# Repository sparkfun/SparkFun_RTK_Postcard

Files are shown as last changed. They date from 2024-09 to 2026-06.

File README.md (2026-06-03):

SparkFun RTK Postcard
========================================

SparkFun RTK Postcard (https://www.sparkfun.com/sparkfun-rtk-postcard.html)

[*SparkFun RTK Postcard (GPS-26916)*](https://www.sparkfun.com/sparkfun-rtk-postcard.html)

Designed and manufactured in Boulder, CO USA, the [SparkFun RTK Postcard](https://www.sparkfun.com/sparkfun-rtk-postcard.html) is a compact development board for your high-precision positioning and navigation needs. This board combines the Quectel LG290P GNSS RTK receiver with an Espressif ESP32-PICO-MINI-02 MCU module, running our latest [RTK Everywhere firmware](https://github.com/sparkfun/SparkFun_RTK_Everywhere_Firmware). The ESP32 provides the SparkFun Postcard with WiFi and Bluetooth&trade; connectivity to operate as an NTRIP caster or client. Meanwhile, the 4-pin locking JST-GH connector allows users to transmit or receive RTCMv3 messages for RTK corrections from a local base station.

- The LG290P module is a quad-band, multi-constellation, high-precision, RTK GNSS receiver. The module can simultaneously receive signals from the `L1`, `L2`, `L5`, and `L6`/`E6` frequency bands of the GPS, GLONASS, Galileo, BDS, QZSS, and NavIC GNSS constellations. In addition, the module supports SBAS augmentation systems (WASS, EGNOS, BDSBAS, MSAS, GAGAN, and SDCM), PPP services* (BDS PPP-B2b, QZSS CLAS, MADOCA-PPP, and Galileo HAS), RTCM, and RTK corrections for precision navigation with a fast convergence time and reliable performance. Connect with ease using a variety of interfaces, including UART, SPI*, and I2C*. 

- The ESP32-PICO-MINI-02 is a powerful MCU module with WiFi, Bluetooth&trade;, and BLE connectivity and comes integrated with 8MB SPI flash, 2MB SPI Pseudo static RAM (PSRAM), and a 40 MHz crystal oscillator. The ESP32 microcontroller itself features two CPU cores that can be individually controlled, with an adjustable clock frequency between 80 - 240MHz and a low-power co-processor for minor tasks, such as monitoring peripherals. It supports a range of peripherals including an SD card interface, capacitive touch sensors, ADC, DAC, Two-Wire Automotive Interface (TWAI), Ethernet, high-speed SPI, UART, I2S, I2C, etc.

With the [RTK Everywhere firmware](https://github.com/sparkfun/SparkFun_RTK_Everywhere_Firmware) that comes pre-loaded, users can seamlessly operate the RTK Postcard as a base station or rover. These modes also offer additional functions, based on the available, wireless communication options:

- The RTK Postcard can transmit or receive RTCMv3 messages locally by connecting one of our [SiK Telemetry radios](https://www.sparkfun.com/sik-telemetry-radio-v3-915mhz-100mw.html).
- Through WiFi or Bluetooth&trade;, the RTK Postcard can also function as an NTRIP caster or client.
- The RTK Postcard can transmit NMEA messages to a [graphical information software (GIS)](https://docs.sparkfun.com/SparkFun_RTK_Everywhere_Firmware/gis_software_android/) apps on any mobile device when paired as a Bluetooth&trade; device.

In addition to the RTK Postcard, we created the [Portability Shield](https://www.sparkfun.com/sparkfun-portability-shield.html) for the convenience of users. Simply connecting these products, provides a 1.3” OLED display and a five-way button to navigate the configuration settings and display PNT data; a microSD card slot for data logging; and a LiPo battery charger with a fuel gauge to take the RTK Postcard *"on-the-go"*. All of these will operate plug-and-play without the need for new code.

> [!NOTE]
> The [RTK Everywhere firmware](https://github.com/sparkfun/SparkFun_RTK_Everywhere_Firmware) is open-source, so users can obtain, check, and even modify the device's functionality. This allows for easier feature expansion, bug maintenance, and longer device longevity.

> [!NOTE]
> `*`: Feature is still under development

> [!IMPORTANT]
> - Currently, only the UART interface is supported by the LG290P module.
> - Additionally, the corrections for some of the PPP services may not be implemented yet.

Documentation
--------------

* **[Hookup Guide (mkdocs)](http://docs.sparkfun.com/SparkFun_RTK_Postcard/)** - The hookup guide for the SparkFun RTK Postcard hosted by GitHub pages.<br>
   
* [User Manual - RTK Everywhere Firmware](https://docs.sparkfun.com/SparkFun_RTK_Everywhere_Firmware/) - Documentation for the [RTK Everywhere firmware](https://github.com/sparkfun/SparkFun_RTK_Everywhere_Firmware)
* [SparkFun LG290P GNSS Arduino Library](https://github.com/sparkfun/SparkFun_LG290P_GNSS_Arduino_Library) - An Arduino library for the LG290P and LGx80P GNSS modules

*Need to download or print our hookup guide?*

* [Print *(Print to PDF)* from Single-Page View](http://docs.sparkfun.com/SparkFun_RTK_Postcard/print_view)

Repository Contents
-------------------

* **[/docs](/docs/)** - Online documentation files
    * [assets](/docs/assets/) - Assets files
        * [3d_model](/docs/assets/3d_model/) - Files for the 3D models
            * [3D CAD Model](/docs/assets/3d_model/cad_model.step) (.step)
        * [board_files](/docs/assets/board_files/) - Files for the product design
            * [KiCad Design Files](/docs/assets/board_files/kicad_files.zip) (.zip)
            * [Schematic](/docs/assets/board_files/schematic.pdf) (.pdf)
            * [Dimensions](/docs/assets/board_files/dimensions.pdf) (.pdf)
        * [component_documentation](/docs/assets/component_documentation/) - Datasheets for hardware components
        * [img/hookup_guide/](/docs/assets/img/hookup_guide/) - Images for hookup guide documentation
* **[/Enclosure](/Enclosure/)** - CAD model for an enclosure
* **[/Hardware](/Hardware/)** - Hardware design files (.brd, .sch)
  * **[/Production](/Production/)** - Production files

Product Variants
----------------

- LG290P Variants
  - [GPS-26916](https://www.sparkfun.com/sparkfun-rtk-postcard.html) - v1.0, Initial Release
  - [GPS-26620](https://www.sparkfun.com/sparkfun-quadband-gnss-rtk-breakout-lg290p-qwiic.html) - SparkFun Quadband GNSS RTK Breakout - LG290P (Qwiic) *(w/o ESP32)*
- [GPS-28019](https://www.sparkfun.com/products/28019) - SparkFun Quadband GNSS RTK Breakout - LG580P (Qwiic)

Version History
---------------

* [v10](https://github.com/sparkfun/SparkFun_RTK_Postcard/releases/tag/v10) - Initial Release

License Information
-------------------

This product is ***open source***!

Please review the [`LICENSE.md`](./LICENSE.md) file for license information.

If you have any questions or concerns about licensing, please contact technical support on our [SparkFun forums](https://community.sparkfun.com/).

Distributed as-is; no warranty is given.

- Your friends at SparkFun.

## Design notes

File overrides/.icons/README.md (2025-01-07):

.icons directory
====================
This folder should contain branding logos for the product documentation

## General Images
- `sfe-logo.svg` - SparkFun flame logo
- `kicad-primary.svg` - Full KiCad logo

## Directory
- `logo` - Other available logos

## SVG Optimizer
- [Remove meta data from svg](https://jakearchibald.github.io/svgomg/)

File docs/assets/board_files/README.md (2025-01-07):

board_files directory
====================

1. A `dimensions.png` file containing the board's measurements.
2. A `schematic.pdf` file containing the board's schematics.
3. A `*_files.zip` file containing the hardware design files.
	- The file name is based on the CAD software used to design the hardware, as described below:
		- An `kicad_files.zip` file containing the KiCad design files.
		- A `kicad_files.zip` file containing the KiCad design files.
4. A `graphical_datasheet.pdf` containing a summary of the board's technical specifications.

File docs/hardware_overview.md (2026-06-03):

---
icon: material/cog
---

## :material-folder-cog: Design Files
The SparkFun RTK Postcard board's dimensions, pin layout, and connectors are similar to our very popular [SparkFun GPS-RTK-SMA Breakout - ZED-F9P (Qwiic)](https://www.sparkfun.com/sparkfun-gps-rtk-sma-breakout-zed-f9p-qwiic.html) and [SparkFun Quadband GNSS RTK Breakout - LG290P (Qwiic)](https://www.sparkfun.com/sparkfun-quadband-gnss-rtk-breakout-lg290p-qwiic.html). The board features multiple UART ports, which are accessible through the USB-C connector, [PTH](https://en.wikipedia.org/wiki/Through-hole_technology "Plated Through Holes") pins, and 4-pin locking JST connector. Users can also interface with the board through the 19 [PTH](https://en.wikipedia.org/wiki/Through-hole_technology "Plated Through Holes") pins that are broken out around the edge of the board. For the GNSS antenna, an SMA antenna connector is provided on the edge of the board; additionally, users can rework the board to utilize the u.fl connector instead. We also provide two 4-pin JST Qwiic connectors for future use, to operate the board as a peripheral device.

<!-- Import the component -->
<script type="module" src="https://ajax.googleapis.com/ajax/libs/model-viewer/3.5.0/model-viewer.min.js"></script>

<div class="grid cards desc" markdown>

-   :kicad-primary:{ .enlarge-logo } Design Files

	---

	- :fontawesome-solid-file-pdf: [Schematic](./assets/board_files/schematic.pdf)
	- :material-folder-zip: [KiCad Files](./assets/board_files/kicad_files.zip)
	- :material-rotate-3d: STEP Files
		- :material-developer-board: [RTK Postcard](./assets/3d_model/cad_model.step)
		- :material-cube-outline: [Enclosure](./assets/3d_model/enclosure/enclosure.step)
	<!-- - :material-rotate-3d: [STEP File](./assets/3d_model/cad_model.step) -->
	- :fontawesome-solid-file-pdf: [Board Dimensions](./assets/board_files/dimensions.pdf):
		- 1.70" x 1.70" (43.2mm x 43.2mm)
		- Four mounting holes:
			- 4-40 screw compatible

-   <!-- Boxes in tabs -->

	=== "3D Model"
		???+ example "RTK Postcard"
			<article style="text-align: center;" markdown>
			<model-viewer src="../assets/3d_model/web_model.glb" camera-controls poster="../assets/3d_model/poster.png" tone-mapping="neutral" shadow-intensity="1.3" exposure="0.85" shadow-softness="0.45" environment-image="legacy" camera-orbit="39.22deg 54.28deg 0.1361m" field-of-view="29deg" style="width: 100%; height: 450px;">
			</model-viewer>

			[Download the `*.step` File](./assets/3d_model/cad_model.step "Click download"){ .md-button .md-button--primary width="250px" }

			</article>

		??? example "Enclosure"
			<article style="text-align: center;" markdown>
			<model-viewer src="../assets/3d_model/enclosure/web_model.glb" camera-controls poster="../assets/3d_model/enclosure/poster.png" tone-mapping="neutral" shadow-intensity="0.9" environment-image="legacy" exposure="0.6" shadow-softness="0.7" camera-orbit="-756.1deg 62.5deg 140.1m" field-of-view="30deg" style="width: 100%; height: 450px;">
			</model-viewer>

			[Download the `*.step` File](./assets/3d_model/enclosure/enclosure.step "Click download"){ .md-button .md-button--primary width="250px" }

			</article>

		??? tip "Manipulate 3D Model"
			<article style="text-align: center;" markdown>

			| Controls       | Mouse                    | Touchscreen    |
			| :------------- | :----------------------: | :------------: |
			| Zoom           | Scroll Wheel             | 2-Finger Pinch |
			| Rotate         | ++"Left-Click"++ & Drag  | 1-Finger Drag  |
			| Move/Translate | ++"Right-Click"++ & Drag | 2-Finger Drag  |

			</article>

	=== "Dimensions"
		<article style="text-align: center;" markdown>
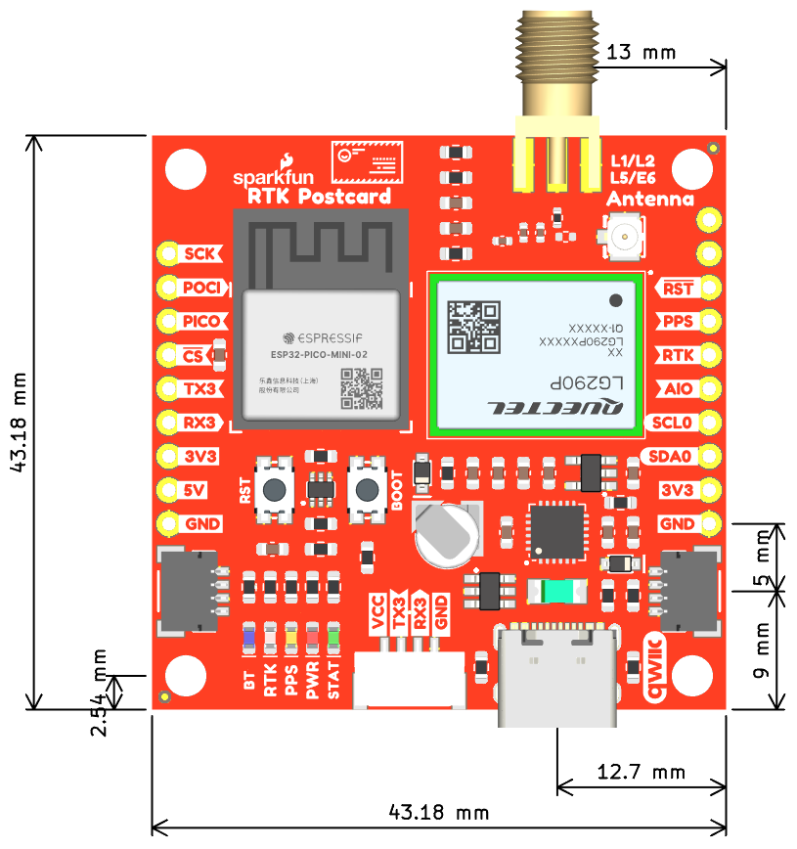
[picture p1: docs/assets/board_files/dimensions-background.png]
Board Dimensions
		
		<figcaption markdown>Dimensions of the RTK Postcard.</figcaption>
		</article>

		??? tip "Need more measurements?"
			For more information about the board's dimensions, users can download the [KiCad files](./assets/board_files/kicad_files.zip) for this board. These files can be opened in KiCad and additional measurements can be made with the measuring tool.

			!!! info ":octicons-download-16:{ .heart } KiCad - Free Download!"
				KiCad is free, open-source [CAD]("computer-aided design") program for electronics. Click on the button below to download their software. *(\*Users can find out more information about KiCad from their [website](https://www.kicad.org/).)*

				<article style="text-align: center;" markdown>
				[Download :kicad-primary:{ .enlarge-logo }](https://www.kicad.org/download/ "Go to downloads page"){ .md-button .md-button--primary width="250px" }
				</article>

			??? info ":straight_ruler: Measuring Tool"
				This video demonstrates how to utilize the dimensions tool in KiCad, to include additional measurements:

				<article class="video-500px" style="text-align: center; margin: auto;" markdown>
				<iframe src="https://www.youtube.com/embed/-eXuD8pkCYw" title="KiCad Dimension Tool" frameborder="0" allow="accelerometer; autoplay; clipboard-write; encrypted-media; gyroscope; picture-in-picture" allowfullscreen></iframe>
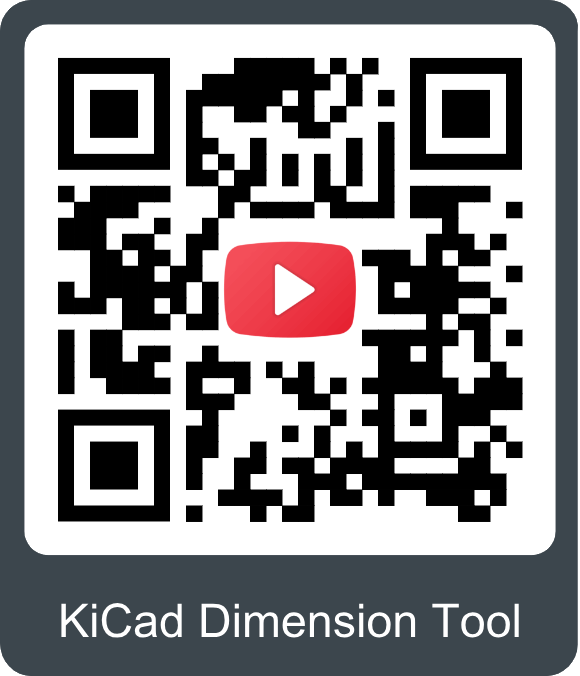
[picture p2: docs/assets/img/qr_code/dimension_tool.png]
QR code to play video
				
				</article>

</div>

## USB-C Connector
The USB connector is provided to power the board and communicate with either the LG290P GNSS receiver or ESP32 microcontroller. For most users, it will be the primary method for interfacing with the RL Postcard.

<figure markdown>
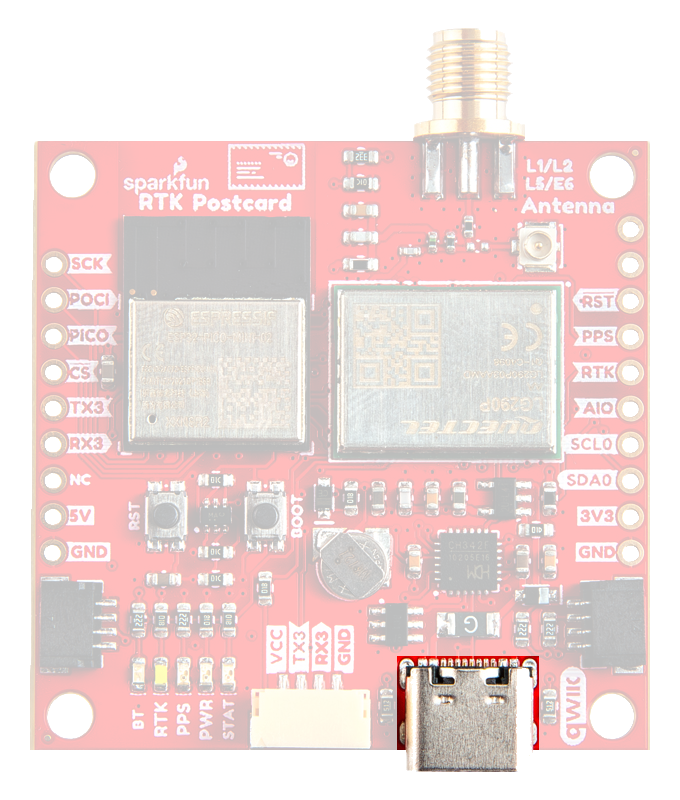
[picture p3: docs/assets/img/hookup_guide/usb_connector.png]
USB-C Connector

<figcaption markdown>USB-C connector on the RTK Postcard.</figcaption>
</figure>

### CH342 Dual UART Converter
The CH342 serial-to-USB converter allows users to interface with the `UART1` port of the LG290P GNSS module and `UART0` port of the ESP32-Pico module through the USB-C connector. To utilize the CH342, users may need to install a USB driver, which can be downloaded from the [manufacturer website](https://www.wch-ic.com/search?q=CH342&t=downloads).

??? tip "Tip - USB Drivers"
	<div class="grid cards" align="center" markdown>

	-   :material-microsoft-windows: **Windows**

		---

		[:octicons-download-16:{ .heart } Download Page for `CH343SER.EXE`](https://www.wch-ic.com/downloads/CH343SER_EXE.html){ .md-button .md-button--primary target="blank" }

	-   :material-apple: **MacOS**

		---

		[:octicons-download-16:{ .heart } Download Page for `CH341SER_MAC.ZIP`](https://www.wch-ic.com/downloads/CH34XSER_MAC_ZIP.html){ .md-button .md-button--primary target="blank" }

	</div>

	!!! info "Linux"
		A USB driver is not required for Linux based operating systems.

<figure markdown>
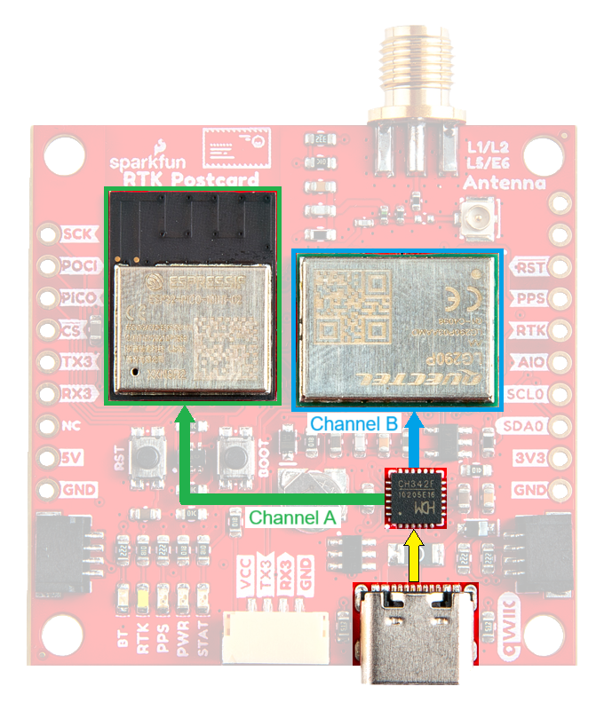
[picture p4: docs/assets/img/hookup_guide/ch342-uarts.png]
CH342 UART Channels

<figcaption markdown>The `UART` channels of the CH342 serial-to-USB converter.</figcaption>
</figure>

Once the USB driver is installed, two virtual `COM` ports will be emulated and can be utilized as standard `COM` ports to access the modules:

- **ESP32** - Users should select `COM` port labeled with `Channel A` *(often the lower enumeration)*.
- **LG290P** - Users should select `COM` port labeled with `Channel B` *(often the higher enumeration)*.

	???+ info "UART Settings"
		<div class="grid cards" markdown>

		- **ESP32**

			---

			With the [RTK Everywhere firmware](https://github.com/sparkfun/SparkFun_RTK_Everywhere_Firmware), the `UART0` port of the ESP32 is configured with the following settings:

			- Baudrate: **115200bps**
			- Data Bits: 8
			- Parity: No
			- Stop Bits: 1

		- **LG290P**

			---

			With the [RTK Everywhere firmware](https://github.com/sparkfun/SparkFun_RTK_Everywhere_Firmware), the `UART2` port of the LG290P is configured with the following settings:

			- Baudrate: **460800bps**
			- Data Bits: 8
			- Parity: No
			- Stop Bits: 1

			??? info "Default Configuration"
				The UART ports of the LG290P are configured with the following default settings:

				- Baudrate: **460800bps**
				- Data Bits: 8
				- Parity: No
				- Stop Bits: 1
				- Flow Control: None
				- Protocols:
					- `NMEA 0183`
					- `RTCM 3.x`

		</div>

## Power
The RTK Postcard only requires **3.3V** to power the board's primary components. The simplest method to power the board is through the USB-C connector. Alternatively, the board can also be powered through the other connectors and [PTH](https://en.wikipedia.org/wiki/Through-hole_technology "Plated Through Holes") pins.

<figure markdown>
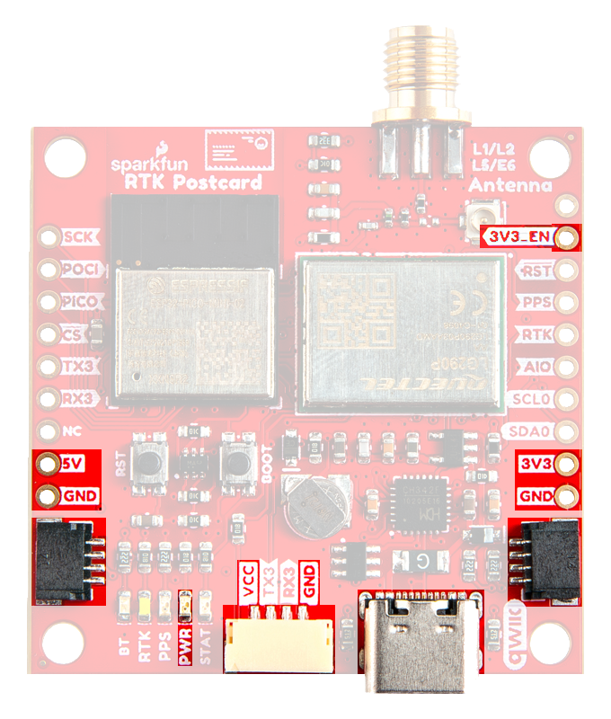
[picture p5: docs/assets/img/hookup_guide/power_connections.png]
Power connections

<figcaption markdown>RTK Postcard's power connections.</figcaption>
</figure>

Below, is a general summary of the power circuitry for the board:

<div class="annotate" markdown>

- **`5V`** - The voltage from the USB-C connector, usually **5V**.
	- Can be utilized as the primary power source for the entire board.
	- When connected to the [Portability Shield](https://www.sparkfun.com/sparkfun-portability-shield.html), this pin used to provide power between the boards. (1)
- **`3V3`** - 3.3V power rail, which powers the ESP32 Pico-Mini module, LG290P GNSS module, backup battery, and LEDs.
	- Power can also be distributed to/from any of the JST connectors *(Qwiic or `UART3`)* or the `3V3` PTH pin.
		- For power that is supplied through these connections, the LG290P has the tightest voltage supply requirement of **3.15–3.45V**.
	- A regulated **3.3V** is supplied by the [RT9080](./assets/component_documentation/DS9080.pdf), when powered from the `5V` PTH pin or USB connector
		- Input Voltage Range: **3.0 to 5.5V** (2)
		- The RT9080 LDO regulator can source up to 600mA.
- **`3V3_EN`** - Controls the power output form the RT9080 voltage regulator.
	- By default, the pin is pulled-up to 5V and to enable the RT9080 output voltage.
- **`VCC`** - The voltage from the locking JST-GH connector, which is controlled by the `VSEL` jumper (3).
	- Used to power an external radio to send or receive RTK corrections.
- **`GND`** - The common ground or the 0V reference for the voltage supplies.

</div>

1. !!! abstract "Details"

		When **5V** is provided to the RTK Postcard, it will supply power to the Portability Shield and charge the LiPo battery *(if connected)*. To operate properly when charging the battery, the power switch behind the OLED display of the Portability Shield should be in the `Off` position.

		When powered by a LiPo battery, users must toggle the power switch behind the OLED display of the Portability Shield to the `On` position. This will allow the battery power to be provided to the RTK Postcard through the **`5V`** pin; and then to its [RT9080 LDO](./assets/component_documentation/DS9080.pdf).

		Protection diodes are utilized on the boards to independently prevent current feedback and protect the power sources from each other.

1. !!! warning "Brown Out Voltage"

		The supply voltage of a LiPo battery will decrease as it is drained. However, before the battery can reach its critical UVLO threshold *(~2.8V)*, the LG290 GNSS module with begin to brown out from an in-use supply voltage of **3.05-3.10V** from a battery.

	!!! warning "Battery Capacity"

		When selecting a LiPo battery for any combination of the RTK Postcard, Portability Shield, and/or connected radio, users should be aware of the peak current draw of their setup. In theory, most standard LiPo batteries have a maximum discharge rate of 1C *(based on the battery capacity)*.

		$$
		1C = \frac{(1 * Capacity)}{hour}
		$$

		However, as a battery ages, users may find the effective capacity and discharge rate to degrade to 80% of its original specifications.

		!!! example

			For example, a LiPo battery with a **400mAh capacity** will have a maximum **discharge rate of 400mA**. However, over time, users may notice its effective use diminish to 320mAh and 320mA respectively.

1. By default, the `VSEL` jumper is configured to utilize the **3.3V** power rail; however, it can be connected to the 5V power rail instead.

	!!! warning "Portability Shield"

		When utilizing the 5V power rail of the RTK Postcard, power may be supplied from the LiPo battery from the Portability Shield. This should be taken into consideration when connecting an external radio for RTK corrections.

!!! info
	For more details, users can reference the [schematic](./assets/board_files/schematic.pdf) and the datasheets of the individual components on the board.

!!! tip "Portability Shield"
	When used in conjunction with the [Portability Shield](https://www.sparkfun.com/sparkfun-portability-shield.html), users should be aware of the following:

	- To charge the battery, users must provide adequate power through the `5V` pin. This is most easily done by powering the boards from the USB-C connector.
	- When operating the boards with the battery power, users must ensure that the switch behind the OLED display is in the `On` position. This will allow the battery power to feedback to the RTK Postcard through the `5V` pin; and over to the RT9080 LDO to provide a regulated 3.3V to its primary components.

### Backup Battery
While charged, the backup battery allows the GNSS module to hot/warm start with valid ephemeris data (time and GNSS orbital trajectories) that was stored.

**Time to First Fix:**

- Cold Start: 28s
- Warm Start: 28s
- Hot Start: 1.7s

## :espressif-logo:&nbsp; ESP32 Pico-Mini
The brains of the RTK Postcard is an [ESP32 Pico-Mini module](https://espressif.com/sites/default/files/documentation/esp32-pico-mini-02_datasheet_en.pdf). The Espressif series of ESP32 modules are a versatile, compact MCU modules with WiFi, BT, and BLE capabilities that target a wide variety of applications. At the core of the ESP32 Pico-Mini module is the ESP32-PICO-V3-02, a System-in-Package device, along with an integrated 8 MB SPI flash, 2 MB SPI PSRAM, and 40 MHz oscillator.

<figure markdown>
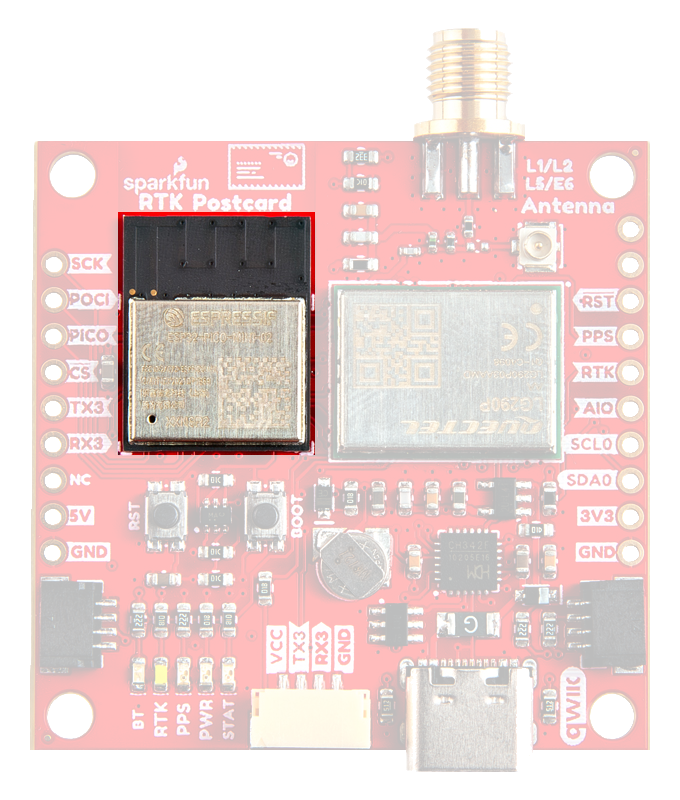
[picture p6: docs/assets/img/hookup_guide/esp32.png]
ESP32 Pico-Mini module

<figcaption markdown>The ESP32 Pico-Mini module on the RTK Postcard.</figcaption>
</figure>

??? info "General Features"
	<div class="grid" markdown>

	<div markdown>

	- Electrical Characteristics:
		- Operating Voltage: **3.0 - 3.6V**
		- Current Consumption:
			- RF Operation: 368mA *(peak)*
			- Normal Operation: 20-31mA
			- Light-Sleep: 0.8mA
			- Deep-Sleep: 5µA
	- Xtensa® Dual-Core 32-bit LX6 Microprocessor *(up to 240MHz)*
		- 448KB of ROM and 520KB SRAM
		- 8MB SPI Flash
		- 2MB PSRAM
		- 16KB SRAM in RTC
	- Operating Temperature: -40 to 85&deg;C

	</div>

	<div markdown>

	- PCB antenna
	- Wi­F 802.11b/g/n
		- Bit Rate: up to 150Mbps *(802.11n)*
		- Frequency Range: 2412 - 2484MHz
	- Bluetooth
		- Bluetooth v4.2 Specification:
			- BR/EDR
			- Bluetooth LE
		- Transmitter Class: 1, 2, and 3
	- 27 GPIO *(including strapping pins)*
		-
	- Supported Peripherals:
		- SD card, UART, SPI, SDIO, I2C, LED PWM, Motor PWM, I2S, IR, pulse counter, GPIO, capacitive touch sensor, ADC, DAC, TWAI® (compatible with ISO 11898-1, i.e. CAN Specification 2.0), Ethernet MAC

	</div>

	</div>

???+ warning
	Users should be aware of the following nuances and details of this microcontroller

	- The ESP32 Pico-Mini is only compatible with **2.4GHz WiFi** networks; it will not work on the 5GHz bands.
	- For details on the boot mode configuration, please refer to [section **3.3 Strapping Pins**](./assets/component_documentation/esp32_datasheet_en.pdf#8) of the ESP32 SoC datasheet.

???+ info "RTK Everywhere Firmware"
	The RTK Postcard comes pre-programmed with latest version of our [RTK Everywhere firmware](https://github.com/sparkfun/SparkFun_RTK_Everywhere_Firmware). However, users are free to reprogram the board as they see fit. For more details about the RTK Everywhere firmware, users can refer to the [user manual](http://docs.sparkfun.com/SparkFun_RTK_Everywhere_Firmware/).

???+ tip "Firmware Download Mode"
	Users can manually force the board into the <a href="https://docs.espressif.com/projects/esptool/en/latest/esp32/advanced-topics/boot-mode-selection.html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">serial bootloader</a> with the ++"BOOT"++ button. Please, refer to the [**Boot Button** section](#boot-button) below for more information.

??? info "Power Modes"
	The ESP32 Pico-Mini module has various power modes:

	- **Active** -  The chip radio is powered on. The chip can receive, transmit, or listen.
	- **Modem Sleep** - The CPU is operational and the clock is configurable. The Wi-Fi/Bluetooth	baseband and radio are disabled.
	- **Light Sleep** - The CPU is paused. The RTC memory and RTC peripherals, as well as the ULP	coprocessor are running.
	- **Deep Sleep** - Only the RTC memory and RTC peripherals are powered on. The ULP coprocessor is functional.
	- **Hibernation** - Only one RTC timer on the slow clock and certain RTC GPIO	active.
	- **Off** - Chip is powered off.

	*For more information on the power management of the ESP32 Pico-Mini module, pleaser refer to **Section 4.4** and **Tables: 8 and 9** of the [ESP32 Pico-Mini module datasheet](./assets/component_documentation/esp32-pico-mini-02_datasheet_en.pdf).*

### Peripherals and I/O Pins
The ESP32 Pico-Mini module features *27 multifunctional GPIO* pins, of which, **11 I/O pins** broken out into [PTH](https://en.wikipedia.org/wiki/Through-hole_technology "Plated Through Holes") pins on the RTK Postcard. Meanwhile, others are utilized to interface with the LG290P GNSS receiver or other components on the board *(i.e. USB connector, Qwiic connector, etc.)*. All of the RTK Postcard [PTH](https://en.wikipedia.org/wiki/Through-hole_technology "Plated Through Holes") pins have a .1" pitch spacing for standard headers and their pin layout is compatible with our [Portability Shield](https://www.sparkfun.com/sparkfun-portability-shield.html).

<div class="grid" markdown>

<div markdown>

<figure markdown>
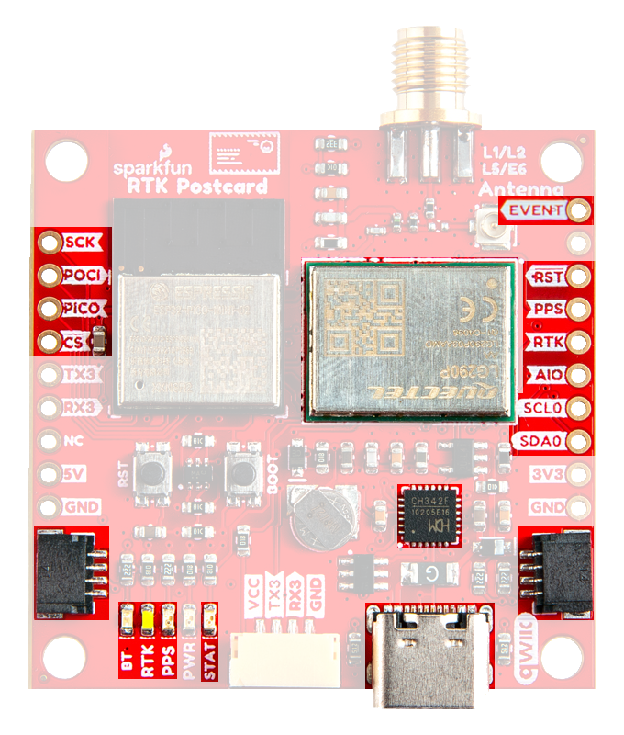
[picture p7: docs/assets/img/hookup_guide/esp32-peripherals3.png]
Peripherals interfaces

<figcaption markdown>The peripheral interfaces and I/O pins on the RTK Postcard.</figcaption>
</figure>

**Interfaces:**

- UART (x2)
- SPI
- I^2^C (x2)
- ~~Event Trigger[^4]~~
- RTK Signal
- Interrupt
- PPS Timing Signal
- LG290P Module Reset

</div>

<div markdown>

| ESP32 GPIO  | PTH Pin | LG290P IO  | Other |
| :---: | :-----: | :---: | :---: |
| `GPIO 7` | `SDA0`  | `I2C_SDA`  | |
| `GPIO 20` | `SCL0`  | `I2C_SCL`  | |
| `GPIO 13` | | | Qwiic `SDA` |
| `GPIO 19` | | | Qwiic `SCL` |
| `GPIO 21` | | `TXD2` | |
| `GPIO 22` | | `RXD2` | |
| `GPIO 33` | `RST` | `RESET_N`  | |
| `GPIO 34` | `RTK` | `RTK_STAT` | LED `RTK` |
| `GPIO 36` | `PPS` | `1PPS` | LED `PPS` |
| `GPIO 8` | `EVENT` | `EVENT` | |
| `GPIO 32` | `SCK` | | |
| `GPIO 25` | `POCI`  | | |
| `GPIO 26` | `PICO`  | | |
| `GPIO 27` | `CS` | | |
| `GPIO 14` | `AOI` | | |
| `GPIO 4` | | | LED `BT` |
| `GPIO 0` | | | LED `STAT`  |

</div>

</div>

??? info "General Capabilities"
	With the [pin multiplexing](https://docs.espressif.com/projects/arduino-esp32/en/latest/tutorials/io_mux.html?#id1) capabilities of the ESP32 SoC, various pins can have several functionalities. For more technical specifications on the **I/O** pins, please refer to the [ESP32 SoC datasheet](./assets/component_documentation/esp32_datasheet_en.pdf).

	- 18x 12-bit analog to digital converter (ADC) channels
	- 3x UARTs (only two are configured by default in the Arduino IDE, one UART is used for bootloading/debug)
	- 3x SPI (only one is configured by default in the Arduino IDE)
	- 2x I^2^C (only one is configured by default in the Arduino IDE)
	- 2x digital-to-analog converter (DAC) channels
	- 16x 20-bit PWM outputs
	- 10x Capacitive Touch Inputs

	!!! warning
		Users should be aware of the following nuances of the ESP32 Pico-Mini module:

		- &#9889; All the GPIO are **3.3V** pins.
			- The I/O pins are **not 5V-tolerant**! To interface with higher voltage components, a [**logic level adapter**](https://learn.sparkfun.com/tutorials/bi-directional-logic-level-converter-hookup-guide) is recommended.
		- &#9889;  There are electrical limitations to the amount of current that the ESP32 Pico-Mini module can sink or source. For more details, check out the [ESP32 Pico-Mini module datasheet](./assets/component_documentation/esp32-pico-mini-02_datasheet_en.pdf).
		- There are some limitations to the ADC performance, see the **Note** from the [**ADC Characteristics** section of the ESP32 SoC datasheet](./assets/component_documentation/esp32_datasheet_en.pdf).

??? arduino "Programming in Arduino"
	To program the ESP32 Pico-Mini module in the Arduino IDE, users should select the **ESP32** > **ESP32 Dev Module** from the Board Manager list. Users should also be aware that not all of the features, listed above, will be available in the Arduino IDE. When programming the module with the Arduino IDE, only the following features are available for the board:

	- Only one I^2^C bus is defined.
	- Only two UART interfaces are available.
		- **UART (USB):** `Serial`
		- **`RX`/`TX` Pins:** `Serial1`
	- Only one SPI bus is defined.

	*For the full capabilities of the ESP32, the Espressif IDF should be utilized.*

	!!! info "General Functions"
		For digital pins, users will need to declare the [**`pinMode()`** *(link)*](https://www.arduino.cc/reference/en/language/functions/digital-io/pinmode/) in the setup of their **sketch** (programs written in the Arduino IDE) for the pins used.

		<div class="grid cards" markdown>

		- **Input**

			---

			When configured properly, an **input** pin will be looking for a `HIGH` or `LOW` state. **Input** pins are *high impedance* and takes very little current to move the input pin from one state to another.

		- **Output**

			---

			When configured as an **output** the pin will be at a `HIGH` or `LOW` voltage. **Output** pins are *low impedance*; this means that they can provide a relatively substantial amount of current to other circuits.

		</div>

	!!! info "Additional Functions"
		There are several pins that have special functionality in addition to general **digital I/O**. These pins and their additional functions are listed in the tabs below. For more technical specifications on the **I/O** pins, you can refer to the [schematic](./assets/board_files/schematic.pdf), [ESP32 Pico-Mini module datasheet](./assets/component_documentation/esp32-pico-mini-02_datasheet_en.pdf), [ESP32 SoC datasheet](./assets/component_documentation/esp32_datasheet_en.pdf), and [documentation for the ESP32 Arduino core](https://docs.espressif.com/projects/arduino-esp32/en/latest/tutorials/io_mux.html?#peripherals).

		=== "Analog Pins"
			The ESP32 module provides a **12-bit ADC** input on eighteen of its I/O pins. This functionality is accessed in the Arduino IDE using the [`analogRead(pin)` function](https://www.arduino.cc/reference/en/language/functions/analog-io/analogread/). *(\*The available ADC pins are highlighted in the image below.)*

			<div class="grid" markdown>

			<div markdown>

			<figure markdown>
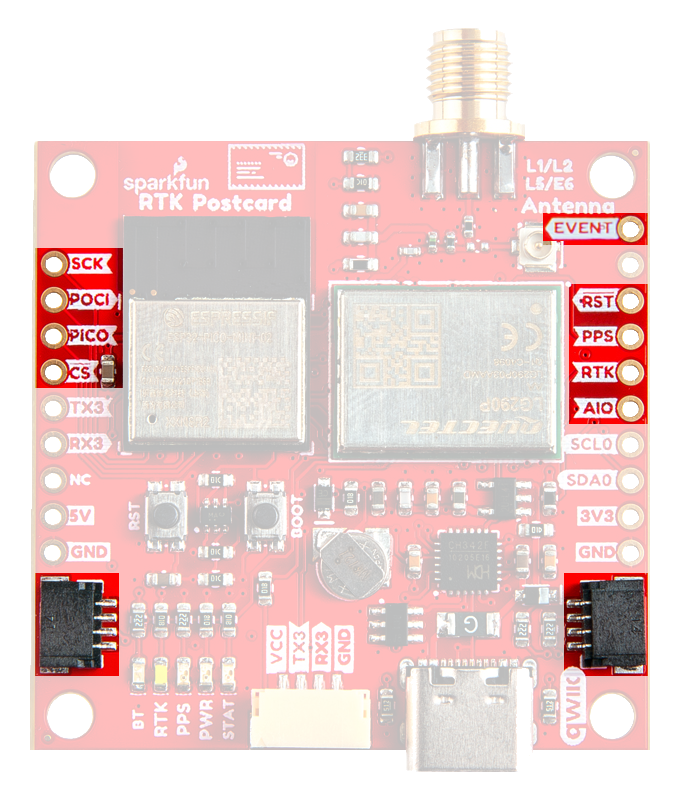
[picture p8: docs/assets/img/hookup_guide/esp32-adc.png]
Annotated image of analog inputs
			
			<figcaption markdown>Analog input pins on the RTK Postcard.</figcaption>
			</figure>

			</div>

			<div markdown>

			!!! tip
				To learn more about analog vs. digital signals, check out this great [tutorial](https://learn.sparkfun.com/tutorials/analog-vs-digital).

				<div class="grid cards" markdown align="center">

				-   <a href="https://learn.sparkfun.com/tutorials/89"><figure markdown>
					Analog vs. Digital
					</figure>

					---

					**Analog vs. Digital**</a>

				</div>

			</div>

			</div>

			!!! arduino
				By default, in the Arduino IDE, `analogRead()` returns a 10-bit value. To change the resolution of the value returned by the `analogRead()` function, use the [`analogReadResolution(bits)` function](https://www.arduino.cc/reference/en/language/functions/zero-due-mkr-family/analogreadresolution/).

		=== "PWM & Analog (DAC) Pins"
			The ESP32 module supports up to sixteen channels of **20-bit PWM** (Pulse Width Modulation) outputs on any of its I/O pins. This is accessed in the Arduino IDE using the [`analogWrite(pin, value)` function](https://www.arduino.cc/reference/en/language/functions/analog-io/analogwrite/). *(\*Any I/O pin can be used for the PWM outputs; the available DAC pins, with true analog outputs, are highlighted in the image below.)*

			<div class="grid" markdown>

			<div markdown>

			<figure markdown>
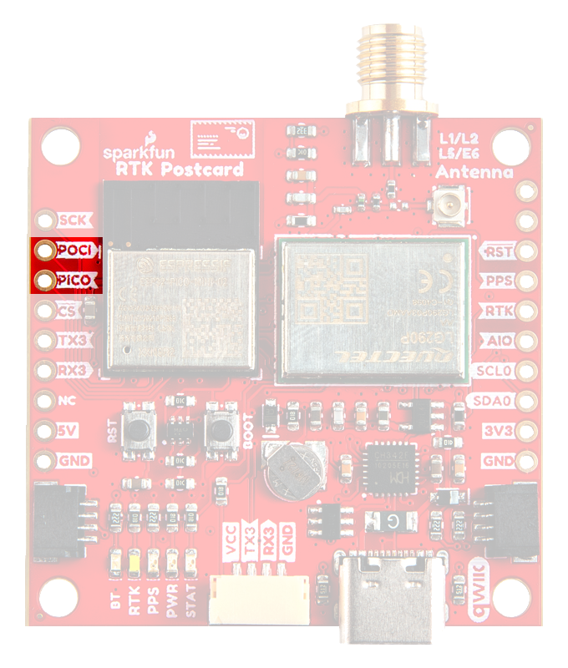
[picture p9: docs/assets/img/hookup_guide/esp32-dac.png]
Annotated image of DAC pins
			
			<figcaption markdown>Any I/O pin can be a PWM output, but these are the DAC pins on the RTK Postcard.</figcaption>
			</figure>

			</div>

			<div markdown>

			!!! tip
				To learn more about pulse width modulation (PWM), check out this great [tutorial](https://learn.sparkfun.com/tutorials/pulse-width-modulation).

				<div class="grid cards" markdown align="center">

				-   <a href="https://learn.sparkfun.com/tutorials/51"><figure markdown>
					Pulse Width Modulation
					</figure>

					---

					**Pulse Width Modulation**</a>

				</div>

			</div>

			</div>

			!!! arduino
				By default, in the Arduino IDE, `analogWrite()` accepts an 8-bit value. To change the resolution of the PWM signal for the `analogWrite()` function, use the [`analogWriteResolution(bits)` function](https://www.arduino.cc/reference/en/language/functions/zero-due-mkr-family/analogwriteresolution/).

		=== "Serial Pins"
			The ESP32 module provides three UART ports. By default, the UART port for the USB connection (`Serial`) and the UART port (`Serial1`) to the LG290P GNSS receiver can be accessed through the Arduino IDE using the [serial communication class](https://www.arduino.cc/reference/en/language/functions/communication/serial/).

			<div class="grid" markdown>

			<div markdown>

			<figure markdown>
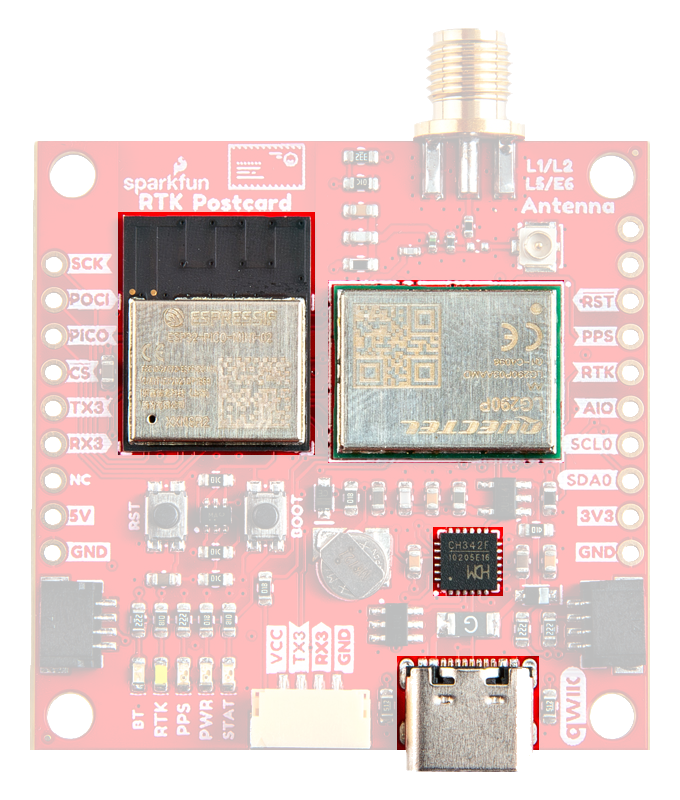
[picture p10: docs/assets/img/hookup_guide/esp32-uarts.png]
Annotated image of UART pins
			
			<figcaption markdown>Default UART ports on the RTK Postcard.</figcaption>
			</figure>

			</div>

			<div markdown>

			!!! tip
				To learn more about serial communication, check out this great [tutorial](https://learn.sparkfun.com/tutorials/serial-communication).

				<div class="grid cards" markdown align="center">

				-   <a href="https://learn.sparkfun.com/tutorials/8"><figure markdown>
					Serial Communication
					</figure>

					---

					**Serial Communication**</a>

				</div>

			</div>

			</div>

			!!! arduino
				By default, in the Arduino IDE, the **ESP32 Dev Module** board definition supports:

				- `Serial` - **UART (USB)**
				- `Serial1` - **Pins: `RX`/`TX` (`GPIO 21`/`GPIO 22`)**

			!!! tip
				We have noticed that with the ESP32 Arduino core, `Serial.available()` does not operate instantaneously. This is due to an interrupt triggered by the UART, to empty the FIFO when the **`RX`** pin is inactive for two byte periods:

				- At 9600 baud, `hwAvailable` takes about **11 ms** before the UART indicates that data was received from: `\r\nERROR\r\n`.

					$$
					(bytes + 2) * 1ms = 11ms
					$$

				- At 115200 baud, `hwAvailable` takes about **1 ms** before the UART indicates that data was received from: `\r\nERROR\r\n`.

					$$
					(bytes + 2) * .087ms = 1ms
					$$

				*For more information, please refer to this [chatroom discussion](https://gitter.im/espressif/arduino-esp32?at=5e25d6370a1cf54144909c85).*

		=== "SPI Pins"
			The ESP32 module provides three SPI buses. By default, in the Arduino IDE, the [SPI class](https://www.arduino.cc/en/reference/SPI) is configured to utilize pins `GPIO 32` (SCK), `GPIO 25` (POCI), `GPIO 26` (PICO), and `GPIO 27` (`SS`) for its chip select. In order to utilize the other SPI ports or objects, users will need to create a custom SPI object and declare which pins to access.

			<div class="grid" markdown>

			<div markdown>

			<figure markdown>
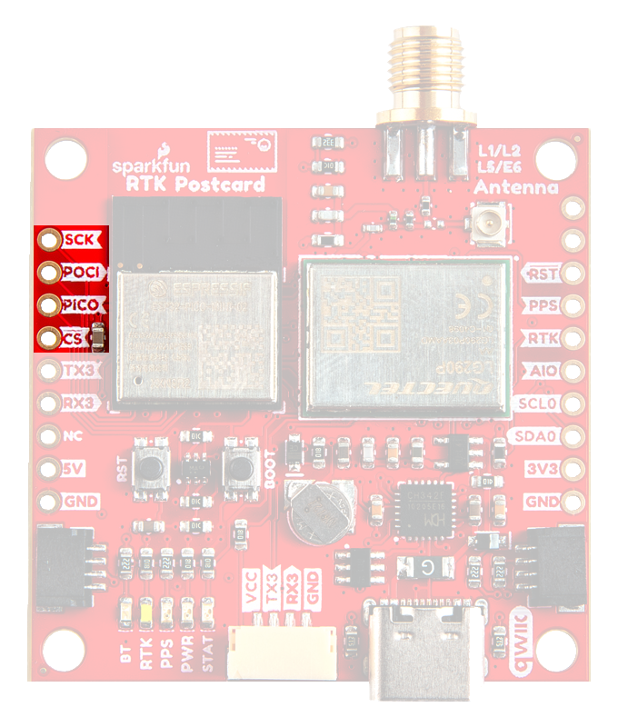
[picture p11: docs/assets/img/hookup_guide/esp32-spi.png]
Annotated image of SPI pins
			
			<figcaption markdown>Default SPI bus connections on the RTK Postcard.</figcaption>
			</figure>

			</div>

			<div markdown>

			!!! tip
				To learn more about the serial peripheral interface (SPI) protocol, check out this great [tutorial](https://learn.sparkfun.com/tutorials/serial-peripheral-interface-spi).

				<div class="grid cards" markdown align="center">

				-   <a href="https://learn.sparkfun.com/tutorials/16"><figure markdown>
					Serial Peripheral Interface (SPI)
					</figure>

					---

					**Serial Peripheral Interface (SPI)**</a>

				</div>

			</div>

			</div>

			!!! arduino
				By default, in the Arduino IDE, the **ESP32 Dev Module** board definition supports:

				<article style="text-align: center;" markdown>

				| **SCK**             | `GPIO 32` (`SCK`)  |
				| :-----------------: | :----------------: |
				| **SDI** or **POCI** | `GPIO 25` (`MISO`) |
				| **SDO** or **PICO** | `GPIO 26` (`MOSI`) |
				| *CS**               | `GPIO 27` (`SS`)   |

				</article>

			??? info "Signal Nomenclature"
				To comply with the latest [OSHW](https://www.oshwa.org/) design practices, we have [adopted the new SPI signal nomenclature](https://www.sparkfun.com/spi_signal_names) (**SDO**/**SDI** and **PICO**/**POCI**). The terms Master and Slave are now referred to as Controller and Peripheral. The `MOSI` signal on a controller has been replaced with `SDO` or `PICO`. Please refer to this [announcement on the decision to deprecate the **MOSI**/**MISO** terminology and transition to the **SDO**/**SDI** naming convention](https://www.oshwa.org/a-resolution-to-redefine-spi-signal-names).

		=== "I^2^C Pins"
			The ESP32 module module can support up to two I^2^C buses. By default, in the Arduino IDE, the [Wire class](https://www.arduino.cc/en/reference/wire) is configured to utilize pins `GPIO 20` (SDA) and `GPIO 7` (SCL). These pins share the same I^2^C bus with the LG290P GNSS receiver, but not the Qwiic connector. In order to utilize another I^2^C port, users will need to create a custom Wire object and declare which pins to access.

			<div class="grid" markdown>

			<div markdown>

			<figure markdown>
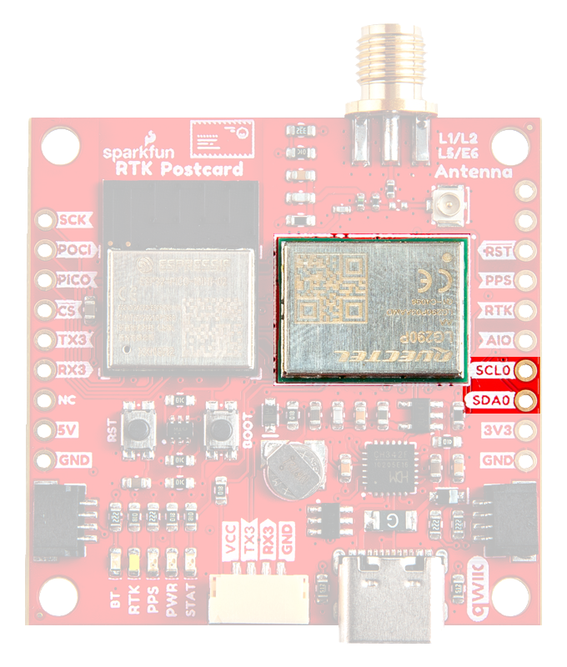
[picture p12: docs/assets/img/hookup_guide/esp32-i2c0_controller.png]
Annotated image of I2C pins
			
			<figcaption markdown>Default I^2^C bus connections for the RTK Postcard.</figcaption>
			</figure>

			</div>

			<div markdown>

			!!! tip
				To learn more about the inter-integrated circuit (I^2^C) protocol, check out this great [tutorial](https://learn.sparkfun.com/tutorials/i2c).

				<div class="grid cards" markdown align="center">

				-   <a href="https://learn.sparkfun.com/tutorials/82"><figure markdown>
					I2C
					</figure>

					---

					**I2C**</a>

				</div>

			</div>

			</div>

			!!! arduino
				By default, in the Arduino IDE, the **ESP32 Dev Module** board definition supports:

				<article style="text-align: center;" markdown>

				| **SCL0** | `GPIO 7` (`SCL`)  |
				| :------: | :---------------: |
				| **SDA0** | `GPIO 20` (`SDA`) |

				</article>

## :quectel-logo:&nbsp; LG290P GNSS
The centerpiece of the RTK Postcard, is the [LG290P GNSS module](./assets/component_documentation/quectel_lg290p03_hardware_design_v1-1.pdf) from [Quectel](https://www.quectel.com/). The LG290P is a low-power, multi-band, multi-constellation GNSS receiver capable of delivering centimeter-level precision at high update rates. The built-in NIC anti-jamming unit provides professional-grade interference signal detection and elimination algorithms, which effectively mitigate against multiple narrow-band interference sources and significantly improves the signal reception performance in complex electromagnetic environments. With its performance advantages of high-precision and power consumption, this board is an ideal choice for high-precision navigation applications, such as intelligent robots, UAVs, precision agriculture, mining, surveying, and autonomous navigation.

<div class="grid" markdown>

<div markdown>

<figure markdown>
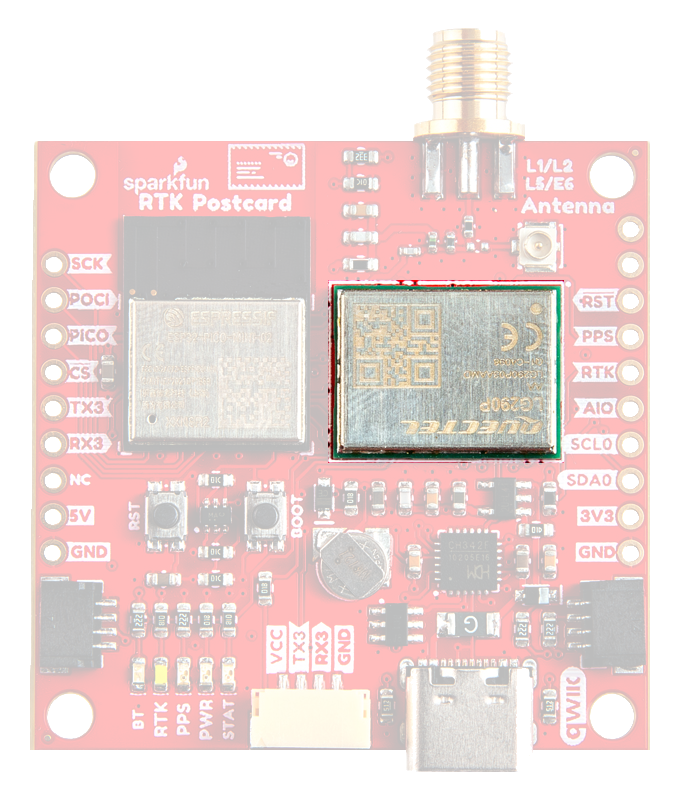
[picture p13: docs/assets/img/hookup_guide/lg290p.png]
LG290P GNSS module

<figcaption markdown>The LG290P module on the RTK Postcard.</figcaption>
</figure>

</div>

<div markdown>

<article class="video-500px" style="text-align: center; margin: auto;" markdown>
<iframe src="https://player.vimeo.com/video/1000742664?dnt=1&amp;app_id=122963" title="Quectel: Product Intro for LG290P GNSS Module" frameborder="0" allow="accelerometer; autoplay; clipboard-write; encrypted-media; gyroscope; picture-in-picture" allowfullscreen></iframe>
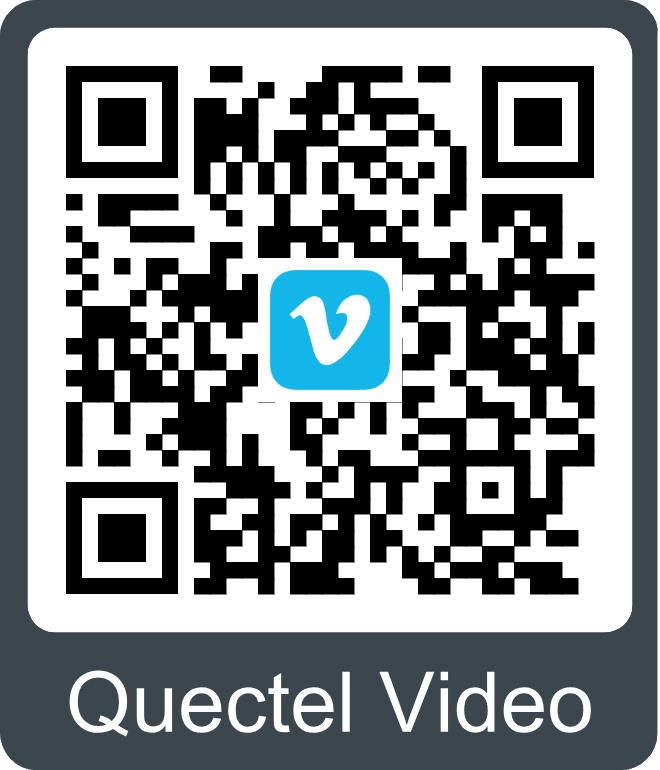
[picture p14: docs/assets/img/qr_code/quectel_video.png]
QR code to product video

</article>

</div>

</div>

??? info "General Features"
	<div class="grid" markdown>

	<div markdown>

	- Supply Voltage: **3.15 – 3.45V**
	- Tracking Channels: 1040
	- Concurrent signal reception: 5 + QZSS
		- `L1`, `L2`, `L5`, `E6` frequency bands
	- Sensitivity:
		- Acquisition: -146dBm
		- Tracking: -160dBm
		- Reacquisition: -155dBm
	- Antenna Power: External or Internal
	- GNSS Constellations and SBAS Systems:
		- **USA:** GPS + WASS
		- **Russia:** GLONASS + SDCM
		- **EU:** Galileo + EGNOS
		- **China:** BDS + BDSDAS
		- **Japan:** QZSS + MSAS
		- **India:** NavIC + GAGAN
	- Accuracy of 1PPS Signal: 5ns *(RMS)*
	- Update Rate:
		- Default: 10Hz
		- Max: 20Hz

	</div>

	<div markdown>

	- Time to First Fix *(without AGNSS)*:
		- Cold Start: 28s
		- Warm Start: 28s
		- Hot Start: 1.7s
	- RTK Convergence Time: 5s
	- Dynamic Performance:
		- Maximum Altitude: 10000m
		- Maximum Velocity: 490m/s
		- Maximum Acceleration: 4g
	- Built-in NIC anti-jamming unit
	- Interfaces
		- UART (x3)
			- Baud Rate: 9600–3000000bps
				- **Default:** 460800bps
			- Protocol: `NMEA 0183`/`RTCM 3.x`
		- SPI[^1] (x1)
		- I^2^C[^1] (x1)
	- Operating temperature: -40&deg;C to +85&deg;C
	- Footprint: 12.2mm × 16mm × 2.6mm
	- Weight: ~0.9g

	</div>

	</div>

	[^1]:
		!!! warning "Feature Under Development"
			Currently, only the UART interface is supported by the module. Support for the **I^2^C** and **SPI** interfaces are still under development.

??? info "Supported Frequency Bands"
	The LG290P modules are multi-band, multi-constellation GNSS receivers. Below, is a chart illustrating the frequency bands utilized by all the global navigation satellite systems; along with a list of the frequency bands and GNSS systems supported by the LG290P GNSS module.

	<figure markdown>
	GNSS frequency bands (https://www.tallysman.com/app/uploads/2021/07/Tallysman-GNSS-Frequencies-v8.0_Chart-1-1024x425.png "Click to enlarge")
	<figcaption markdown>Frequency bands of the global navigation satellite systems. (Source: [Tallysman](https://www.tallysman.com/gnss-constellations-radio-frequencies-and-signals/))</figcaption>
	</figure>

	<div class="grid" markdown>

	<div markdown>

	**Supported Frequency Bands:**

	- GPS: `L1 C/A`, `L1C`[^2], `L5`, `L2C`
	- GLONASS: `L1`, `L2`
	- Galileo: `E1`, `E5a`, `E5b`, `E6`
	- BDS: `B1I`, `B1C`, `B2a`, `B2b`, `B2I`, `B3I`
	- QZSS: `L1 C/A`, `L1C`[^2], `L5`, `L2C`
	- NavIC: `L5`
	- SBAS: `L1 C/A`
	- L-band PPP[^3]:
		- PPP: `B2b`
		- QZSS: `L6`
		- Galileo HAS: `E6`

	</div>

	<div markdown>

	**Supported GNSS Constellations:**

	- GPS (USA)
	- GLONASS (Russia)
	- Galileo (EU)
	- BDS (China)
	- QZSS (Japan)
	- NavIC (India)

	**Supported SBAS Systems:**

	- WASS (USA)
	- SDCM (Russia)
	- EGNOS (EU)
	- BDSBAS (China)
	- MSAS (Japan)
	- GAGAN (India)

	</div>

	</div>

	[^2]:
		!!! warning "Feature Under Development"
			Support for the `L1C` frequency band has not been implemented.
	[^3]:
		!!! warning "Feature Under Development"
			Corrections for some of the PPP services have not been implemented.

	!!! info
		For a comparison of the frequency bands supported by the LG290P GNSS modules, refer to sections **1.2**, **1.5**, and **1.6** of the [hardware design manual](./assets/component_documentation/quectel_lg290p03_hardware_design_v1-1.pdf).

	??? tip "What are Frequency Bands?"
		A [frequency band](https://en.wikipedia.org/wiki/Frequency_band) is a section of the [electromagnetic spectrum](https://en.wikipedia.org/wiki/Electromagnetic_spectrum), usually denoted by the range of its upper and lower limits. In the [radio spectrum](https://en.wikipedia.org/wiki/Radio_spectrum), these frequency bands are usually regulated by region, often through a government entity. This regulation prevents the interference of RF communication; and often includes major penalties for any interference with critical infrastructure systems and emergency services.

		<figure markdown>
		GNSS frequency bands (https://gssc.esa.int/navipedia/images/c/cf/GNSS_All_Signals.png "Click to enlarge")
		<figcaption markdown>Frequency bands of the global navigation satellite systems. (Source: [ESA](https://gssc.esa.int/navipedia/index.php?title=File:GNSS_All_Signals.png "European Space Agency"))</figcaption>
		</figure>

		However, if the various GNSS constellations share similar frequency bands, then how do they avoid interfering with one another? Without going too far into detail, the image above helps illustrate some of the characteristics, specific to the frequency bands of each system. With these characteristics in mind, along with other factors, the chart can help users to visualize how multiple GNSS constellations might co-exist with each other.

		For more information, users may find these articles of interest:

		- [GNSS signal](https://gssc.esa.int/navipedia/index.php/GNSS_signal)
		- [GPS Signal Plan](https://gssc.esa.int/navipedia/index.php?title=GPS_Signal_Plan)
		- [GLONASS Signal Plan](https://gssc.esa.int/navipedia/index.php?title=GLONASS_Signal_Plan)
		- [GALILEO Signal Plan](https://gssc.esa.int/navipedia/index.php?title=GALILEO_Signal_Plan)

??? tip "GNSS Accuracy"
	The accuracy of the position reported from the LG290P GNSS module, can be improved based upon the correction method being employed. Currently, [RTK](https://en.wikipedia.org/wiki/	Real-time_kinematic_positioning "Real-Time Kinematic") corrections provide the highest level of accuracy; however, users should be aware of certain limitations of the system:

	- RTK technique requires real-time correction data from a reference station or network of base stations.
		- RTK corrections usually come from RTCM messages that are signal specific *(i.e. an RTK network may only provide corrections for specific signals; only `E5b` and not `E5a`)*.
	- The range of the base stations will vary based upon the method used to transmit the correction data.
	- The reliability of RTK corrections are inherently reduced in [multipath environments](https://en.wikipedia.org/wiki/Multipath_propagation).

	<article style="text-align: center;" markdown>

	| Correction Method                                                                             | Horizontal                   | Vertical                | Velocity                                |
	| :-------------------------------------------------------------------------------------------- | :--------------------------: | :---------------------: | :-------------------------------------: |
	| Standalone                                                                                    | 0.7m<br>~2.3'                | 2.5m<br>~8.2'           | 3cm/s (0.108kph)<br>~1.2in/s (0.067mph) |
	| [RTK](https://en.wikipedia.org/wiki/Real-time_kinematic_positioning "Real-Time Kinematic")    | **0.8cm** *(+1ppm)*<br>~0.3" | 1.5cm *(+1ppm)*<br>~.6" |                                         |

	</article>

	??? info "RTK Corrections"
		To understand how RTK works, users will need a more fundamental understanding of the signal error sources.

		<div class="grid cards" markdown align="center">

		-   <a href="https://www.sparkfun.com/news/7533">
			<figure markdown>
			Tutorial Thumbnail
			</figure>

			---

			**Real-Time Kinematics Explained**</a>

		-   <a href="https://www.sparkfun.com/news/7138">
			<figure markdown>
			Tutorial Thumbnail
			</figure>

			---

			**What is Correction Data?**</a>

		</div>

### Peripherals and I/O Pins
The LG290P GNSS features several peripheral interfaces and I/O pins. Some of these are broken out as [PTH](https://en.wikipedia.org/wiki/Through-hole_technology "Plated Through Holes") pins on the RTK Postcard; whereas, others are broken out to their specific interface *(i.e. USB connector, JST connector, etc.)*. Additionally, some of their connections are tied to other components on the board.

<div class="grid" markdown>

<div markdown>

<figure markdown>
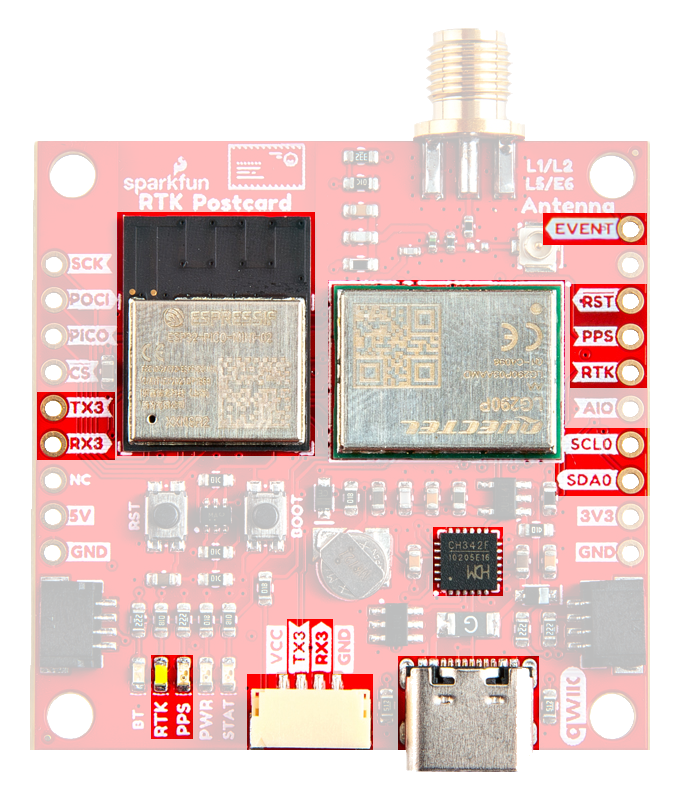
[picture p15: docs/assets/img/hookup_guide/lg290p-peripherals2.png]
Peripherals interfaces

<figcaption markdown>The peripheral interfaces and I/O pins on the RTK Postcard.</figcaption>
</figure>

</div>

<div markdown>
**Interfaces:**

- UART (x3)
- ~~SPI[^1]~~
- ~~I^2^C[^1]~~
- ~~Event Trigger[^4]~~
- Timing Signal
- RTK Signal
- Module Reset

[^4]:
	!!! warning "Feature Under Development"
		The event trigger has not been implemented.

</div>

</div>

=== "UARTs"
	The LG290P GNSS has three UART ports, which can be operated and configured separately.

	<div class="grid" markdown>

	<div markdown>

	<figure markdown>
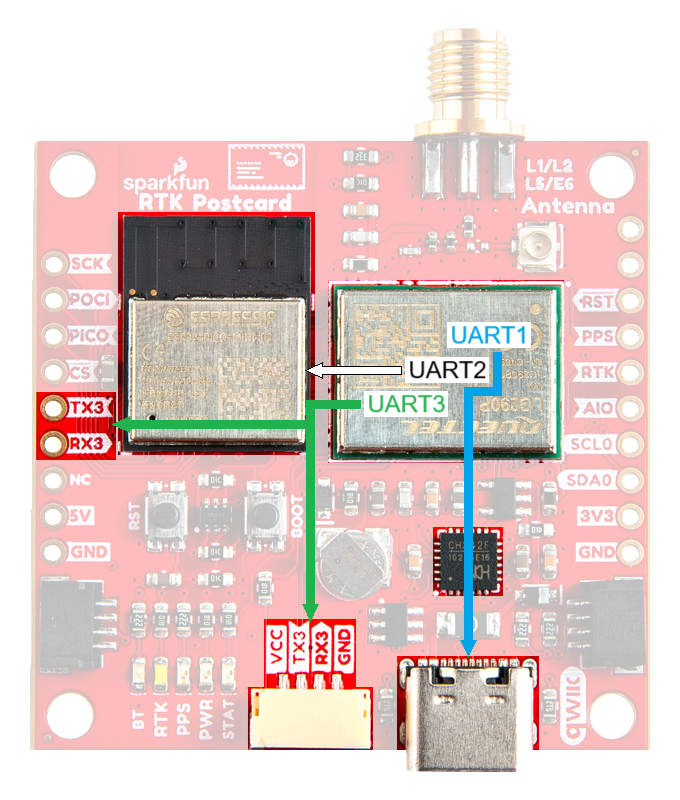
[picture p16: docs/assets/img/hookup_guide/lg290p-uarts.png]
UART interface
	
	<figcaption markdown>The UART ports on the RTK Postcard.</figcaption>
	</figure>

	</div>

	<div markdown>

	???+ info "UART Settings"
		With the [RTK Everywhere firmware](https://github.com/sparkfun/SparkFun_RTK_Everywhere_Firmware), the UART ports of the LG290P are configured with the following baudrates:

		<article style="text-align: center;" markdown>

		| UART Port | Interface          | Baudrate *(bps)* |
		| :-------: | :----------------- | :--------------: |
		| `UART1`   | USB-C *(CH342)*    | **460800**       |
		| `UART2`   | ESP32              | **460800**       |
		| `UART3`   | JST-GH *(Locking)* | **57600**        |

		</article>

	??? info "Default Configuration"
		The UART ports of the LG290P are configured with the following default settings:

		- Baudrate: **460800bps**
		- Data Bits: 8
		- Parity: No
		- Stop Bits: 1
		- Flow Control: None
		- Protocols:
			- `NMEA 0183`
			- `RTCM 3.x`

	??? tip "Pin Connections"
		When connecting to the board's UART pins to another device, the pins should be connected based upon the flow of their data.

		<article style="text-align: center;" markdown>

		<table>
		<tr>
		<th>Board</th>
		<td align="center">RX</td>
		<td align="center">TX</td>
		<td align="center">GND</td>
		</tr>
		<tr>
		<th>UART Device</th>
		<td align="center">TX</td>
		<td align="center">RX</td>
		<td align="center">GND</td>
		</tr>
		</table>

		</article>

	</div>

	</div>

	=== "`UART1`"
		<div class="annotate" markdown>

		`UART1` can only be accessed from the USB-C connector, through the CH342 serial-to-USB converter. For Windows and MacOS computers (1), a [USB driver must be installed](#ch342-dual-uart-converter) in order to communicate with the LG290P module through the CH342 converter. Once the USB driver is installed:

		- Two virtual `COM` ports are emulated, which can be used as standard `COM` ports to access the ESP32 or the LG290P modules.
		- Users should select `COM` port listed as `Channel B` to access the LG290P GNSS receiver.

		</div>

		1. On Linux, the standard Linux CDC-ACM driver is suitable.

	=== "`UART2`"
		`UART2` is connected to the ESP32 Pico-Mini.

		<article style="text-align: center;" markdown>

		| ESP32               | LG290P |
		| :-----------------: | :----: |
		| **IO21:** `GPIO 21` | `TXD2` |
		| **IO22:** `GPIO 22` | `RXD2` |

		</article>

	=== "`UART3`"
		`UART3` is available through the breakout [PTH](https://en.wikipedia.org/wiki/Through-hole_technology "Plated Through Holes") pins or the locking JST connector. The pin layout of the 4-pin locking JST connector is compatible with many of our [serial radios and adapter cables](../hardware_assembly/#radio-transceivers).

	??? info "UART Protocols"
		#### UART Protocols
		By default, these UART ports are configured to transmit and receive `NMEA 0183` and/or `RTCM 3.x` messages. These messages are generally used for transmitting PNT data; and providing or receiving RTK corrections, respectively. Quectel also implements a system of proprietary messages (`PQTM`) for users to configure the LG290P that follows a data format similar to the `NMEA` protocol. The expected structure of these proprietary messages is shown below:

		<figure markdown>
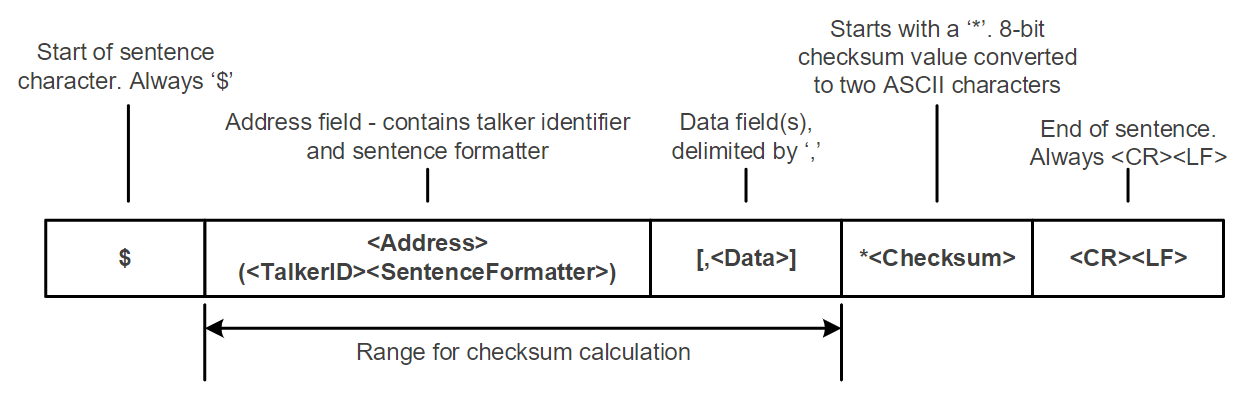
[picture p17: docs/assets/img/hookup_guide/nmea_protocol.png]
NMEA data structure
		
		<figcaption markdown>The data structure of Quectel messages for the `NMEA` protocol.</figcaption>
		</figure>

		=== "NMEA"
			A full list of compatible `NMEA 0183` v4.11 messages, is provided in section **2.2. Standard Messages** of the [GNSS Protocol Specification](./assets/component_documentation/quectel_lg290p03lgx80p03_gnss_protocol_specification_v1-1.pdf) manual. This protocol is used for outputting GNSS data, as detailed by the [National Marine Electronics Association](https://www.nmea.org/) organization.

			??? abstract "List of Standard NMEA Messages"
				<article style="text-align: center;" markdown>

				| Message | Type Mode | Message Description               |
				| :-----: | :-------: | :-------------------------------- |
				| RMC | Output | Recommended Minimum Specific GNSS Data   |
				| GGA | Output | Global Positioning System Fix Data       |
				| GSV | Output | GNSS Satellites in View                  |
				| GSA | Output | GNSS DOP and Active Satellites           |
				| VTG | Output | Course Over Ground & Ground Speed        |
				| GLL | Output | Geographic Position – Latitude/Longitude |

				</article>

		=== "PQTM"
			A full list of PQTM messages (proprietary NMEA messages defined by Quectel) supported by LG290P, is provided in section **2.3. PQTM Messages** of the [GNSS Protocol Specification](./assets/component_documentation/quectel_lg290p03lgx80p03_gnss_protocol_specification_v1-1.pdf) manual. This protocol is used to configure or read the settings for the LG290P GNSS module.

			??? abstract "List of Proprietary Quectel Messages"
				<article style="text-align: center;" markdown>

				| Message            | Type Mode    | Message Description                              |
				| :----------------- | :----------: | :----------------------------------------------- |
				| PQTMVER            | Output       | Outputs the firmware version                     |
				| PQTMCOLD           | Input        | Performs a cold start                            |
				| PQTMWARM           | Input        | Performs a warm start                            |
				| PQTMHOT            | Input        | Performs a hot start                             |
				| PQTMSRR            | Input        | Performs a system reset and reboots the receiver |
				| PQTMUNIQID         | Output       | Queries the module unique ID                     |
				| PQTMSAVEPAR        | Input        | Saves the configurations into NVM                |
				| PQTMRESTOREPAR     | Input        | Restores the parameters configured by all commands to their default values |
				| PQTMVERNO          | Output       | Queries the firmware version                     |
				| PQTMCFGUART        | Input/Output | Sets/gets the UART interface                     |
				| PQTMCFGPPS         | Input/Output | Sets/gets the PPS feature                        |
				| PQTMCFGPROT        | Input/Output | Sets/gets the input and output protocol for a specified port |
				| PQTMCFGNMEADP      | Input/Output | Sets/gets the decimal places of standard NMEA messages |
				| PQTMEPE            | Output       | Outputs the estimated position error             |
				| PQTMCFGMSGRATE     | Input/Output | Sets/gets the message output rate on the current interface |
				| PQTMVEL            | Output       | Outputs the velocity information                 |
				| PQTMCFGGEOFENCE    | Input/Output | Sets/gets geofence feature                       |
				| PQTMGEOFENCESTATUS | Output       | Outputs the geofence status                      |
				| PQTMGNSSSTART      | Input        | Starts GNSS engine                               |
				| PQTMGNSSSTOP       | Input        | Stops GNSS engine                                |
				| PQTMTXT            | Output       | Outputs short text messages                      |
				| PQTMCFGSVIN        | Input/Output | Sets/gets the Survey-in feature                  |
				| PQTMSVINSTATUS     | Output       | Outputs the Survey-in status                     |
				| PQTMPVT            | Output       | Outputs the PVT (GNSS only) result               |
				| PQTMCFGRCVRMODE    | Input/Output | Sets/gets the receiver working mode              |
				| PQTMDEBUGON        | Input        | Enables debug log output                         |
				| PQTMDEBUGOFF       | Input        | Disables debug log output                        |
				| PQTMCFGFIXRATE     | Input/Output | Sets/gets the fix interval                       |
				| PQTMCFGRTK         | Input/Output | Sets/gets the RTK mode                           |
				| PQTMCFGCNST        | Input/Output | Sets/gets the constellation configuration        |
				| PQTMDOP            | Output       | Outputs dilution of precision                    |
				| PQTMPL             | Output       | Outputs protection level information             |
				| PQTMCFGODO         | Input/Output | Sets/gets the odometer feature                   |
				| PQTMRESETODO       | Input        | Resets the accumulated distance recorded by the odometer |
				| PQTMODO            | Output       | Outputs the odometer information                 |
				| PQTMCFGSIGNAL      | Input/Output | Sets/gets GNSS signal mask                       |
				| PQTMCFGSAT         | Input/Output | Sets/gets GNSS satellite mask                    |
				| PQTMCFGRSID        | Input/Output | Sets/gets the reference station ID               |
				| PQTMCFGRTCM        | Input/Output | Sets/gets RTCM                                   |

				</article>

		=== "RTCM"
			A full list of compatible `RTCM v3` messages, is provided in section **3. RTCM Protocol** of the [GNSS Protocol Specification](./assets/component_documentation/quectel_lg290p03lgx80p03_gnss_protocol_specification_v1-1.pdf) manual. This protocol is used for transferring GNSS raw measurement data, as detailed by the [Radio Technical Commission for Maritime Services](https://www.rtcm.org/) organization.

			??? abstract "List of Supported RTCMv3 *(MSM)* Messages"
				<article style="text-align: center;" markdown>

				| Message | Type Mode | Message Description                              |
				| :--: | :----------: | :----------------------------------------------- |
				| 1005 | Input/Output | Stationary RTK Reference Station ARP             |
				| 1006 | Input/Output | Stationary RTK Reference Station ARP with height |
				| 1019 | Input/Output | GPS Ephemerides                                  |
				| 1020 | Input/Output | GLONASS Ephemerides                              |
				| 1041 | Input/Output | NavIC/IRNSS Ephemerides                          |
				| 1042 | Input/Output | BDS Satellite Ephemeris Data                     |
				| 1044 | Input/Output | QZSS Ephemerides                                 |
				| 1046 | Input/Output | Galileo I/NAV Satellite Ephemeris Data           |
				| 1073 | Input/Output | GPS MSM3 |
				| 1074 | Input/Output | GPS MSM4 |
				| 1075 | Input/Output | GPS MSM5 |
				| 1076 | Input/Output | GPS MSM6 |
				| 1077 | Input/Output | GPS MSM7 |
				| 1083 | Input/Output | GLONASS MSM3 |
				| 1084 | Input/Output | GLONASS MSM4 |
				| 1085 | Input/Output | GLONASS MSM5 |
				| 1086 | Input/Output | GLONASS MSM6 |
				| 1087 | Input/Output | GLONASS MSM7 |
				| 1093 | Input/Output | Galileo MSM3 |
				| 1094 | Input/Output | Galileo MSM4 |
				| 1095 | Input/Output | Galileo MSM5 |
				| 1096 | Input/Output | Galileo MSM6 |
				| 1097 | Input/Output | Galileo MSM7 |
				| 1113 | Input/Output | QZSS MSM3 |
				| 1114 | Input/Output | QZSS MSM4 |
				| 1115 | Input/Output | QZSS MSM5 |
				| 1116 | Input/Output | QZSS MSM6 |
				| 1117 | Input/Output | QZSS MSM7 |
				| 1123 | Input/Output | BDS MSM3 |
				| 1124 | Input/Output | BDS MSM4 |
				| 1125 | Input/Output | BDS MSM5 |
				| 1126 | Input/Output | BDS MSM6 |
				| 1127 | Input/Output | BDS MSM7 |
				| 1133 | Input/Output | NavIC/IRNSS MSM3 |
				| 1134 | Input/Output | NavIC/IRNSS MSM4 |
				| 1135 | Input/Output | NavIC/IRNSS MSM5 |
				| 1136 | Input/Output | NavIC/IRNSS MSM6 |
				| 1137 | Input/Output | NavIC/IRNSS MSM7 |

				</article>

=== "PPS Output"
	From the module, the [PPS](https://en.wikipedia.org/wiki/Pulse-per-second_signal "Pulse Per Second") output signal is a 3.3V signal output that can be access through the SMA connector and/or the `PPS` [PTH](https://en.wikipedia.org/wiki/Through-hole_technology "Plated Through Holes") pin. The signal is also connected to the `PPS` LED, which can be used as a visual indicator for its operation.

	<figure markdown>
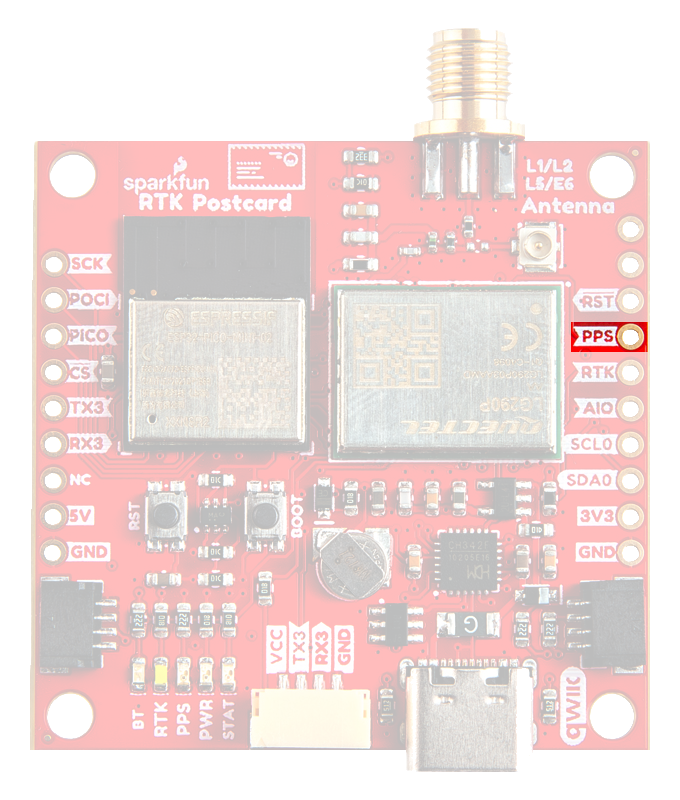
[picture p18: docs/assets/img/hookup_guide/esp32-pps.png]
I/O for PPS signal
	
	<figcaption markdown>The timing signal's outputs on the RTK Postcard.</figcaption>
	</figure>

	??? tip "Jumpers"
		*See the **[Jumpers](#jumpers)** section for more details.*

		- There is a jumper attached to the `PPS` PTH pin. When cut, it disconnects the pin from the PPS signal.
		- There is a jumper attached to the `PPS` LED. For low power applications, the jumper can be cut to disable the `PPS` LED.

	??? tip "Use Case"
		- Users could use this signal in conjunction with the event pins to synchronize two modules with each other.
		- Users could use this signal to create their own **Stratum 0** source for the [NTP](https://en.wikipedia.org/wiki/Network_Time_Protocol "Network Time Protocol") on a primary time server.

=== "RTK"
	The `RTK` [PTH](https://en.wikipedia.org/wiki/Through-hole_technology "Plated Through Holes") pin operates as both the `RTK_STAT` status indicator for the RTK positioning and `ANT_ON` power control for the external LNA or active antenna power. The pin is also connected to the `RTK` LED, which can be used as a visual indicator for its operation.

	<figure markdown>
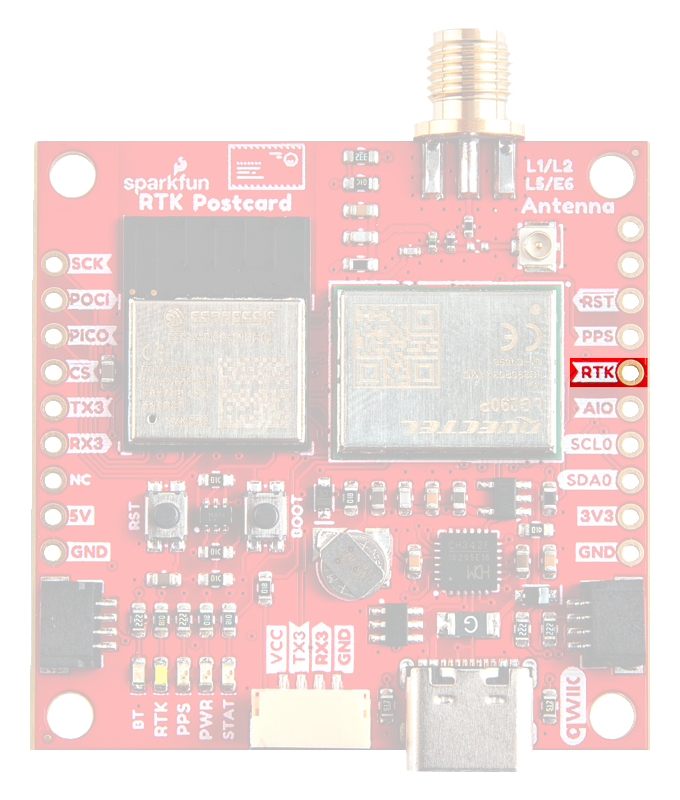
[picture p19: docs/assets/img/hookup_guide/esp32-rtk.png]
I/O for RTK signal
	
	<figcaption markdown>The RTK signal's outputs on the RTK Postcard.</figcaption>
	</figure>

	=== "`RTK_STAT`"
		In this configuration, the pin is set to a high level at startup.

		1. If the pin output is high, it indicates the module has entered the RTK fixed mode.
		2. If the pin output is low, it indicates that the module exited the RTK fixed mode.
		3. If the pin outputs an alternating pin level, it indicates that the module received the correct RTCM data and did not enter the RTK fixed mode.

	=== "`ANT_ON`"
		In this configuration, the pin is used to control the external LNA or active antenna power supply.

		- When the pin is high, the antenna is powered.
		- When the pin is low, the antenna is not powered.

	??? tip "Jumpers"
		*See the **[Jumpers](#jumpers)** section for more details.*

		- There is a jumper attached to the `RTK` LED. For low power applications, the jumper can be cut to disable the `RTK` LED.

=== "Reset"
	The `RST` pin can be used to reset the LG290P module if it enters an abnormal state. To reset the GNSS module, the pin must be low for more than 100ms.

	<figure markdown>
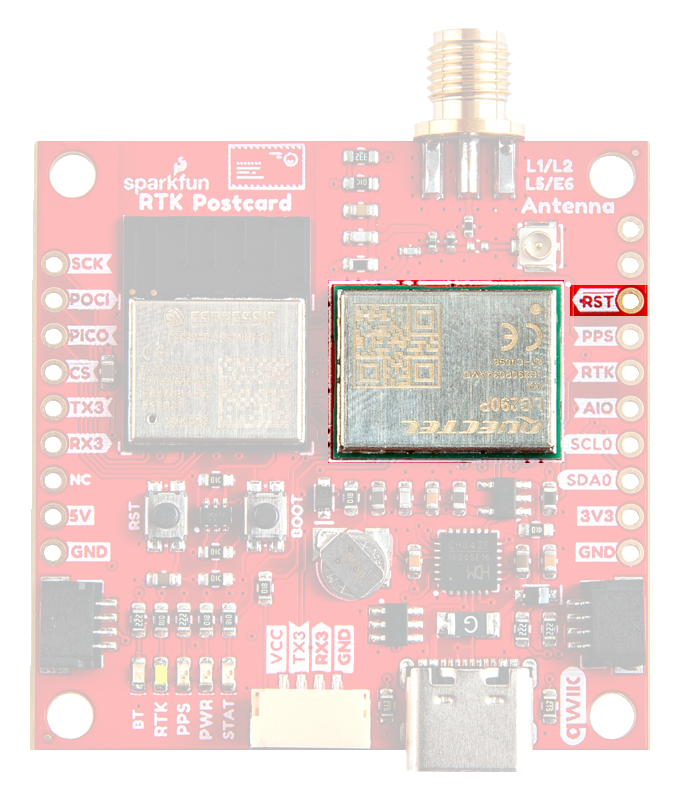
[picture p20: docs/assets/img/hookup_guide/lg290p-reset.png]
Reset Pin
	
	<figcaption markdown>The `RST` pin on the RTK Postcard.</figcaption>
	</figure>

<!-- === "Event" -->
<!-- === "I^2^C" -->

## Buttons
There are two buttons on RTK Postcard; a ++"RST"++ and ++"BOOT"++ button.

<figure markdown>
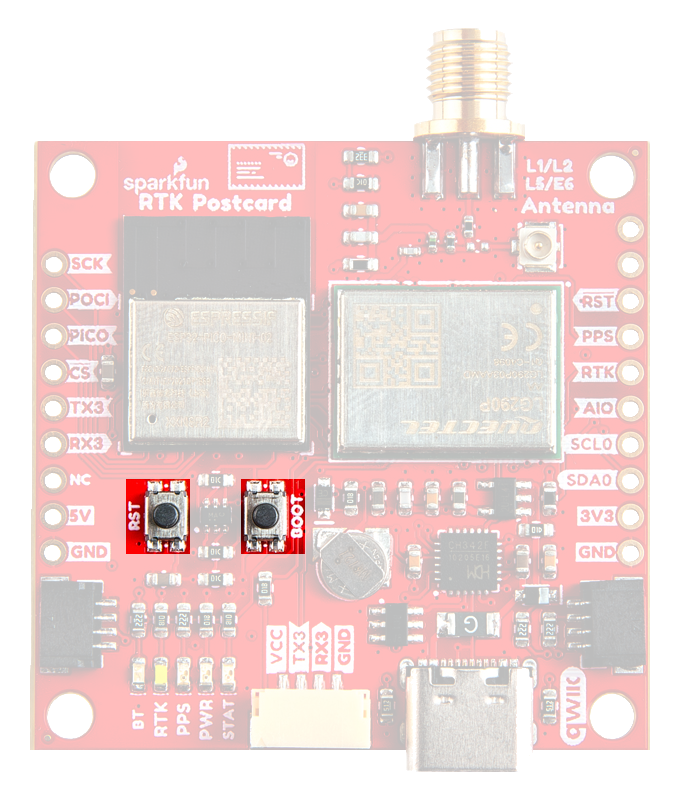
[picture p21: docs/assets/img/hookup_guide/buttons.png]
Buttons

<figcaption markdown>++"RST"++ and ++"BOOT"++ buttons on the RTK Postcard.</figcaption>
</figure>

=== "Reset"
	### Reset Button
	The ++"RST"++ *(reset)* button allows users to reset the program running on the ESP32 Pico-Mini module without unplugging the board.

=== "Boot"
	### Boot Button
	The ++"BOOT"++ button can be used to force the board into the serial bootloader. Holding down the ++"BOOT"++ button, while connecting the board to a computer through its USB-C connector or resetting the board will cause it to enter the <a href="https://docs.espressif.com/projects/esptool/en/latest/esp32/advanced-topics/boot-mode-selection.html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">Firmware Download mode</a>. The board will remain in this mode until it power cycles (happens automatically after uploading new firmware) or the ++"RST"++ button is pressed.

	1. Hold the ++"BOOT"++ button down.
	1. Reset the MCU.
		- While unpowered, connect the board to a computer with through the USB-C connection.
		- While powered, press the ++"RST"++ button.
	1. Release the ++"BOOT"++ button.
	1. After programming is completed, reboot the MCU.
		- Press the ++"RST"++ button.
		- Power cycle the board.

## GNSS Antenna Connectors
While there are two GNSS antenna connectors, only the SMA connector is connected to the LG290P GNSS module by default. If users wish, they can rework the *0402* resistor on the antenna trace to utilize the u.fl connector instead.

<div class="grid" markdown>

<div markdown>

<figure markdown>
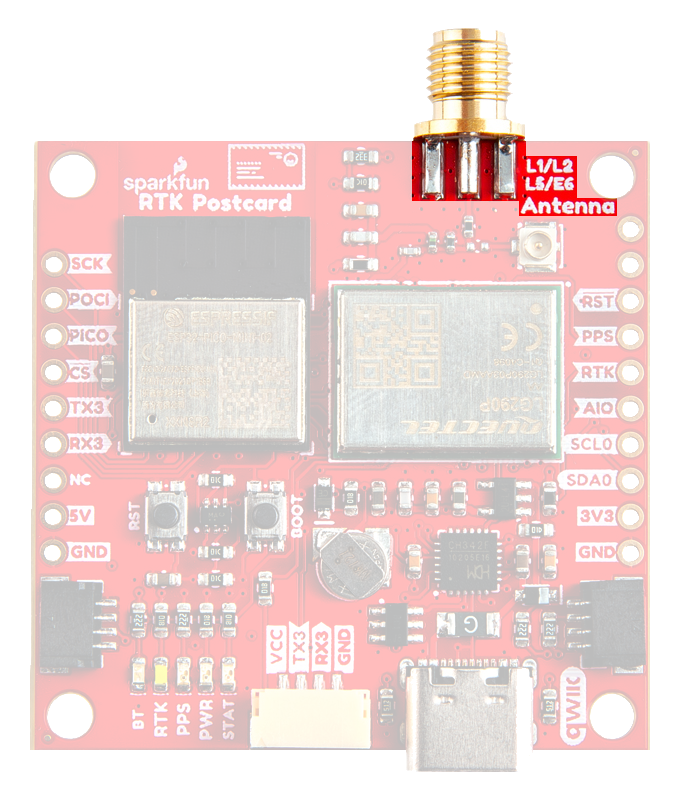
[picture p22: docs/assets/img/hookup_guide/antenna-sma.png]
SMA Connector

<figcaption markdown>The SMA connector for an external GNSS antenna on the RTK Postcard.</figcaption>
</figure>

</div>

<div markdown>

<figure markdown>
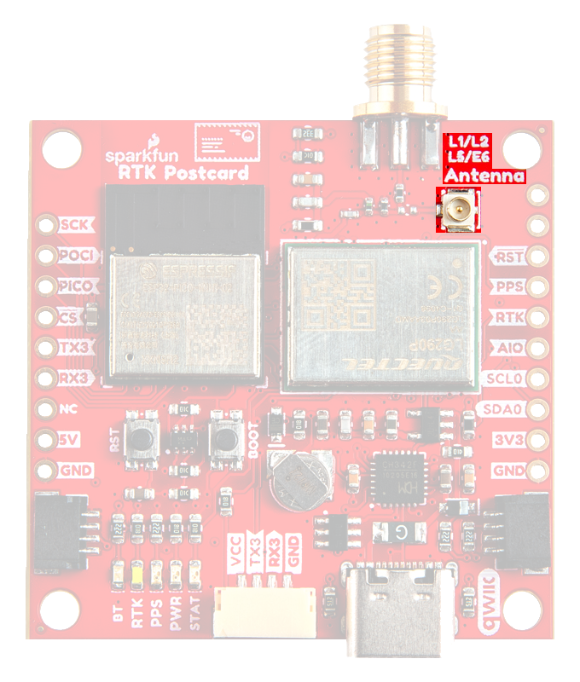
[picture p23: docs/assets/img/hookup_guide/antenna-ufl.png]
u.fl Connector

<figcaption markdown>The u.fl connector for the **[PPS output](#pps-output)** from the RTK Postcard.</figcaption>
</figure>

</div>

</div>

!!! warning "Antenna Specifications"
	- Passive antennas are not recommended for the LG290P GNSS module.
	- To mitigate the impact of out-of-band signals, utilize an active antenna whose SAW filter is placed in front of the LNA in the internal framework.
		- **DO NOT** select and antenna with the LNA placed in the front.
	- There is no need to inject an external DC voltage into the SMA connector for the GNSS antenna. Power is already provided from the LG290P module for the LNA of an active antenna.

## JST Connector
The RTK Postcard features a 4-pin [JST GH connector](./assets/component_documentation/JST-GH_datasheet.pdf), which is polarized and locking. Users can access the pins of the `UART3` port, through the JST connector with our [breadboard cable](https://www.sparkfun.com/breadboard-to-jst-ghr-04v-cable-4-pin-x-1-25mm-pitch.html)(1) or through the PTH pins. The pin layout of the JST connector is compatible with many of our [serial radios and adapter cables](../hardware_assembly/#radio-transceivers).
{ .annotate }

1. <a href="https://www.sparkfun.com/breadboard-to-jst-ghr-04v-cable-4-pin-x-1-25mm-pitch.html">
	<figure markdown>
	Product Thumbnail
	</figure>

	---

	**Breadboard to JST-GHR-04V Cable - 4-Pin x 1.25mm Pitch**<br>
	CAB-17240</a>

<figure markdown>
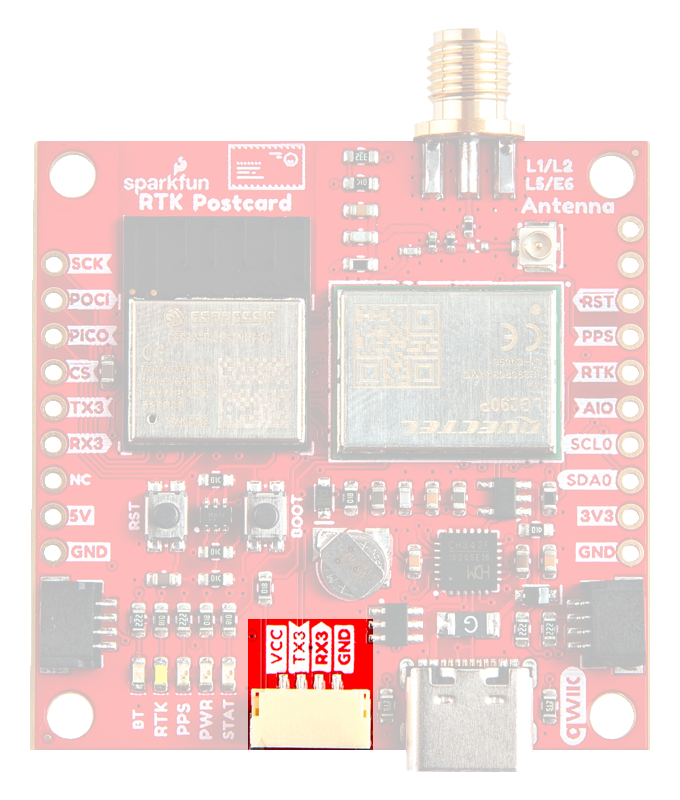
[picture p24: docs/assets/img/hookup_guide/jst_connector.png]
JST connector

<figcaption markdown>The JST connector on the RTK Postcard.</figcaption>
</figure>

??? info "Default Baudrate"
	- The default bardrate of the `UART` ports from the LG290P is **480600bps**, with the factory settings.
	- The default bardrate of the `UART3` port from the LG290P *(for the locking JST connector)* is **57600bps**, when utilizing the pre-programmed [RTK Everywhere firmware](https://github.com/sparkfun/SparkFun_RTK_Everywhere_Firmware).

??? info "Pin Connections"
	#### Pin Connections
	When connecting the RTK Postcard to other products, users need to be aware of the pin connections between the devices.

	<article style="text-align: center;" markdown>

	<table border="1" markdown>
	<tr>
	<th style="vertical-align:middle;">Pin Number</th>
	<td align="center">
		**1**<br>
		*(Left Side)*
	</td>
	<td align="center">**2**</td>
	<td align="center">**3**</td>
	<td align="center">**4**</td>
	</tr>
	<tr>
	<th>Label</th>
	<td align="center">VCC</td>
	<td align="center">TX3</td>
	<td align="center">RX3</td>
	<td align="center">GND</td>
	</tr>
	<tr>
	<th style="vertical-align:middle;">Function</th>
	<td>
		<u>**Voltage Output**</u><br>
		- **Default: 3.3V**<br>
		- Selectable: 3.3V or 5V
	</td>
	<td align="center" style="vertical-align:middle;">`UART3` - Receive</td>
	<td align="center" style="vertical-align:middle;">`UART3` - Transmit</td>
	<td align="center" style="vertical-align:middle;">Ground</td>
	</tr>
	</table>

	</article>

	<div class="grid" markdown>

	<div markdown>

	When connecting the RTK Postcard to our radios, the pin connections should follow the table below. If the flow control is not enabled, the only the `RX`, `TX`, and `GND` pins are utilized.

	<article style="text-align: center;" markdown>

	<table markdown>
	<tr>
	<th>Board</th>
	<td align="center">RX</td>
	<td align="center">TX</td>
	<td align="center">GND</td>
	</tr>
	<tr>
	<th>Radio</th>
	<td align="center">TX</td>
	<td align="center">RX</td>
	<td align="center">GND</td>
	</tr>
	</table>

	</article>

	</div>

	<div markdown>

	As documented in the [LoRaSerial product manual](https://docs.sparkfun.com/SparkFun_LoRaSerial), the pin connections between a host system *(i.e. RTK Postcard)* and the LoRaSerial Kit radio is outlined in the image below.

	<figure markdown>
	Flow Control (https://docs.sparkfun.com/SparkFun_LoRaSerial/img/SAMD21%20Flow%20control.png "Click to enlarge")
	<figcaption markdown>The `COM` ports on the RTK Postcard.</figcaption>
	</figure>

	</div>

	</div>

## Status LEDs

<div class="grid" markdown>

<div markdown>
There are five status LEDs on the RTK Postcard. The table below, lists the pin connections between these LEDs, the LG290P GNSS module, and the ESP32 Pico-Mini module. For details about their operation, please refer to the list at the underneath.

<article style="text-align: center;" markdown>

| LED | ESP32 GPIO | LG290P IO  |
| :----: | :--- | :--- |
| `BT` | `GPIO 4` | --- |
| `RTK`  | `GPIO 34`  | `RTK_STAT` |
| `PPS`  | `GPIO 36`  | `1PPS` |
| `PWR`  | N/A | N/A |
| `STAT` | `GPIO 0` | --- |

</article>

</div>

<div markdown>

<figure markdown>
Status LEDs
<figcaption markdown>The status LED indicators on the RTK Postcard.</figcaption>
</figure>

</div>

</div>

- **`BT`** - Bluetooth *(Blue)*
	- With the [RTK Everywhere firmware](https://github.com/sparkfun/SparkFun_RTK_Everywhere_Firmware), this LED indicates when the ESP32 Pico-Mini module is paired with a Bluetooth device
- **`RTK`** - [RTK](https://en.wikipedia.org/wiki/Real-time_kinematic_positioning "Real-Time Kinematic") Mode *(White)*
	- Indicates when an RTK fix has been established or when the correct RTCM data is being received *(see the **[RTK](#rtk)** section)*
- **`PPS`** - Pulse-Per-Second *(Yellow)*
	- Indicates when there is a pulse-per-second signal *(see the **[PPS Output](#pps-output)** section)*
- **`PWR`** - Power *(Red)*
	- Turns on once 3.3V power is supplied to the board
- **`STAT`** - Status *(Green)*
	- With the [RTK Everywhere firmware](https://github.com/sparkfun/SparkFun_RTK_Everywhere_Firmware), this LED indicates the operation mode

## Jumpers

??? note "Never modified a jumper before?"
	Check out our <a href="https://learn.sparkfun.com/tutorials/664">Jumper Pads and PCB Traces tutorial</a> for a quick introduction!

	<div class="grid cards" markdown align="center">

	-   <a href="https://learn.sparkfun.com/tutorials/664">
		<figure markdown>
		Tutorial thumbnail
		</figure>

		---

		**How to Work with Jumper Pads and PCB Traces**</a>

	</div>

There are eight jumpers on the back of the board that can be used to easily modify the hardware connections on the board. From which, there are five jumpers that control power to the status LEDs on the board. By default, all the jumpers are connected to power the status LEDs. For low power applications, users can cut the jumpers to disconnect power from each of the LEDs.

<figure markdown>
Jumpers
<figcaption markdown>The jumpers on the back of the RTK Postcard.</figcaption>
</figure>

- **`I2C-EXT`** - This jumper can be cut to disconnect the pull-up resistors on the `SCL_1` and `SDA_1` connections of the Qwiic connectors.
- **`SHLD`** - This jumper can be cut to disconnect the shielding of the USB-C connector from the `GND` plane of the board
- **`VSEL`** - This jumper can be modified to configure/disconnect the `VCC` pin of the 4-pin locking JST connector to/from `3V3` or `5V` power rails.
	- Users should also keep in mind that connecting the jumper to the `5V` power rail, could include the voltage provided by the LiPo battery from the [Portability Shield](https://www.sparkfun.com/sparkfun-portability-shield.html).
- **`STAT`** - This jumper can be cut to remove power from the green LED, indicating the operational status for the [RTK Everywhere firmware](https://github.com/sparkfun/SparkFun_RTK_Everywhere_Firmware).
- **`PWR`** - This jumper can be cut to remove power from the red, power LED.
- **`PPS`** - This jumper can be cut to remove power from the yellow LED, which is connected to the [PPS](https://en.wikipedia.org/wiki/Pulse-per-second_signal "Pulse Per Second") signal.
- **`RTK`** - This jumper can be cut to remove power from the white LED, indicating RTK fix or operation in RTK mode.
- **`BT`** - This jumper can be cut to remove power from the blue LED, indicating Bluetooth pairing for the [RTK Everywhere firmware](https://github.com/sparkfun/SparkFun_RTK_Everywhere_Firmware).

!!! info "Default Configuration"
	- By default, [PPS](https://en.wikipedia.org/wiki/Pulse-per-second_signal "Pulse Per Second") signal is connected to the `PPS` pin.
	- By default, the `VSEL` jumper is connected to `3V3` pad for a regulated 3.3V output on the 4-pin JST-GH connector.
	- By default, the `BT_VCC` jumper provides a regulated 3.3V output to the BlueSMiRF header.

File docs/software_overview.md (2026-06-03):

---
icon: fontawesome/solid/computer
---

## CH342 USB Driver
The USB drivers for the CH342 USB-to-Serial converter can be downloaded from the [manufacturer's website](https://www.wch-ic.com/search?q=CH342&t=downloads).

<div class="grid cards" align="center" markdown>

-   :material-microsoft-windows: **Windows**

	---

	[:octicons-download-16:{ .heart } Download Page for `CH343SER.EXE`](https://www.wch-ic.com/downloads/CH343SER_EXE.html){ .md-button .md-button--primary target="blank" }

-   :material-apple: **MacOS**

	---

	[:octicons-download-16:{ .heart } Download Page for `CH341SER_MAC.ZIP`](https://www.wch-ic.com/downloads/CH34XSER_MAC_ZIP.html){ .md-button .md-button--primary target="blank" }

</div>

!!! info "Linux"
	A USB driver is not required for Linux based operating systems.

## RTK Everywhere Firmware
The RTK Postcard comes preloaded with our latest [RTK Everywhere firmware](https://github.com/sparkfun/SparkFun_RTK_Everywhere_Firmware). Our firmware is completely open-source; therefore, users can view the code to troubleshoot issues, contribute new features or updates, and file issues for any bugs they discover. In addition, we also users with pre-compiled binaries in our [SparkFun RTK Everywhere Firmware binaries GitHub repository](https://github.com/sparkfun/SparkFun_RTK_Everywhere_Firmware_Binaries) and a [RTK Firmware Uploader](https://github.com/sparkfun/SparkFun_RTK_Firmware_Uploader) tool to upload the pre-compiled binaries to the RTK Postcard. For more information, users can reference the [user manual](http://docs.sparkfun.com/SparkFun_RTK_Everywhere_Firmware/) for the RTK Everywhere firmware and associated links below:

- [Compile the firmware](https://docs.sparkfun.com/SparkFun_RTK_Everywhere_Firmware/firmware_compile/)
- [Update the firmware](https://docs.sparkfun.com/SparkFun_RTK_Everywhere_Firmware/firmware_update_esp32/)
- [RTK Firmware Uploader](https://github.com/sparkfun/SparkFun_RTK_Firmware_Uploader)

## QGNSS Software
QGNSS is highly intuitive GNSS evaluation software that is easy to use, personalized, and compatible with leading Quectel technologies. The software allows users to define or apply GNSS product configurations for specific use cases. Saving, restoring, or sharing configurations between different products and updating the module's firmware are easy. The software supports product evaluation with a choice of views to observe static and dynamic behavior of the connected a Quectel GNSS receiver.

<article style="text-align: center;" markdown>
[:octicons-download-16:{ .heart } Download the QGNSS Software *(v2.x)* from Quectel](https://www.quectel.com/download/qgnss_v2-0_en/){ .md-button .md-button--primary target="blank" }
</article>

??? warning "Windows Only"
	Currently, the QGNSS software is only available for Windows operating systems.

### Connecting to the LG290P
In order to connect to the LG290P properly, users will need to specify the settings of the UART port.

<figure markdown>
Configure UART Settings
<figcaption markdown>Click the <kbd>:material-cog:</kbd> button to configure the UART settings.</figcaption>
</figure>

Before users can connect to the RTK Postcard, they will need to specify the connection settings in QGNSS. Once configured, users can select the ++"OK"++ button and QGNSS will automatically attempt to connect to the GNSS module.

- Select the `LG290P(03)` from the drop-down menu to configure the `Model` of the GNSS module being connected.
- Below, is a list of the default settings for `UART` ports of the LG290P. These settings should be selected in the `Device Information` menu, unless configured differently.
- When connecting through the USB-C connector, under the `Port` option, select the port labeled with channel `B` from the drop-down menu.

<div class="grid" markdown>

<div markdown>

<figure markdown>
UART Settings in QGNSS
<figcaption markdown>From the available `COM` ports for the CH342, select the port labeled `B` to access the LG290P GNSS receiver. Users will also need to specify the settings for the UART port.</figcaption>
</figure>

</div>

<div markdown>

!!! info "LG290P - Default Settings"
	The UART ports of the LG290P GNSS module will have the following default configuration:

	- Baudrate: 460800bps
	- Data Bits: 8
	- Parity: No
	- Stop Bits: 1
	- Flow Control: None

</div>

</div>

## Arduino IDE
!!! tip
	For first-time users, who have never programmed before and are looking to use the Arduino IDE, we recommend beginning with the <a href="https://www.sparkfun.com/sparkfun-inventor-s-kit-for-arduino-uno-v4-1.html">SparkFun Inventor's Kit (SIK)</a>, which is designed to help users get started programming with the Arduino IDE.

Most users may already be familiar with the Arduino IDE and its use. However, for those of you who have never heard the name *Arduino* before, feel free to check out the [Arduino website](https://www.arduino.cc/en/Guide/HomePage). To get started with using the Arduino IDE, check out our tutorials below:

<div class="grid cards" markdown align="center">

-   <a href="https://learn.sparkfun.com/tutorials/50"><figure markdown>
	What is an Arduino?
	</figure>

	---

	**What is an Arduino?**</a>

-   <a href="https://learn.sparkfun.com/tutorials/61"><figure markdown>
	Installing the Arduino IDE
	</figure>

	---

	**Installing the Arduino IDE**</a>

-   <a href="https://learn.sparkfun.com/tutorials/1265"><figure markdown>
	Installing Board Definitions in the Arduino IDE
	</figure>

	---

	**Installing Board Definitions in the Arduino IDE**</a>

-   <a href="https://learn.sparkfun.com/tutorials/15"><figure markdown>
	Installing an Arduino Library
	</figure>

	---

	**Installing an Arduino Library**</a>

</div>

### Espressif ESP32 Arduino Core
The [ESP32 Arduino Core](https://github.com/espressif/arduino-esp32) can be installed from the board manager in the Arduino IDE by searching for:

	esp32 by Espressif Systems

<div class="grid" markdown>

<div markdown>

<figure markdown>
Board manager Click to enlarge
<figcaption markdown>The Espressif ESP32 Arduino core in the library manager of the Arduino IDE.</figcaption>
</figure>

</div>

<div markdown>

!!! tip "Arduino Board Manager URL"
	In order to install Espressif's ESP32 Arduino core, users must provide the Arduino Board Manager URL in the preferences settings *(**File** > **Preferences**)* for the Arduino IDE:

	```
	https://raw.githubusercontent.com/espressif/arduino-esp32/gh-pages/package_esp32_index.json
	```

!!! tip "Board Definition for RTK Postcard"
	In order to program the ESP32 Pico-Mini module on the RTK Postcard, users should select the **ESP32 Dev Module** from the **Tools** > **Board:** > **esp32** drop-down menu.

</div>

</div>

### SparkFun LG290P Quadband RTK GNSS Arduino Library
The [SparkFun LG290P Quadband RTK GNSS Arduino Library](https://github.com/sparkfun/SparkFun_LG290P_GNSS_Arduino_Library) can be installed from the library manager in the Arduino IDE by searching for:

	SparkFun LG290P Quadband RTK GNSS Arduino Library

<div class="grid" markdown>

<div markdown>

<figure markdown>
Library manager Click to enlarge
<figcaption markdown>SparkFun LG290P Quadband RTK GNSS Arduino Library in the library manager of the Arduino IDE.</figcaption>
</figure>

</div>

<div markdown>

!!! tip "Manually Download the Arduino Library"
	For users who would like to manually download and install the library, the `*.zip` file can be accessed from the [GitHub repository](https://github.com/sparkfun/SparkFun_LG290P_GNSS_Arduino_Library) or downloaded by clicking the button below.

	<article style="text-align: center;" markdown>
	[:octicons-download-16:{ .heart } Download the Arduino Library](https://github.com/sparkfun/SparkFun_LG290P_GNSS_Arduino_Library/archive/refs/heads/main.zip){ .md-button .md-button--primary }
	</article>

</div>

</div>

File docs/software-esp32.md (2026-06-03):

---
icon: fontawesome/solid/microchip
---

## CH342 USB Driver
The USB drivers for the CH342 USB-to-Serial converter can be downloaded from the [manufacturer's website](https://www.wch-ic.com/search?q=CH342&t=downloads).

<div class="grid cards" align="center" markdown>

-   :material-microsoft-windows: **Windows**

	---

	[:octicons-download-16:{ .heart } Download Page for `CH343SER.EXE`](https://www.wch-ic.com/downloads/CH343SER_EXE.html){ .md-button .md-button--primary target="blank" }

-   :material-apple: **MacOS**

	---

	[:octicons-download-16:{ .heart } Download Page for `CH341SER_MAC.ZIP`](https://www.wch-ic.com/downloads/CH34XSER_MAC_ZIP.html){ .md-button .md-button--primary target="blank" }

</div>

!!! info "Linux"
	A USB driver is not required for Linux based operating systems.

## RTK Everywhere Firmware
The RTK Postcard comes preloaded with our latest [RTK Everywhere firmware](https://github.com/sparkfun/SparkFun_RTK_Everywhere_Firmware). Our firmware is completely open-source; therefore, users can view the code to troubleshoot issues, contribute new features or updates, and file issues for any bugs they discover. In addition, we also users with pre-compiled binaries in our [SparkFun RTK Everywhere Firmware binaries GitHub repository](https://github.com/sparkfun/SparkFun_RTK_Everywhere_Firmware_Binaries) and a [RTK Firmware Uploader](https://github.com/sparkfun/SparkFun_RTK_Firmware_Uploader) tool to upload the pre-compiled binaries to the RTK Postcard. For more information, users can reference the [user manual](http://docs.sparkfun.com/SparkFun_RTK_Everywhere_Firmware/) for the RTK Everywhere firmware and associated links below:

- [Compile the firmware](https://docs.sparkfun.com/SparkFun_RTK_Everywhere_Firmware/firmware_compile/)
- [Update the firmware](https://docs.sparkfun.com/SparkFun_RTK_Everywhere_Firmware/firmware_update_esp32/)
- [RTK Firmware Uploader](https://github.com/sparkfun/SparkFun_RTK_Firmware_Uploader)

`RTK_Everywhere_Firmware_RC-XXX_XX_XXXX.bin`
`RTK_Everywhere_Firmware_RC-*.bin`

## Arduino IDE
Most users may already be familiar with the Arduino IDE and its use. However, for those of you who have never heard the name *Arduino* before, feel free to check out the [Arduino website](https://www.arduino.cc/en/Guide/HomePage). In order to program the RTK Postcard, users will need to install the [ESP32 Arduino Core](https://github.com/espressif/arduino-esp32) through the **Board Manager**. Additionally, we also recommend installing the [SparkFun LG290P Quadband RTK GNSS Arduino Library](https://github.com/sparkfun/SparkFun_LG290P_GNSS_Arduino_Library) to interface with the LG290P GNSS receiver.

### Espressif ESP32 Arduino Core
The [ESP32 Arduino Core](https://github.com/espressif/arduino-esp32) can be installed from the board manager in the Arduino IDE by searching for:

	esp32 by Espressif Systems

<div class="grid" markdown>

<div markdown>

<figure markdown>
Preference settings Click to enlarge
<figcaption markdown>Preference settings for the Arduino IDE.</figcaption>
</figure>

</div>

<div markdown>

<figure markdown>
Board manager Click to enlarge
<figcaption markdown>The Espressif ESP32 Arduino core in the library manager of the Arduino IDE.</figcaption>
</figure>

</div>

</div>

!!! tip "Arduino Board Manager URL"
	In order to install Espressif's ESP32 Arduino core, users must provide the Arduino Board Manager URL in the preferences settings *(**File** > **Preferences**)* for the Arduino IDE:

	```
	https://raw.githubusercontent.com/espressif/arduino-esp32/gh-pages/package_esp32_index.json
	```

#### Board Selection
In order to program the ESP32 Pico-Mini module on the RTK Postcard, users should select the **ESP32 Dev Module** from the **Tools** > **Board:** > **esp32** drop-down menu.

<figure markdown>
Board definition Click to enlarge
<figcaption markdown>Selecting the **ESP32 Dev Module** board for the RTK Postcard in the Arduino IDE.</figcaption>
</figure>

### SparkFun LG290P Quadband RTK GNSS Arduino Library
The [SparkFun LG290P Quadband RTK GNSS Arduino Library](https://github.com/sparkfun/SparkFun_LG290P_GNSS_Arduino_Library) can be installed from the library manager in the Arduino IDE by searching for:

	SparkFun LG290P Quadband RTK GNSS Arduino Library

<div class="grid" markdown>

<div markdown>

<figure markdown>
Library manager Click to enlarge
<figcaption markdown>SparkFun LG290P Quadband RTK GNSS Arduino Library in the library manager of the Arduino IDE.</figcaption>
</figure>

</div>

<div markdown>

!!! tip "Manually Download the Arduino Library"
	For users who would like to manually download and install the library, the `*.zip` file can be accessed from the [GitHub repository](https://github.com/sparkfun/SparkFun_LG290P_GNSS_Arduino_Library) or downloaded by clicking the button below.

	<article style="text-align: center;" markdown>
	[:octicons-download-16:{ .heart } Download the Arduino Library](https://github.com/sparkfun/SparkFun_LG290P_GNSS_Arduino_Library/archive/refs/heads/main.zip){ .md-button .md-button--primary }
	</article>

</div>

</div>

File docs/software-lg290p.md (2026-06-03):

---
icon: fontawesome/solid/satellite
---

## CH342 USB Driver
The USB drivers for the CH342 USB-to-Serial converter can be downloaded from the [manufacturer's website](https://www.wch-ic.com/search?q=CH342&t=downloads).

<div class="grid cards" align="center" markdown>

-   :material-microsoft-windows: **Windows**

	---

	[:octicons-download-16:{ .heart } Download Page for `CH343SER.EXE`](https://www.wch-ic.com/downloads/CH343SER_EXE.html){ .md-button .md-button--primary target="blank" }

-   :material-apple: **MacOS**

	---

	[:octicons-download-16:{ .heart } Download Page for `CH341SER_MAC.ZIP`](https://www.wch-ic.com/downloads/CH34XSER_MAC_ZIP.html){ .md-button .md-button--primary target="blank" }

</div>

!!! info "Linux"
	A USB driver is not required for Linux based operating systems.

## GNSS Software
!!! tip
	To manually interface with the LG290P GNSS module, users can utilize the [QGNSS software provided by Quectel](#qgnss-software). This method is recommended due to the unique data structure of the UART command messages, utilized to configure the LG290P module.

	??? warning "Windows Only"
		Currently, the QGNSS software is only available for Windows operating systems.

	??? success "Windows, MacOS, or Linux"
		For users with computers that run on MacOS or Linux, we have found alternative software option for viewing the data from the NMEA messages. However, this GUI interface is currently limited to only receiving UART messages and cannot send messages to configure the LG290P module.

		- :material-github: [GitHub Repository](https://github.com/semuconsulting/PyGPSClient)
		- [Installation Instructions](https://github.com/semuconsulting/PyGPSClient?tab=readme-ov-file#installation)
		- [PyPI Project](https://pypi.org/project/pygpsclient/)

### QGNSS Software
QGNSS is highly intuitive GNSS evaluation software that is easy to use, personalized, and compatible with leading Quectel technologies. The software allows users to define or apply GNSS product configurations for specific use cases. Saving, restoring, or sharing configurations between different products and updating the module's firmware are easy. The software supports product evaluation with a choice of views to observe static and dynamic behavior of the connected a Quectel GNSS receiver.

<div align="center" markdown>

[:octicons-download-16:{ .heart } Download the QGNSS Software *(v2.1)* from Quectel](https://www.quectel.com/download/qgnss_v2-1_en/){ .md-button .md-button--primary target="blank" }

</div>

??? warning "Windows Only"
	Currently, the QGNSS software is only available for Windows operating systems.

#### Connecting to the LG290P
In order to connect to the LG290P properly, users will need to specify the settings of the UART port.

<figure markdown>
Configure UART Settings
<figcaption markdown>Click the <kbd>:material-cog:</kbd> button to configure the UART settings.</figcaption>
</figure>

Before users can connect to the RTK Postcard, they will need to specify the connection settings in QGNSS. Once configured, users can select the ++"OK"++ button and QGNSS will automatically attempt to connect to the GNSS module.

- Select the `LG290P(03)` from the drop-down menu to configure the `Model` of the GNSS module being connected.
- Below, is a list of the default settings for `UART` ports of the LG290P. These settings should be selected in the `Device Information` menu, unless configured differently.
- When connecting through the USB-C connector, under the `Port` option, select the port labeled with channel `B` from the drop-down menu.

<div class="grid" markdown>

<div markdown>

<figure markdown>
UART Settings in QGNSS
<figcaption markdown>From the available `COM` ports for the CH342, select the port labeled `B` to access the LG290P GNSS receiver. Users will also need to specify the settings for the UART port.</figcaption>
</figure>

</div>

<div markdown>

!!! info "LG290P - Default Settings"
	The UART ports of the LG290P GNSS module will have the following default configuration:

	- Baudrate: 460800bps
	- Data Bits: 8
	- Parity: No
	- Stop Bits: 1
	- Flow Control: None

</div>

</div>

#### Configure the LG290P
By default, the UART ports are configured to transmit and receive `NMEA 0183` and/or `RTCM 3.x` messages. These messages are generally used for transmitting PNT data; and providing or receiving RTK corrections, respectively. Quectel also implements a system of proprietary messages (`PQTM`) for users to configure the LG290P, following the data format of the `NMEA` protocol.

???+ terminal "Data Format - PQTM Messages"
	The expected structure of the data in the proprietary PQTM messages is shown below:

	<figure markdown>
	NMEA data structure
	<figcaption markdown>The data structure of Quectel messages for the `NMEA` protocol.</figcaption>
	</figure>

	`<Checksum>`:

	- Checksum field follows the checksum delimiter character `*`.
	- Checksum is the 8-bit exclusive OR of all characters in the sentence, including `,` the field delimiter, between but not including the `$` and the `*` delimiters.

	`<CR>` & `<LF>`: Carriage return; followed by a new line

	- Depending on the terminal emulator, these may be options configured in the program settings.
	- Otherwise, users may need to add the `\r` and `\n` characters at the end of the message.

In the QGNSS software, users can click on the ++"Advance"++ button, at the bottom of the `QConsole` window, to configure the settings for the messages sent to the LG290P. Selecting `NMEA` and `CRLF` from the drop-down menu of the **Checksum Type** and **Suffix** options, will automatically calculate and append the `<checksum>` value, carriage return, and line follow to the end of the message entered in the **Data Input** field.

<figure markdown>
NMEA message setting
<figcaption markdown>The settings for the messages transmitted from the QConsole.</figcaption>
</figure>

???+ tip "Display the QConsole Toolbar"
	There is a toolbar for the QConsole, which has a bunch of tools that users may find useful. This includes, a search function, scroll-lock button, pause/clear the message feed, etc. To open/close the toolbar inside the QConsole, ++"right-click"++ on the mouse and select the `Show Tool` option from the drop-down menu or utilize the keyboard shortcut: ++ctrl++ + ++q++.

	<figure markdown>
	QConsole Toolbar
	<figcaption markdown>++"Right-click"++ on the mouse and select the `Show Tool` option, inside the QConsole.</figcaption>
	</figure>

??? example "Example - `PQTMCFGUART` Message"
	As an example, try utilizing the `PQTMCFGUART` PQTM message. Enter `$PQTMCFGUART,R*` into the **Data Input*** field of the QConsole. DOn't forget to select the `NMEA` and `CRLF` options from ++"Advance"++ settings menu. If entered and configured properly, the value `36` should pop up in the **Checksum** field of the QConsole; then, click on the <kbd>:material-send:</kbd> button to send the message.

	``` bash
	$PQTMCFGUART,R*
	```

	Once the message has been sent, keep a close watch of the messages in the console. It may help to click on the <kbd>:octicons-unlock-16:</kbd> button to disable auto-scrolling, when trying to locate the message response. Additionally, the response may not appear right away, it could be appended to the end of the next data packet, as shown in the image below.

	<figure markdown>
	PQTM demo
	<figcaption markdown>Example of utilizing the Quectel PQTM messages in the QConsole.</figcaption>
	</figure>

#### Firmware Update
In the event that users need to update the firmware on the LG290P module, please refer to the instructions in Quectel's [reference manual](./assets/component_documentation/quectel_lg290p03lgx80p03_firmware_upgrade_guide_v1-1.pdf). For the latest firmware, users should reach out to Quectel through their [forum page](https://forums.quectel.com/); otherwise, we have some of the firmware releases available in one of our [GitHub repositories](https://github.com/sparkfun/SparkFun_RTK_Postcard/tree/main/Firmware).

<article style="text-align: center;" markdown>

[Archived Firmware Releases](https://github.com/sparkfun/SparkFun_RTK_Postcard/tree/main/Firmware){ .md-button .md-button--primary target="blank" } [Firmware Upgrade Manual](./assets/component_documentation/quectel_lg290p03lgx80p03_firmware_upgrade_guide_v1-1.pdf){ .md-button .md-button--primary target="blank" }

</article>

!!! warning "Synchronization Step"
	In the [reference manual](./assets/component_documentation/quectel_lg290p03lgx80p03_firmware_upgrade_guide_v1-1.pdf), **Step 9** instructs users to wait for a synchronization process. If users refer to an earlier section of the manual, this process requires the LG290P module to receive a `SYNC_WORD1` within 500ms of powering up. Therefore, users must restart the module during the synchronization step. In the QGNSS software *(+v2.1)*, this can be performed with the reboot button.

	<figure markdown>
	Reboot button
	<figcaption markdown>Reboot button in the QGNSS software *(v2.1)*.</figcaption>
	</figure>

	!!! tip
		For previous versions of the QGNSS software, prior to initializing the firmware upgrade process, users can send the `PQTMSRR` message to perform a system reset and reboot the GNSS receiver. We recommend having everything pre-configured to upgrade the firmware as the module usually initializes within 5s of sending the `PQTMSRR` message.

### PyGPSClient
!!! warning "Software Limitations"
	With this software, users will only be able to view the data from the NMEA messages and connect to an NTRIP caster. Users will not be able to configure the LG290P module with the built-in console.

As an alternative to QGNSS, for users with computers that run on MacOS or Linux, we recommend [PyGPSClient](https://github.com/semuconsulting/PyGPSClient) as an option for viewing the data from the NMEA messages and connecting to an NTRIP caster. However, users should be aware that this GUI interface is currently limited to only receiving UART messages and cannot send messages to configure the LG290P module.

??? info "Resources"
	For additional information, users can refer to the following resources for the PyGPSClient software:

	- :material-github: [GitHub Repository](https://github.com/semuconsulting/PyGPSClient)
	- [Installation Instructions](https://github.com/semuconsulting/PyGPSClient?tab=readme-ov-file#installation)
	- [PyPI Project](https://pypi.org/project/pygpsclient/)

#### Installation
There are a variety of [installation methods](https://github.com/semuconsulting/PyGPSClient?tab=readme-ov-file#installation) detailed in the GitHub repository's `README.md` file. However, we recommend utilizing the `pip` installation method.

!!! terminal "Installation Commands"
	Depending on how Python is installed on the computer, one of the following commands should allow users to install the software.

	- 
		``` bash
		python3 -m pip install pygpsclient
		```
	- 
		``` bash
		pip install pygpsclient
		```

	!!! info "System Requirements"
		This installation method requires an internet connection. Additionally, users will also need administrative privileges *(or root access `sudo`)* for the installation.

#### Connecting to the LG290P
Before users can connect to the RTK Postcard, they will need to specify the settings of the UART port in PyGPSClient. Once configured, users can select the <kbd>:material-usb:</kbd> button and PyGPSClient will automatically attempt to connect to the GNSS module.

- Below, is a list of the default settings for `UART` ports of the LG290P. These settings should be selected in the configuration menu.
- For the `Serial Port`, select the port labeled with channel `B` from the drop-down menu.

<div class="grid" markdown>

<div markdown>

<figure markdown>
UART Settings in PyGPSClient
<figcaption markdown>Specify the settings for the UART port in QGNSS.</figcaption>
</figure>

</div>

<div markdown>

!!! info "LG290P - Default Settings"
	The UART ports of the LG290P GNSS module will have the following default configuration:

	- Baudrate: 460800bps
	- Data Bits: 8
	- Parity: No
	- Stop Bits: 1
	- Flow Control: None

</div>

</div>

### Terminal Emulator
Another viable option for connecting to the RTK Postcard, is to utilize a [terminal emulation program](https://learn.sparkfun.com/tutorials/112). While reading the data sent from the LG290P is relatively trivial, users will need to be more selective when choosing an emulator to configure the LG290P module on the RTK Postcard. This is due to the unique data structure of the proprietary messages that Quectel implements to configure the LG290P *(see the [**Configure the LG290P**](#configure-the-lg290p) section, above)*.

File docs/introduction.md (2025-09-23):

---
icon: material/book-open-page-variant
---

# Introduction
<div class="grid cards desc" markdown>

-   <a href="https://www.sparkfun.com/sparkfun-rtk-postcard.html">
	**SparkFun RTK Postcard**<br>
	**SKU:** GPS-26916

	---

	<figure markdown>
	Product Thumbnail
	</figure></a>

	<article class="video-500px" style="text-align: center; margin: auto;" markdown>
	<iframe src="https://www.youtube.com/embed/t00t77OuVi4" title="Product Showcase Video" frameborder="0" allow="accelerometer; autoplay; clipboard-write; encrypted-media; gyroscope; picture-in-picture" allowfullscreen></iframe>
	QR code to product video
	</article>

	<article style="text-align: center;" markdown>
	QR code to product page [Purchase from SparkFun :fontawesome-solid-cart-plus:{ .heart }](https://www.sparkfun.com/sparkfun-rtk-postcard.html){ .md-button .md-button--primary }
	</article>

- Designed and manufactured in Boulder, CO USA, the SparkFun RTK Postcard is a compact development board for your high-precision positioning and navigation needs. This board combines the Quectel LG290P GNSS RTK receiver with an Espressif ESP32-PICO-MINI-02 MCU module, running our latest [RTK Everywhere firmware](https://github.com/sparkfun/SparkFun_RTK_Everywhere_Firmware). The ESP32 provides the SparkFun Postcard with WiFi and Bluetooth&trade; connectivity to operate as an NTRIP caster or client. Meanwhile, the 4-pin locking JST-GH connector allows users to transmit or receive RTCMv3 messages for RTK corrections from a local base station.

	- The LG290P module is a quad-band, multi-constellation, high-precision, RTK GNSS receiver. The module can simultaneously receive signals from the `L1`, `L2`, `L5`, and `L6`/`E6` frequency bands of the GPS, GLONASS, Galileo, BDS, QZSS, and NavIC GNSS constellations. In addition, the module supports SBAS augmentation systems (WASS, EGNOS, BDSBAS, MSAS, GAGAN, and SDCM), PPP services[^2] (BDS PPP-B2b, QZSS CLAS, MADOCA-PPP, and Galileo HAS), RTCM, and RTK corrections for precision navigation with a fast convergence time and reliable performance. Connect with ease using a variety of interfaces, including UART, SPI[^1], and I2C[^1].

	- The ESP32-PICO-MINI-02 is a powerful MCU module with WiFi, Bluetooth&trade;, and BLE connectivity and comes integrated with 8MB SPI flash, 2MB SPI Pseudo static RAM (PSRAM), and a 40 MHz crystal oscillator. The ESP32 microcontroller itself features two CPU cores that can be individually controlled, with an adjustable clock frequency between 80 - 240MHz and a low-power co-processor for minor tasks, such as monitoring peripherals. It supports a range of peripherals including an SD card interface, capacitive touch sensors, ADC, DAC, Two-Wire Automotive Interface (TWAI), Ethernet, high-speed SPI, UART, I2S, I2C, etc.

	With the [RTK Everywhere firmware](https://github.com/sparkfun/SparkFun_RTK_Everywhere_Firmware) that comes pre-loaded, users can seamlessly operate the RTK Postcard as a base station or rover. These modes also offer additional functions, based on the available, wireless communication options:

	- The RTK Postcard can transmit or receive RTCMv3 messages locally by connecting one of our [SiK Telemetry radios](https://www.sparkfun.com/sik-telemetry-radio-v3-915mhz-100mw.html).
	- Through WiFi or Bluetooth&trade;, the RTK Postcard can also function as an NTRIP caster or client.
	- The RTK Postcard can transmit NMEA messages to a [graphical information software (GIS)](https://docs.sparkfun.com/SparkFun_RTK_Everywhere_Firmware/gis_software_android/) apps on any mobile device when paired as a Bluetooth&trade; device.

	In addition to the RTK Postcard, we created the [Portability Shield](https://www.sparkfun.com/sparkfun-portability-shield.html) for the convenience of users. Simply connecting these products, provides a 1.3” OLED display and a five-way button to navigate the configuration settings and display PNT data; a microSD card slot for data logging; and a LiPo battery charger with a fuel gauge to take the RTK Postcard *"on-the-go"*. All of these will operate plug-and-play without the need for new code.

	!!! info
		The [RTK Everywhere firmware](https://github.com/sparkfun/SparkFun_RTK_Everywhere_Firmware) is open-source, so users can obtain, check, and even modify the device's functionality. This allows for easier feature expansion, bug maintenance, and longer device longevity.

</div>

!!! warning "Features Under Development"
	- **I^2^C/SPI** - Currently, only the UART interface is supported by the module.
	- **PPP Services** - Corrections for some of the PPP services have not been implemented.

[^1]:
	!!! warning "Feature Under Development"
		**I^2^C/SPI** - Currently, only the UART interface is supported by the module.

[^2]:
	!!! warning "Feature Under Development"
		Corrections for some of the PPP services have not been implemented.

## :fontawesome-solid-list-check:&nbsp;Required Materials
To get started, users will need a few items. Some users may already have a few of these items, feel free to adjust accordingly.

<div class="annotate" markdown>

- Computer and/or mobile device that is compatible with the operation of the [RTK Everywhere firmware](https://github.com/sparkfun/SparkFun_RTK_Everywhere_Firmware)
- [USB 3.1 Cable A to C - 3 Foot](https://www.sparkfun.com/usb-3-1-cable-a-to-c-3-foot.html) - Used to power/interface with the SparkFun RTK Postcard (1)
- [SparkFun RTK Postcard](https://www.sparkfun.com/sparkfun-rtk-postcard.html)
- GNSS Multi-Band Antenna

</div>

1. If your computer doesn't have a USB-A slot, then choose an appropriate cable or adapter.

<div class="grid cards products" markdown>

-   <a href="https://www.sparkfun.com/usb-3-1-cable-a-to-c-3-foot.html">
	<figure markdown>
	USB 3.1 Cable A to C - 3 Foot
	</figure>

	---

	**USB 3.1 Cable A to C - 3 Foot**<br>
	CAB-14743</a>

-   <a href="https://www.sparkfun.com/sparkfun-rtk-postcard.html">
	<figure markdown>
	Product Thumbnail
	</figure>

	---

	**SparkFun RTK Postcard**<br>
	GPS-26916</a>

</div>

???+ tip "Recommended Accessories"
	These products are recommended at minimum for users to get started with the [Portability Shield](https://www.sparkfun.com/sparkfun-portability-shield.html) and [RTK Everywhere firmware](https://github.com/sparkfun/SparkFun_RTK_Everywhere_Firmware).

	<div class="grid cards" markdown>

	-   <a href="https://www.sparkfun.com/gnss-multi-band-l1-l2-l5-helical-antenna-sma.html">
		<figure markdown>
		Product Thumbnail
		</figure>

		---

		**GNSS Multi-Band L1/L2/L5 Helical Antenna (SMA)**<br>
		GPS-23847</a>

	-   <a href="https://www.sparkfun.com/sparkfun-portability-shield.html">
		<figure markdown>
		Product Thumbnail
		</figure>

		---

		**SparkFun Portability Shield**<br>
		DEV-27510</a>

	-   <a href="https://www.sparkfun.com/straight-header-male-pth-0-1in-40-pin.html">
		<figure markdown>
		Product Thumbnail
		</figure>

		---

		**Break Away Headers - Straight**<br>
		PRT-00116</a>

	</div>

	??? note "Soldering Equipment"
		To add headers for the Portability Shield, users will need [soldering equipment](https://www.sparkfun.com/categories/49).

		!!! tip "New to soldering?"
			Check out our [How to Solder: Through-Hole Soldering](https://learn.sparkfun.com/tutorials/5) tutorial for a quick introduction!

			<div class="grid cards" markdown align="center">

			-   <a href="https://learn.sparkfun.com/tutorials/5">
				<figure markdown>
				Tutorial Thumbnail
				</figure>

				---

				**How to Solder: Through-Hole Soldering**</a>

			</div>

		<div class="grid cards" markdown>

		-   <a href="https://www.sparkfun.com/solder-lead-free-100-gram-spool.html">
			<figure markdown>
			Product Thumbnail
			</figure>

			---

			**Solder Lead Free - 100-gram Spool**<br>
			TOL-09325</a>

		-   <a href="https://www.sparkfun.com/pinecil-soldering-iron-kit.html">
			<figure markdown>
			Product Thumbnail
			</figure>

			---

			**PINECIL Soldering Iron Kit**<br>
			KIT-24063</a>

		</div>

	???+ note "*Optional Accessories*"
		These products are optional, based on the utility required by the user.

		<div class="grid cards" markdown>
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

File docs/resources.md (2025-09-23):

---
icon: material/book-open-page-variant
---

## Product Resources

<div class="grid cards" markdown>

- 
	- :sfe-logo: [Product Page](https://www.sparkfun.com/sparkfun-rtk-postcard.html)
	- :material-folder-cog: Design Files:
		- :fontawesome-solid-file-pdf: [Schematic](./assets/board_files/schematic.pdf)
		- :fontawesome-solid-file-pdf: [Board Dimensions](./assets/board_files/dimensions.pdf)
		- :material-folder-zip: [KiCad Files](./assets/board_files/kicad_files.zip)
		- :material-cube-outline: [STEP File](./assets/3d_model/cad_model.step)
	- :fontawesome-solid-computer: Software:
		- :fontawesome-solid-file-code: [RTK Everywhere Firmware](https://github.com/sparkfun/SparkFun_RTK_Everywhere_Firmware)
			- :material-book-open-variant: [User Manual](https://docs.sparkfun.com/SparkFun_RTK_Everywhere_Firmware/)
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

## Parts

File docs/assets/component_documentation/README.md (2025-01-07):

component_documentation directory
====================

A copy of the datasheets, user manuals, programming guides, etc. of the major electrical components on the board.

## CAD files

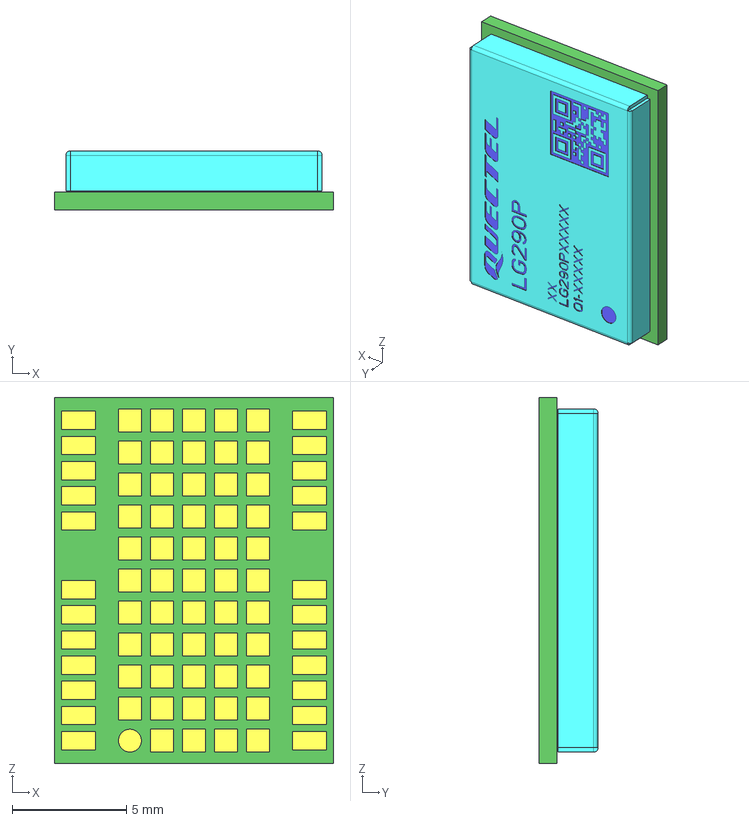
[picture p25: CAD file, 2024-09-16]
docs/assets/component_documentation/Quectel_LG290P_3D_Dimensions_V1.0.stp
12.2 x 2.60 x 16.0 mm
LG290P-PCB
LG290P-COVER

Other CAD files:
Hardware/LG290P.step

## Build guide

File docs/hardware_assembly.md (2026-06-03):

---
icon: material/tools
---

## USB Programming (`UART1`)
The USB connection can be utilized for serial communication and configuring the LG290P GNSS module. Users only need to connect their RTK Postcard to a computer, using a USB-C cable.

<figure markdown>
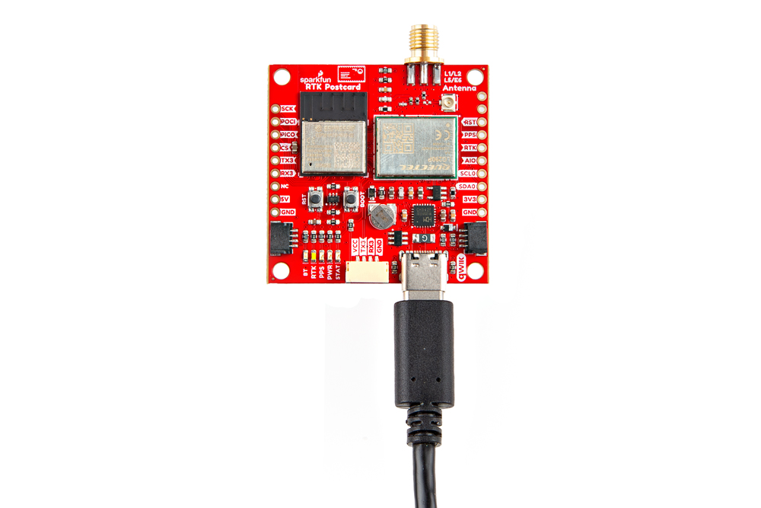
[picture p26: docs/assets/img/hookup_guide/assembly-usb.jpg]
RTK Postcard USB connection

<figcaption markdown>The RTK Postcard with USB-C cable being attached.</figcaption>
</figure>

!!! info "Default Baud Rate"
	The default baud rate of the UART ports on the LG290P is **460800bps**.

## GNSS Antenna
In order to receive [GNSS](https://en.wikipedia.org/wiki/Satellite_navigation "Global Navigation Satellite System") signals, users will need to connect a compatible antenna. For the best performance, we recommend users choose an active, multi-band GNSS antenna and utilize a low-loss cable.

???+ warning "Antenna Specifications"
	- Passive antennas are not recommended for the LG290P GNSS module.
	- To mitigate the impact of out-of-band signals, utilize an active antenna whose SAW filter is placed in front of the LNA in the internal framework.
		- **DO NOT** select and antenna with the LNA placed in the front.
	- There is no need to inject an external DC voltage into the SMA connector for the GNSS antenna. Power is already provided from the LG290P module for the LNA of an active antenna.

<div class="grid" markdown>

<div markdown>

<figure markdown>
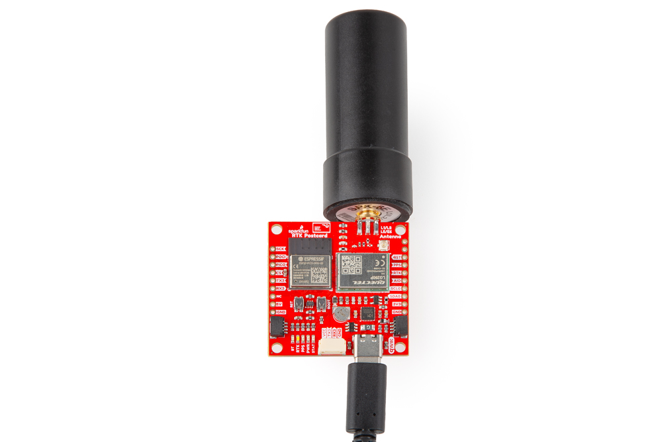
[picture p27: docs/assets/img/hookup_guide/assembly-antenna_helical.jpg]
Helical antenna

<figcaption markdown>A compact, helical GNSS antenna attached to the SMA connector on the RTK Postcard.</figcaption>
</figure>

</div>

<div markdown>

<figure markdown>
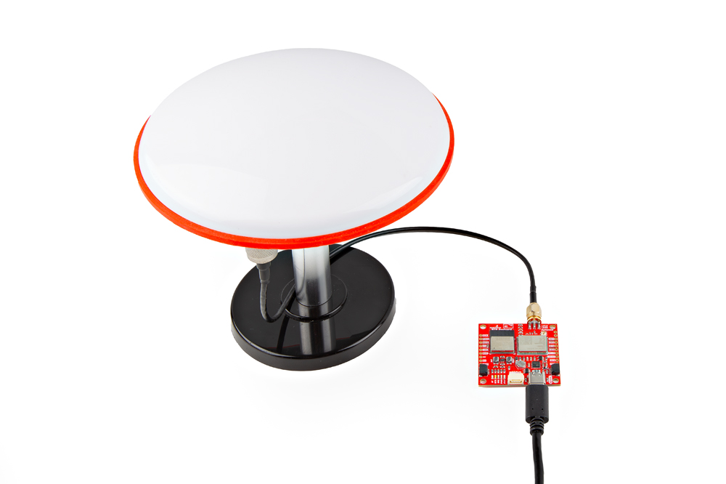
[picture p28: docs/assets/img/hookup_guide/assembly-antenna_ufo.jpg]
Survey antenna

<figcaption markdown>A GNSS survey antenna attached to the SMA connector on the RTK Postcard.</figcaption>
</figure>

</div>

</div>

## JST Connector (`UART3`)
The JST connector on the Quad-band GNSS RTK board, breaks out the `UART3` port of the LG290P GNSS module. In certain circumstances, users may need to utilize the JST connector to transmit or receive RTK correction data with one of our radios.

<div class="grid" markdown>

<div markdown>

<figure markdown>
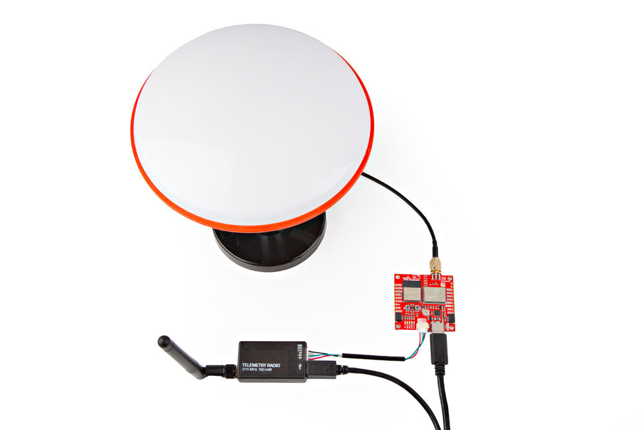
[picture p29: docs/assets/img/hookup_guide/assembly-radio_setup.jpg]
Device connected to the JST connector

<figcaption markdown>The [Telemetry Radio v3](https://www.sparkfun.com/sik-telemetry-radio-v3-915mhz-100mw.html) connected to the RTK Postcard.</figcaption>
</figure>

</div>

<div markdown>

When connecting the RTK Postcard to other products, users should be aware of the pin connections between the devices. The table below, details the pin connections of the locking JST connector on the RTK Postcard.

<article style="text-align: center;" markdown>

<table border="1" markdown>
<tr markdown>
<th style="vertical-align:middle;">Pin Number</th>
<td align="center" markdown>
	**1**<br>
	*(Left Side)*
</td>
<th align="center">2</td>
<th align="center">3</td>
<th align="center">4</td>
</tr>
<tr>
<th>Label</th>
<td align="center">VCC</td>
<td align="center">TX3</td>
<td align="center">RX3</td>
<td align="center">GND</td>
</tr>
<tr markdown>
<th style="vertical-align:middle;">Function</th>
<td markdown>
	<u>**Voltage Output**</u><br>
	- **Default: 3.3V**<br>
	- 3.3V or 5V
</td>
<td align="center" style="vertical-align:middle;" markdown>`UART3` - Receive</td>
<td align="center" style="vertical-align:middle;" markdown>`UART3` - Transmit</td>
<td align="center" style="vertical-align:middle;">Ground</td>
</tr>
</table>

</article>

</div>

</div>

!!! info "Default Baud Rate"
	The default baud rate of the UART ports on the LG290P is **460800bps**.

### Radio Transceivers
We have designed the locking JST connector to be plug-n-play with the following devices and cables. However, for the [SiK Telemetry Radio v3](https://www.sparkfun.com/sik-telemetry-radio-v3-915mhz-100mw.html), users should [modify the `VSEL` jumper](../hardware_overview/#jumpers) (1) on the back of the board to enable a 5V output on the `VCC` pin. Below, is a table summarizing the pin connections of the radios.
{ .annotate }

1. While the [SiK Telemetry Radio v3](https://www.sparkfun.com/sik-telemetry-radio-v3-915mhz-100mw.html) may function with a **3.3V** input, their specifications stipulate that a **5V** power supply be provided.

<article style="text-align: center;" markdown>

<table border="1" markdown>
<tr markdown>
<th style="vertical-align:middle;">Pin Number</th>
<td align="center" markdown>
	**1**<br>
	*(Left Side)*
</td>
<td align="center" markdown>**2**</td>
<td align="center" markdown>**3**</td>
<td align="center" markdown>**4**</td>
<td align="center" markdown>**5**</td>
<td align="center" markdown>
	**6**<br>
	*(Right)*
</td>
</tr>
<tr>
<th style="vertical-align:middle;">Label</th>
<td align="center" style="vertical-align:middle;">5V</td>
<td>
	RX - SiK<br>
	RXI - LoRaSerial
</td>
<td>
	TX - SiK<br>
	TXO - LoRaSerial
</td>
<td align="center" style="vertical-align:middle;">CTS</td>
<td align="center" style="vertical-align:middle;">RTS</td>
<td align="center" style="vertical-align:middle;">GND</td>
</tr>
<tr markdown>
<th style="vertical-align:middle;">Function</th>
<td markdown>
	<u>**Voltage Input**</u><br>
	- SiK: 5V<br>
	- LoRaSerial: 3.3 to 5V (1)
</td>
<td align="center" style="vertical-align:middle;">UART - Receive</td>
<td align="center" style="vertical-align:middle;">UART - Transmit</td>
<td align="center" style="vertical-align:middle;" markdown>
	Flow Control<br>
	*Clear-to-Send*
</td>
<td align="center" style="vertical-align:middle;" markdown>
	Flow Control<br>
	*Ready-to-Send*
</td>
<td align="center" style="vertical-align:middle;">Ground</td>
</tr>
</table>

</article>

??? tip "Radio Pin Connections"
	<div class="grid" markdown>

	<div markdown>

	As documented in the [LoRaSerial product manual](https://docs.sparkfun.com/SparkFun_LoRaSerial), the pin connections between a host system *(i.e. RTK Postcard)* and the LoRaSerial radio is outlined in the image below.

	<figure markdown>
	UART w/ Flow Control (https://docs.sparkfun.com/SparkFun_LoRaSerial/img/SAMD21%20Flow%20control.png "Click to enlarge")
	<figcaption markdown>The pin connections between a radio and the RTK Postcard.</figcaption>
	</figure>

	</div>

	<div markdown>

	However, the flow control pins *(`CTS` and `RTS`)* are not available on the RTK Postcard. Therefore, when connecting either of the radios, the pin connections should follow the table below:

	<article style="text-align: center;" markdown>

	<table>
	<tr>
	<th>Board</th>
	<td align="center">RX</td>
	<td align="center">TX</td>
	<td align="center">GND</td>
	</tr>
	<tr>
	<th>Radio</th>
	<td align="center">TX</td>
	<td align="center">RX</td>
	<td align="center">GND</td>
	</tr>
	</table>

	</article>

	</div>

	</div>

???+ note "Radio Transceivers and Cables"
	!!! warning "Default Baud Rate"
		The baud rate for these radios are configured by the [`SERIAL_SPEED` parameter](https://docs.sparkfun.com/SparkFun_LoRaSerial/at_commands/#serial-commands). The default configuration is `SERIAL_SPEED`: **57600bps**.

	<div class="grid cards" markdown>

	-   <a href="https://www.sparkfun.com/sik-telemetry-radio-v3-915mhz-100mw.html">
		<figure markdown>
		Product Thumbnail
		</figure>

		---

		**SiK Telemetry Radio V3 - 915MHz, 100mW**<br>
		WRL-19032</a>

	-   <a href="https://www.sparkfun.com/sparkfun-loraserial-kit-915mhz-enclosed.html">
		<figure markdown>
		Product Thumbnail
		</figure>

		---

		**SparkFun LoRaSerial Kit - 915MHz (Enclosed)**<br>
		WRL-20029</a>

	-   <a href="https://www.sparkfun.com/jst-ghr-04v-to-jst-ghr-06v-cable-1-25mm-pitch.html">
		<figure markdown>
		Product Thumbnail
		</figure>

		---

		**JST-GHR-04V to JST-GHR-06V Cable - 1.25mm pitch**<br>
		CAB-17239</a>

	-   <a href="https://www.sparkfun.com/ghr-04v-s-to-ghr-06v-s-cable-100mm.html">
		<figure markdown>
		Product Thumbnail
		</figure>

		---

		**GHR-04V-S to GHR-06V-S Cable - 100mm**<br>
		CAB-17854</a>

	</div>

## Breakout Pins
The [PTH](https://en.wikipedia.org/wiki/Through-hole_technology "Plated Through Holes") pins on the Quad-band GNSS RTK board are broken out into 0.1"-spaced pins on the outer edges of the board.

??? note "New to soldering?"
	If you have never soldered before or need a quick refresher, check out our [How to Solder: Through-Hole Soldering](https://learn.sparkfun.com/tutorials/how-to-solder-through-hole-soldering) guide.

	<div class="grid cards" markdown align="center">

	-   <a href="https://learn.sparkfun.com/tutorials/5">
		<figure markdown>
		Tutorial thumbnail
		</figure>

		---
	
		**How to Solder: Through-Hole Soldering**</a>

	</div>

<div class="grid cards" markdown>

-   **Headers**

	---

	When selecting headers, be sure you are aware of the functionality you require.

	<figure markdown>
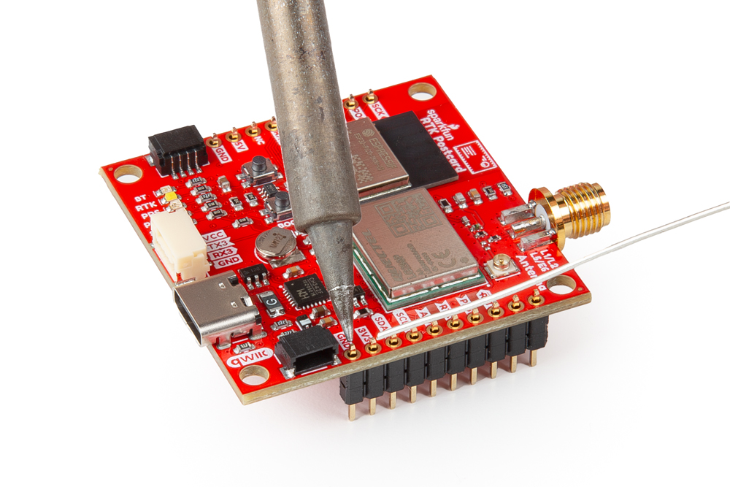
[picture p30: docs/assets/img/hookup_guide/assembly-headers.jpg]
Soldering headers
	
	<figcaption markdown>Soldering headers to the RTK Postcard.</figcaption>
	</figure>

-   **Hookup Wires**

	---

	For a more permanent connection, users can solder wires directly to the board.

	<figure markdown>
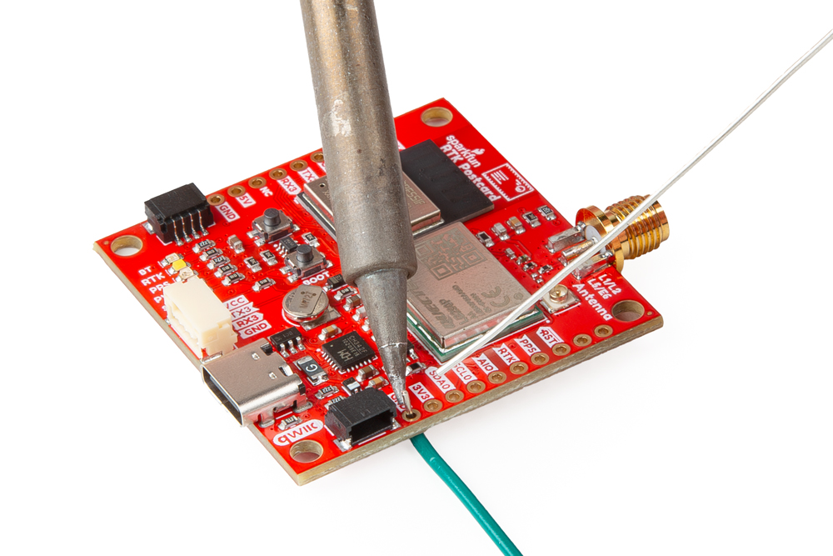
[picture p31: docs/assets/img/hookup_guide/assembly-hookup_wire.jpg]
Soldering wires
	
	<figcaption markdown>Soldering wires to the RTK Postcard.</figcaption>
	</figure>

</div>

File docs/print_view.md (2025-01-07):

---
hide:
  - navigation
  - toc
icon: material/printer
---

--8<-- "./introduction.md:5"

# Hardware Overview
--8<-- "./hardware_overview.md:5"

# Hardware Assembly
--8<-- "./hardware_assembly.md:5"

# Software Overview
--8<-- "./software_overview.md:5:28"

--8<-- "./software-esp32.md:32"

--8<-- "./software-lg290p.md:32"

# Resources
--8<-- "./resources.md:5"

# PQMT Commands
--8<-- "./pqmt_commands.md:5"

# Troubleshooting Tips
--8<-- "./troubleshooting_tips.md:5"

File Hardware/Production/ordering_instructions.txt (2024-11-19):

Ordering Instructions:
Panel dimensions: 100.56 x 203.16 mm.
Controlled Impedance: JLC04161H-7628 Stackup
Material: TG155
Solder Mask: Red
Silkscreen Color: White
Layers: 4
Finish: ENIG
Thickness: 1.6mm
Outer Copper Weight: 1oz
Inner Copper Weight: 0.5oz
Minimum track width: 0.15mm (6.00mil)
Minimum via drill: 0.30mm (11.81mil)
No Clean Process
Controlled Impedance: JLC04161H-7628 Stackup

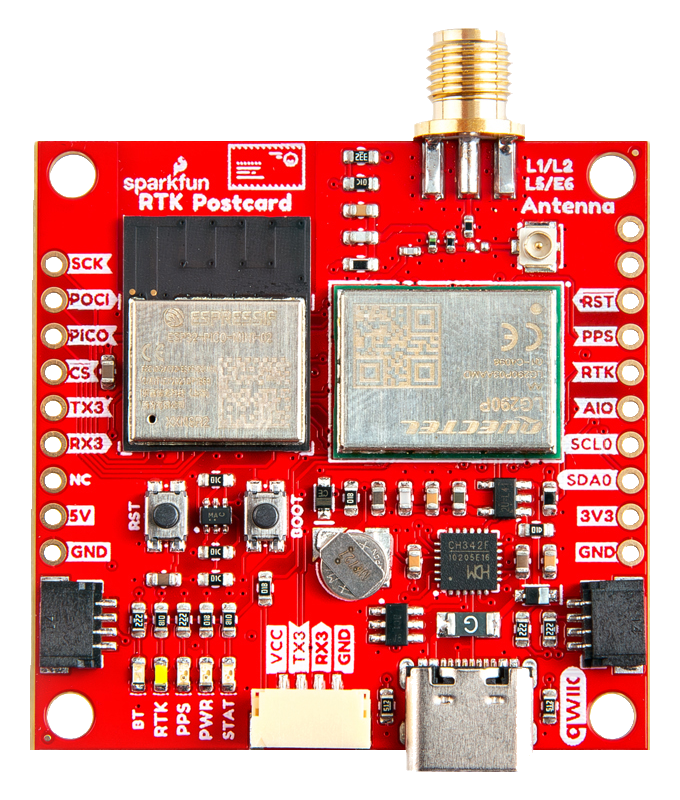
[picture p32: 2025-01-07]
docs/assets/img/hookup_guide/top.png

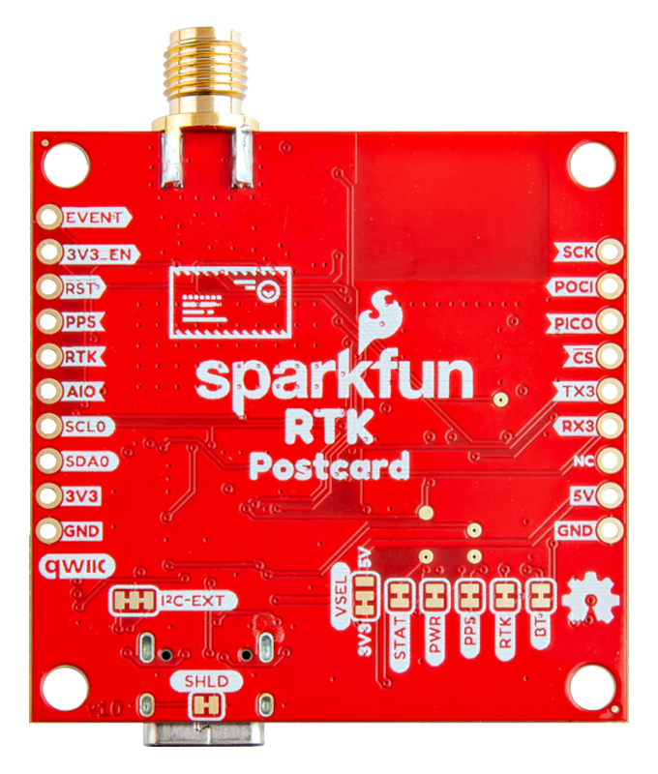
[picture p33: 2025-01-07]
docs/assets/img/hookup_guide/bottom.png

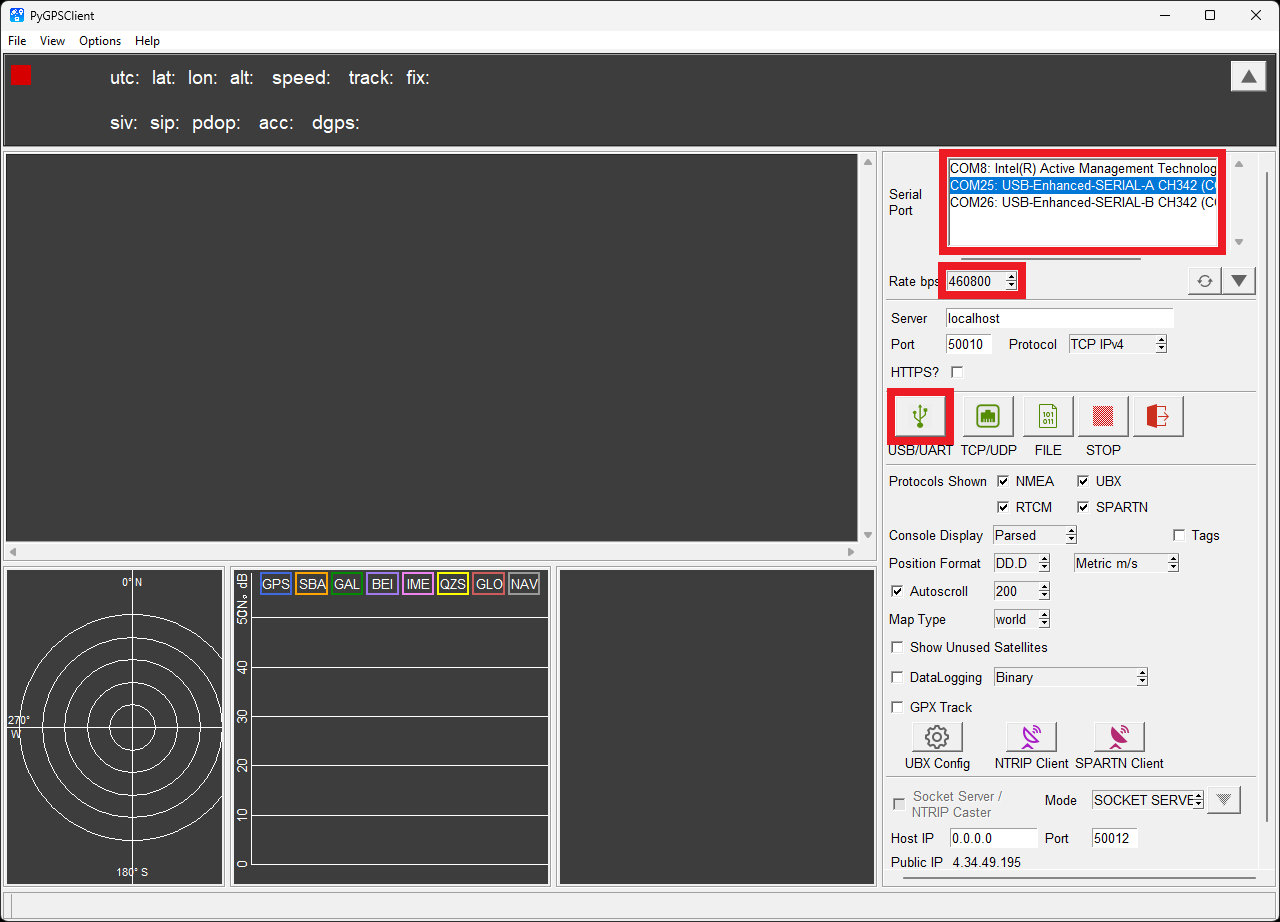
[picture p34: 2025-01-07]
docs/assets/img/hookup_guide/pygpsclient-uart_settings.png

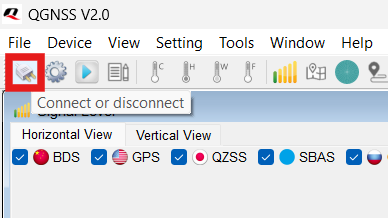
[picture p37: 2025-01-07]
docs/assets/img/hookup_guide/qgnss-connect_button.png

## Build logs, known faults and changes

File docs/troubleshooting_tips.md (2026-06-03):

---
icon: sfe-logo
---

!!! warning "Need Help?"
	If you need technical assistance or more information on a product that is not working as you expected, we recommend heading over to the [SparkFun Technical Assistance](https://www.sparkfun.com/technical_assistance) page for some initial troubleshooting.

	<article style="text-align: center;" markdown>
	[SparkFun Technical Assistance Page](https://www.sparkfun.com/technical_assistance){ .md-button .md-button--primary }
	</article>

	If you can't find what you need there, the [SparkFun GNSS Forum](https://community.sparkfun.com/c/global-positioning-system-gps/96) is a great place to ask questions.

	!!! info "Account Registration Required"
		If this is your first visit to our forum, you'll need to create a [Forum Account](https://community.sparkfun.com/signup) to post questions.

## Antenna Issues
At a minimum, we recommend utilizing an active L1/L2/L5 antenna with the LG290P. Some customers have reported that the LG290P remains in an `RTK Float` status, when utilizing GNSS antennas that don't meet these specifications. This is because the GNSS receiver is having issues resolving the ambiguities of the signals not being provided from the GNSS antenna. To resolve this issue, mask the signals and satellites in the GNSS receiver configuration. Limit the signals and satellites to only the capabilities of the GNSS antenna.

<!-- QR Code for Hookup Guide (Displayed when printed) -->
<article style="text-align: center;" markdown>
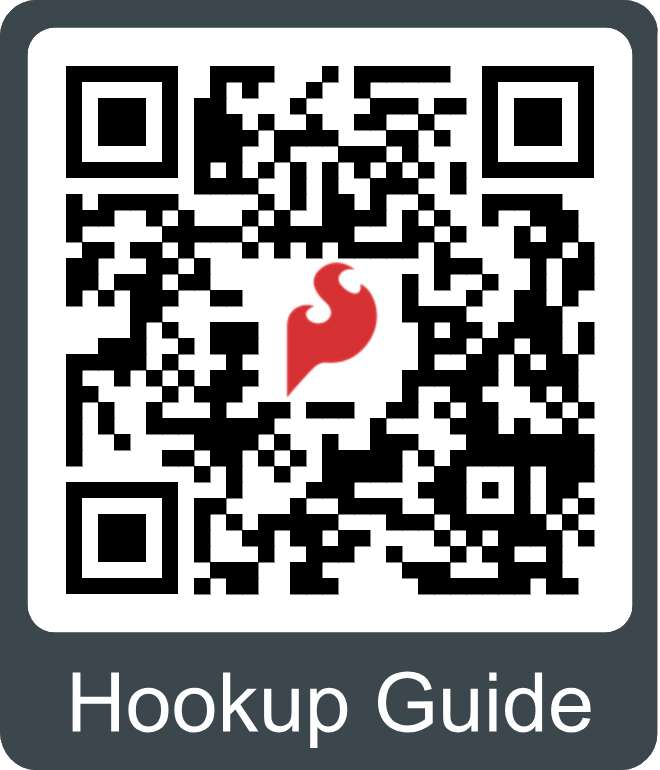
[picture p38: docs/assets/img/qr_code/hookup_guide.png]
QR code to the hookup guide

</article>

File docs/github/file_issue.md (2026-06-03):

# Did we make a mistake?

Spot something wrong? Please let us know. 

<!-- Technical Assistance Box -->
!!! warning "Need Help?"
	If you need technical assistance or more information on a product that is not working as you expected, we recommend heading on over to the [SparkFun Technical Assistance](https://www.sparkfun.com/technical_assistance) page for some initial troubleshooting. This **Submit Issues** page is not where users should seek assistance.

	<article style="text-align: center;" markdown>
	[SparkFun Technical Assistance Page](https://www.sparkfun.com/technical_assistance){ .md-button .md-button--primary }
	</article>

	If you can't find what you need there, the [SparkFun Forums](https://community.sparkfun.com) is a great place to search the product forums and ask questions.

	!!! info "Account Registration Required"
		For your first visit to our forum, you'll need to create a [Forum Account](https://community.sparkfun.com/signup) to post questions.

## Discrepancies in the Documentation

All of our documentation can be modified by you! Please help us make it better.

- The documentation files for these pages are contained in the [`docs` folder](https://github.com/sparkfun/SparkFun_RTK_Postcard/tree/main/docs) of the [SparkFun RTK Postcard repository](https://github.com/sparkfun/SparkFun_RTK_Postcard).

### 🔍 Spot something wrong?

If a section of the documentation is incorrect, please [open an issue](https://github.com/sparkfun/SparkFun_RTK_Postcard/issues) and let us know.

### Do you have a suggested correction?

1. With a GitHub account, [fork this repository](https://github.com/sparkfun/SparkFun_RTK_Postcard/fork).
2. Add your correction(s) or improvement(s) to the markdown file(s)
3. File a pull request with your changes, and enjoy making the ~~words~~ ~~worlds~~ world a better place.
	- Once received, the documentation specialist will automatically be notified.
	- We will review your suggested improvement(s) to make sure they are correct and fit within our documentation standards.

## Problems in the Hardware Design

All of our designs are open-source! Please help us make it better.

- Our board design files are contained in the [`Hardware` folder](https://github.com/sparkfun/SparkFun_RTK_Postcard/tree/main/Hardware) of the [SparkFun RTK Postcard repository](https://github.com/sparkfun/SparkFun_RTK_Postcard).

### Does something not make sense? 🤔

If part of the design is confusing, please [open an issue](https://github.com/sparkfun/SparkFun_RTK_Postcard/issues) and let us know.

### Did we forget to include an important function of the board? 🤦

If part of the board's functionality is missing, please [open an issue](https://github.com/sparkfun/SparkFun_RTK_Postcard/issues) and file a feature request.

!!! tip "Design Considerations"
	Please keep in mind that we may intentionally exclude certain functions of the board to meet our product design requirements.

	- *For example, our Qwiic Micro boards are intended to fit on a small board layout and only use I^2^C communication; therefore, we may not have the SPI and interrupt pins available for users.*

### Do you wish to contribute directly to improving the board design?

1. With a GitHub account, [fork this repository](https://github.com/sparkfun/SparkFun_RTK_Postcard/fork).
2. Add your design augmentation(s)
3. File a pull request with your changes, and enjoy making the ~~words~~ ~~worlds~~ world a better place.
	1. Once received, the engineer in charge of the original design will automatically be notified.
	2. We will review your suggested improvement(s) to verify that they are within our board design standards and meet our product design requirements.
	3. If approved, we will flag these changes for our next board revision. Congrats! 🍻

		!!! info
			Even if your suggestion is accepted, these changes may not be immediately available for purchase. We may have to cycle through our current product inventory first.

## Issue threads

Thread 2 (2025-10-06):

Additional UART Pins on ESP32 Chip

jptalledo10, 2025-10-06:
Excellent board with RTK and a microprocessor in the same PCB. Wondering for field-deployment Wi-Fi and Bluetooth are limited but other Radios 900mHz or XBEE can be used, Does the ESP32 has spare pins or UART to accomodate an external RS-232 device? if so, can you point me which pins/UART?

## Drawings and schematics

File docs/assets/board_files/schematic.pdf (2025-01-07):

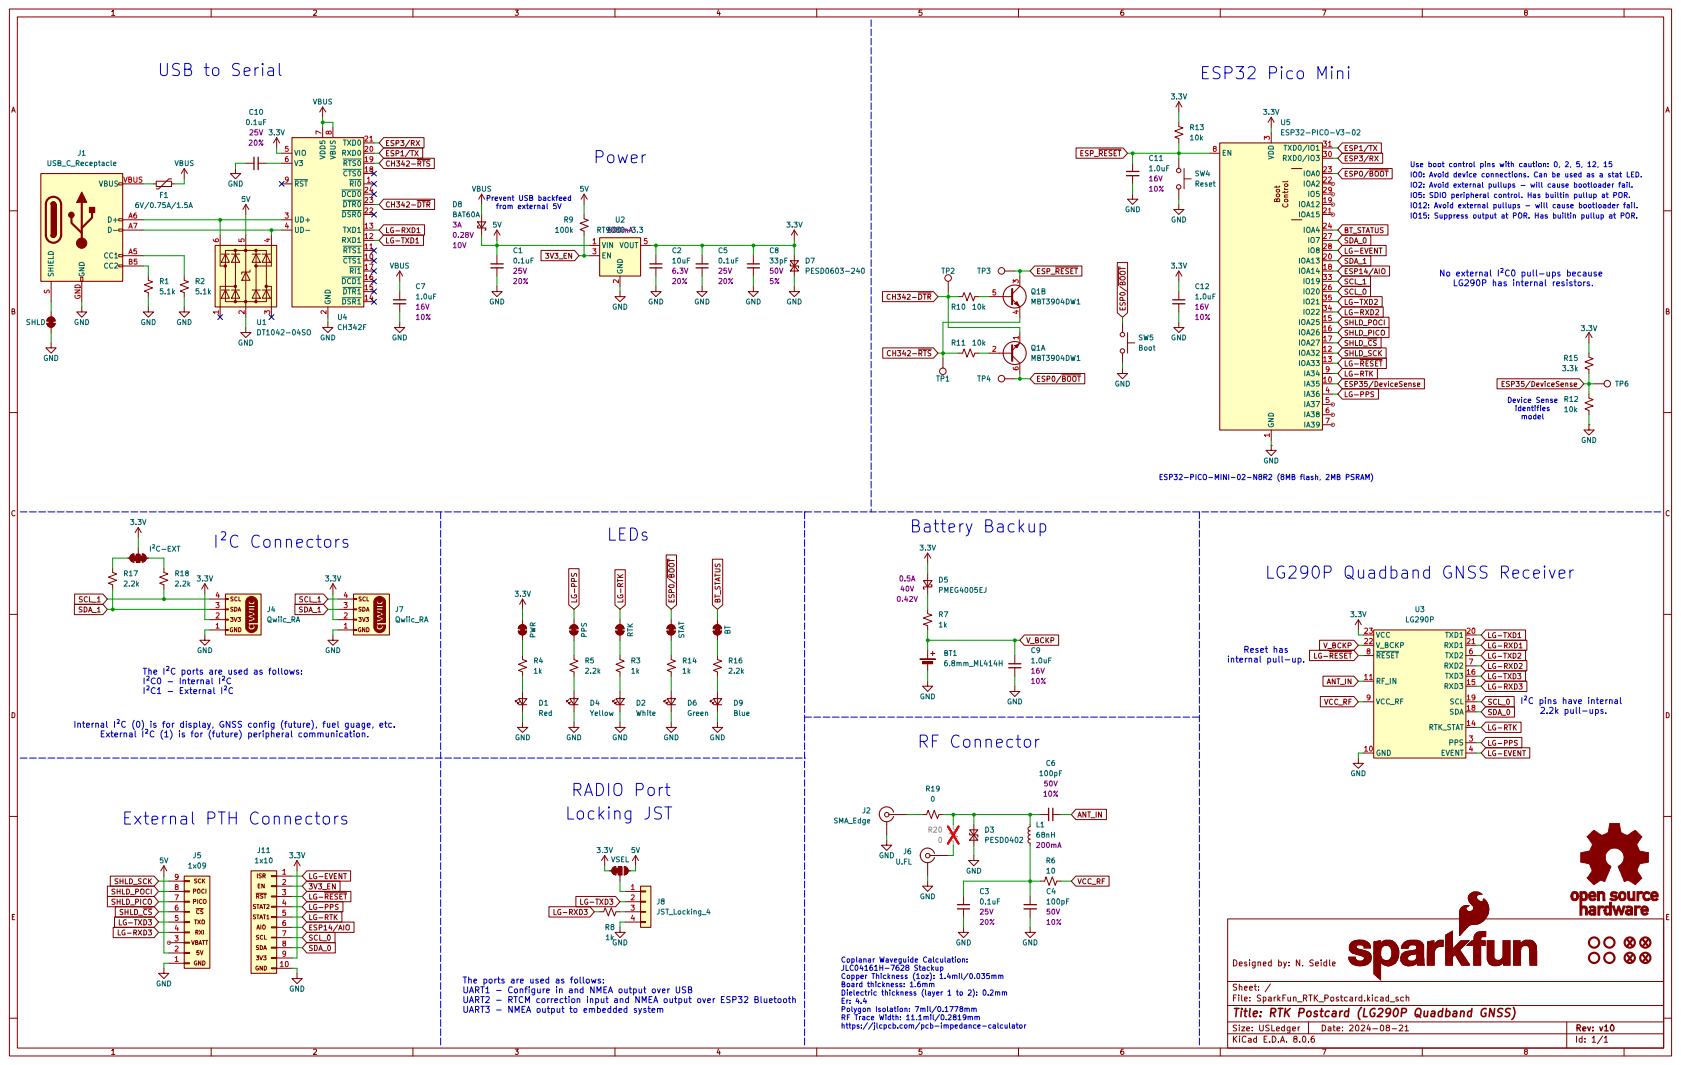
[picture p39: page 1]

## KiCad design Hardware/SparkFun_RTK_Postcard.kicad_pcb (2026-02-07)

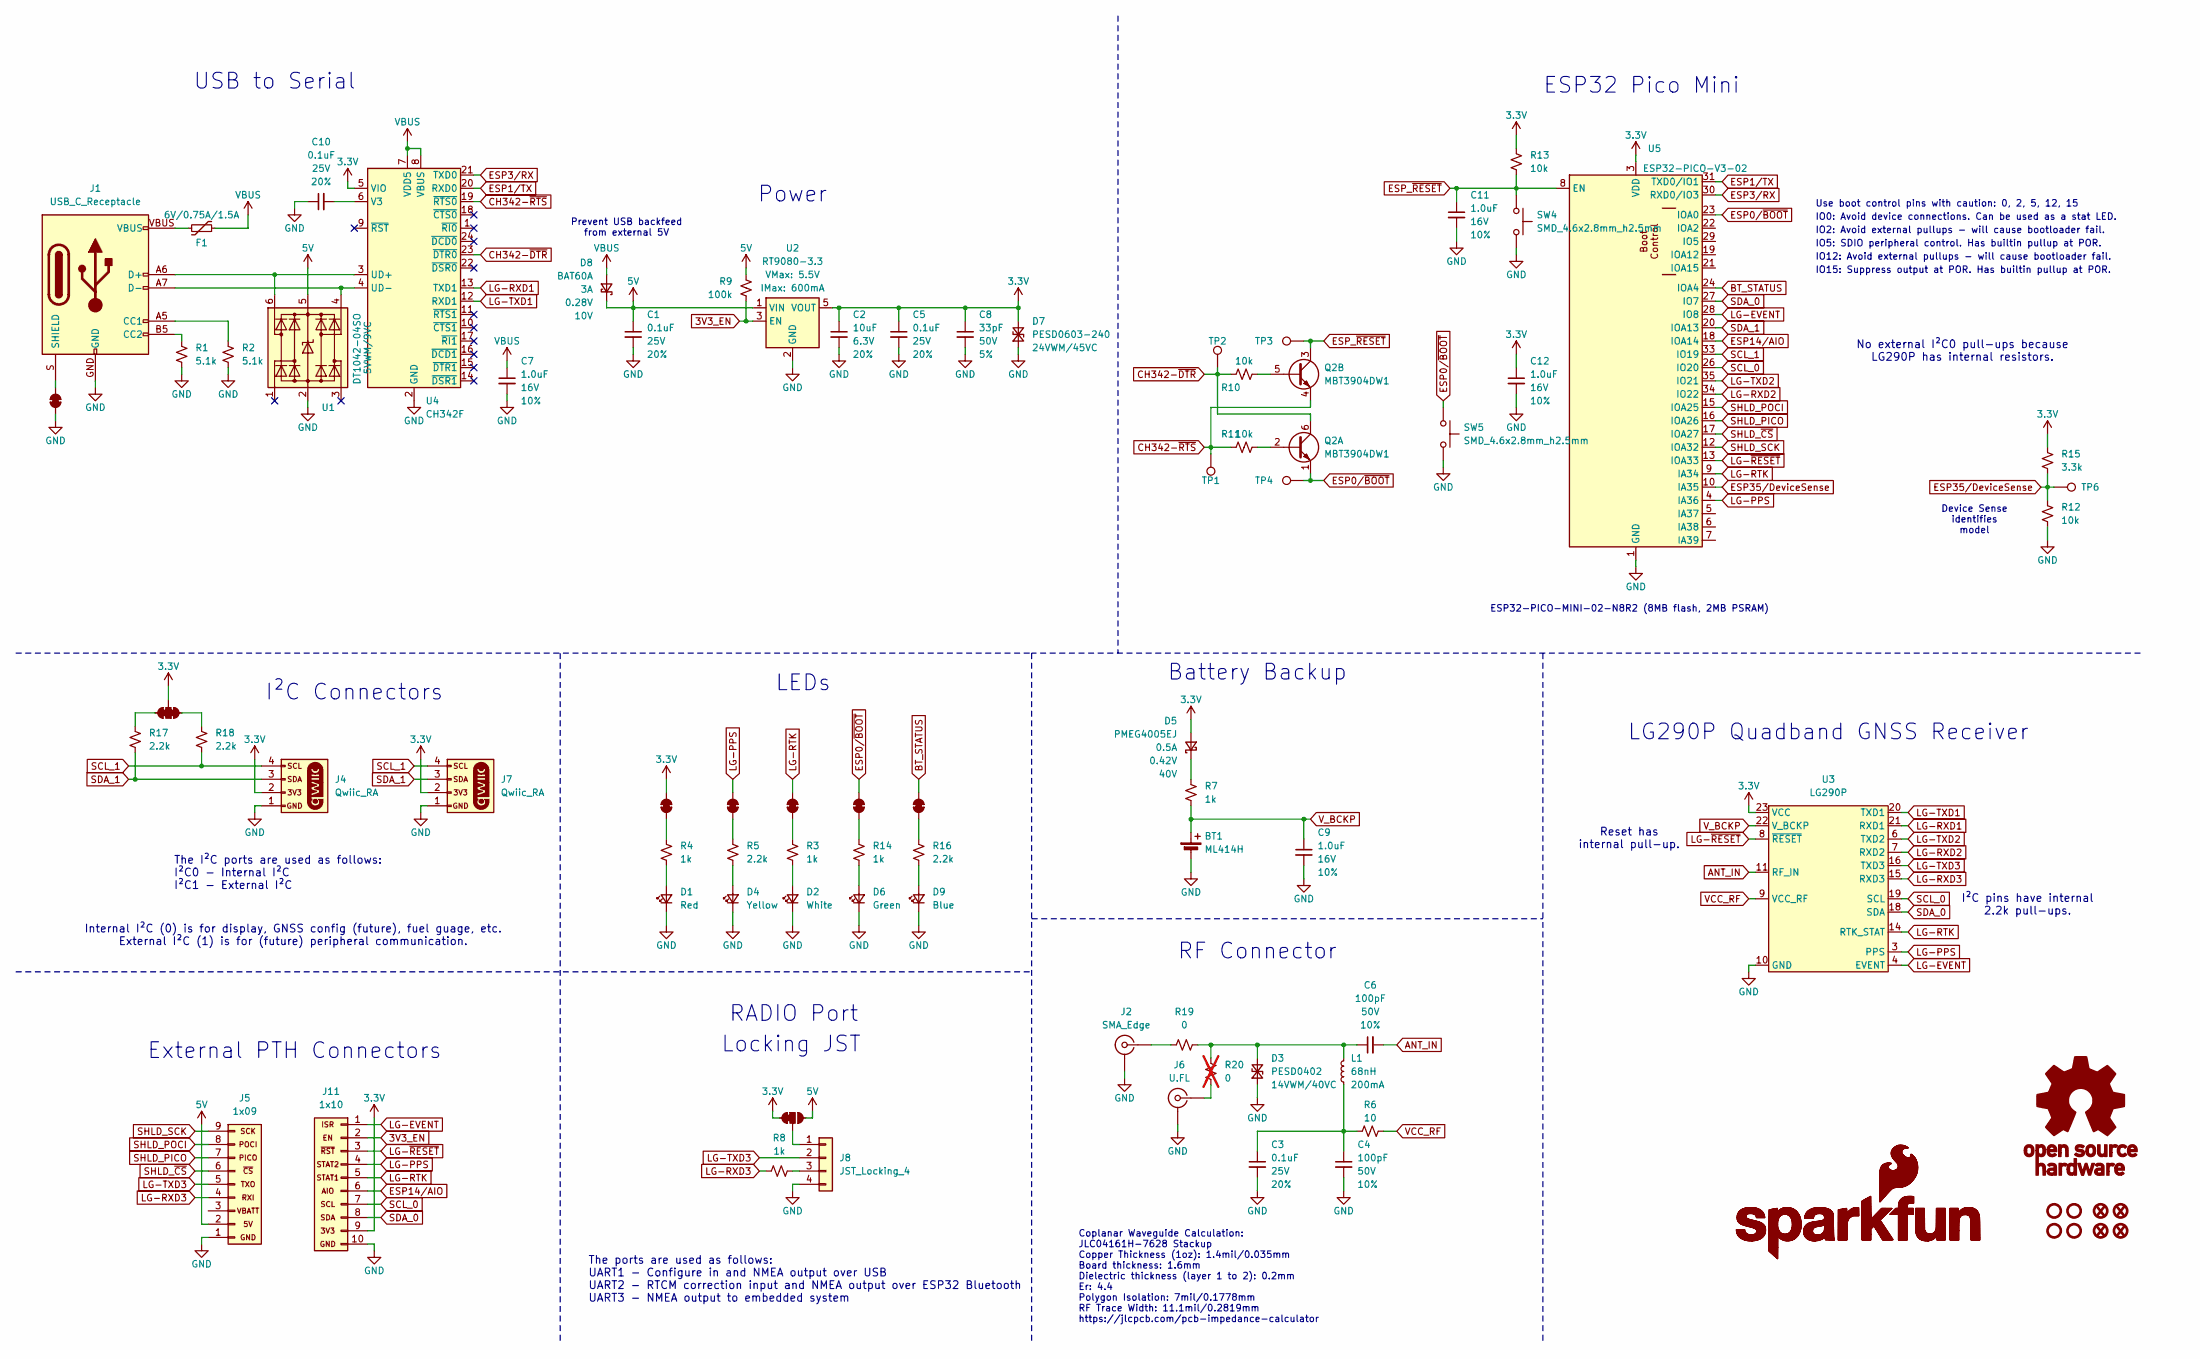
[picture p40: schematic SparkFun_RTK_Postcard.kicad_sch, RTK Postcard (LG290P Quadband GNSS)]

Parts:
BT1: ML414H; ML414H_IV01E
C1, C3, C5, C10: 0.1uF; C_0603_1608Metric; Voltage 25V; Tolerance 20%
C2: 10uF; C_0603_1608Metric; Voltage 6.3V; Tolerance 20%
C4: 100pF; C_0603_1608Metric; Voltage 50V; Tolerance 10%
C6: 100pF; C_0402_1005Metric; Voltage 50V; Tolerance 10%
C7, C9, C11, C12: 1.0uF; C_0603_1608Metric; Voltage 16V; Tolerance 10%
C8: 33pF; C_0603_1608Metric; Voltage 50V; Tolerance 5%
D1: Red; LED_0603_1608Metric_Red
D2: White; LED_0603_1608Metric_White
D3: PESD0402; C_0402_1005Metric; Rating 14VWM/40VC
D4: Yellow; LED_0603_1608Metric_Yellow
D5: PMEG4005EJ; SOD-323
D6: Green; LED_0603_1608Metric_Green
D7: PESD0603-240; C_0603_1608Metric; Rating 24VWM/45VC
D8: BAT60A; SOD-323
D9: Blue; LED_0603_1608Metric_Blue
F1: 6V/0.75A/1.5A; 1206
FID1, FID2, FID3, FID4: Fiducial_0.5mm; Fiducial_0.5mm_Mask1mm
G1: OSHW_Logo; Creative_Commons_License
G3, G5: SparkFun_Logo
J1: USB_C_Receptacle; USB-C_16
J2: SMA_Edge; SMA_Edge_8mm
J4, J7: Qwiic_RA; JST_1x04_P1.0mm_Horizontal_SMD
J5: 1x09; 1x09_P2.54mm
J6: U.FL
J8: JST_Locking_4; JST_1x04_P1.25mm_Locking_Horizontal_SMD
J11: 1x10; 1x10_P2.54mm
JP1, JP2, JP3, JP5, JP7, JP8: Jumper_2_NC_Trace
JP4: Jumper_3_NC-1_Trace
JP6: Jumper_3_NC-2_Trace
L1: 68nH; C_0402_1005Metric
Q2: MBT3904DW1; SOT-363_SC-70-6
R1, R2: 5.1k; R_0603_1608Metric
R3, R4, R7, R8, R14: 1k; R_0603_1608Metric
R5, R16, R17, R18: 2.2k; R_0603_1608Metric
R6: 10; R_0603_1608Metric
R9: 100k; R_0603_1608Metric
R10, R11, R12, R13: 10k; R_0603_1608Metric
R15: 3.3k; R_0603_1608Metric
R19: 0; R_0402_1005Metric
R20: 0; R_0402_1005Metric; not fitted
ST1, ST2, ST3, ST4: Standoff
SW4, SW5: SMD_4.6x2.8mm_h2.5mm; Push_SMD_4.6x2.8mm_h2.5mm
TP1, TP2, TP3, TP4, TP6: 1.0mm; TestPoint-1.0mm
U1: DT1042-04SO; SOT23-6; Rating 5VWM/9VC
U2: RT9080-3.3; SOT23-5
U3: LG290P; Quectel_LG290P
U4: CH342F; QFN-24-1EP_4x4mm_P0.5mm_EP2.7x2.7mm
U5: ESP32-PICO-V3-02; ESP32-PICO-MINI

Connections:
3.3V: C2.1, C5.1, C8.1, C12.1, D5.2 (A), D7.2 (A2), J4.2, J7.2, J11.9, JP2.2 (B), JP4.1 (A), JP6.2 (B), R13.2, R15.2, U2.5 (VOUT), U3.23 (VCC), U4.5 (VIO), U5.3 (VDD)
3V3_EN: J11.2, R9.1, U2.3 (EN)
5V: C1.1, D8.1 (K), J5.2, JP4.3 (C), R9.2, U1.5 (VCC), U2.1 (VIN)
ANT_IN: C6.2, U3.11 (RF_IN)
BT_STATUS: JP1.2 (B), U5.24 (IOA4)
CH342-~DTR: Q2.6 (C1), R10.1, TP2.1, U4.23 (~DTR0)
CH342-~RTS: Q2.4 (E2), R11.1, TP1.1, U4.19 (~RTS0)
ESP0/~BOOT: JP8.2 (B), Q2.1 (E1), SW5.1, TP4.1, U5.23 (IOA0)
ESP1/TX: U4.20 (RXD0), U5.31 (TXD0/IO1)
ESP3/RX: U4.21 (TXD0), U5.30 (RXD0/IO3)
ESP14/AIO: J11.6, U5.18 (IOA14)
ESP35/DeviceSense: R12.2, R15.1, TP6.1, U5.10 (IA35)
ESP_~RESET: C11.1, Q2.3 (C2), R13.1, SW4.1, TP3.1, U5.8 (EN)
GND: BT1.-, C1.2, C2.2, C3.2, C4.2, C5.2, C7.2, C8.2, C9.2, C10.1, C11.2, C12.2, D1.1 (K), D2.1 (K), D3.1 (A1), D4.1 (K), D6.1 (K), D7.1 (A1), D9.1 (K), J1.GND, J2.2 (Ext), J4.1, J5.1, J6.2 (Ext), J7.1, J8.4, J11.10, JP7.1 (A), R1.1, R2.1, R12.1, SW4.2, SW5.2, U1.2 (GND), U2.2 (GND), U3.10 (GND), U3.12 (GND), U3.13 (GND), U3.24 (GND), U3.25 (GND), U4.2 (GND), U4.25 (GND), U5.1 (GND), U5.2 (GND), U5.11 (GND), U5.14 (GND), U5.36 (GND), U5.37 (GND), U5.38 (GND), U5.39 (GND), U5.40 (GND), U5.41 (GND), U5.42 (GND), U5.43 (GND), U5.44 (GND), U5.45 (GND), U5.46 (GND), U5.47 (GND), U5.48 (GND), U5.49.1 (GND), U5.49.2 (GND), U5.49.3 (GND), U5.49.4 (GND), U5.49.5 (GND), U5.49.6 (GND), U5.49.7 (GND), U5.49.8 (GND), U5.49.9 (GND), U5.50 (GND), U5.51 (GND), U5.52 (GND), U5.53 (GND)
LG-EVENT: J11.1, U3.4 (EVENT), U5.28 (IO8)
LG-PPS: J11.4, JP3.2 (B), U3.3 (PPS), U5.4 (IA36)
LG-RTK: J11.5, JP5.2 (B), U3.14 (RTK_STAT), U5.9 (IA34)
LG-RXD1: U3.21 (RXD1), U4.13 (TXD1)
LG-RXD2: U3.7 (RXD2), U5.34 (IO22)
LG-RXD3: J5.4, R8.2, U3.15 (RXD3)
LG-TXD1: U3.20 (TXD1), U4.12 (RXD1)
LG-TXD2: U3.6 (TXD2), U5.35 (IO21)
LG-TXD3: J5.5, J8.2, U3.16 (TXD3)
LG-~RESET: J11.3, U3.8 (~RESET), U5.13 (IOA33)
unnamed: C3.1, C4.1, L1.1, R6.1
unnamed: D1.2 (A), R4.1
unnamed: D2.2 (A), R3.1
unnamed: C6.1, D3.2 (A2), L1.2, R19.1, R20.1
unnamed: D4.2 (A), R5.1
unnamed: D5.1 (K), R7.2
unnamed: D6.2 (A), R14.1
unnamed: D9.2 (A), R16.1
unnamed: F1.2, J1.VBUS
unnamed: J1.A5 (CC1), R2.2
unnamed: J1.B5 (CC2), R1.2
unnamed: J1.S (SHIELD), JP7.2 (B)
unnamed: J2.1 (In), R19.2
unnamed: J6.1 (In), R20.2
unnamed: J8.1, JP4.2 (B)
unnamed: J8.3, R8.1
unnamed: JP1.1 (A), R16.2
unnamed: JP2.1 (A), R4.2
unnamed: JP3.1 (A), R5.2
unnamed: JP5.1 (A), R3.2
unnamed: JP6.1 (A), R18.2
unnamed: JP6.3 (C), R17.2
unnamed: JP8.1 (A), R14.2
unnamed: Q2.2 (B1), R11.2
unnamed: Q2.5 (B2), R10.2
unnamed: J1.A7 (D-), J1.B7 (D-), U1.4 (I/O3), U4.4 (UD-)
unnamed: J1.A6 (D+), J1.B6 (D+), U1.6 (I/O4), U4.3 (UD+)
unnamed: C10.2, U4.6 (V3)
SCL_0: J11.7, U3.19 (SCL), U5.26 (IO20)
SCL_1: J4.4, J7.4, R18.1, U5.33 (IO19)
SDA_0: J11.8, U3.18 (SDA), U5.27 (IO7)
SDA_1: J4.3, J7.3, R17.1, U5.20 (IOA13)
SHLD_PICO: J5.7, U5.16 (IOA26)
SHLD_POCI: J5.8, U5.15 (IOA25)
SHLD_SCK: J5.9, U5.12 (IOA32)
SHLD_~CS: J5.6, U5.17 (IOA27)
VBUS: C7.1, D8.2 (A), F1.1, U4.7 (VDD5), U4.8 (VBUS)
VCC_RF: R6.2, U3.9 (VCC_RF)
V_BCKP: BT1.+, C9.1, R7.1, U3.22 (V_BCKP)

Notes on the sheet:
The I²C ports are used as follows: I²C0 - Internal I²C I²C1 - External I²C
ESP32-PICO-MINI-02-N8R2 (8MB flash, 2MB PSRAM)
I²C Connectors
IO15: Suppress output at POR. Has builtin pullup at POR.
Prevent USB backfeed from external 5V
The ports are used as follows: UART1 - Configure in and NMEA output over USB UART2 - RTCM correction input and NMEA output over ESP32 Bluetooth UART3 - NMEA output to embedded system
Use boot control pins with caution: 0, 2, 5, 12, 15
ESP32 Pico Mini
IO2: Avoid external pullups - will cause bootloader fail.
Internal I²C (0) is for display, GNSS config (future), fuel guage, etc. External I²C (1) is for (future) peripheral communication.
Reset has internal pull-up.
IO0: Avoid device connections. Can be used as a stat LED.
Coplanar Waveguide Calculation: JLC04161H-7628 Stackup Copper Thickness (1oz): 1.4mil/0.035mm Board thickness: 1.6mm Dielectric thickness (layer 1 to 2): 0.2mm Er: 4.4 Polygon Isolation: 7mil/0.1778mm RF Trace Width: 11.1mil/0.2819mm https://jlcpcb.com/pcb-impedance-calculator
I²C pins have internal 2.2k pull-ups.
Locking JST
Power
RF Connector
LEDs
LG290P Quadband GNSS Receiver
IO12: Avoid external pullups - will cause bootloader fail.
IO5: SDIO peripheral control. Has builtin pullup at POR.
RADIO Port
USB to Serial
Battery Backup
Device Sense identifies model
External PTH Connectors
No external I²C0 pull-ups because LG290P has internal resistors.

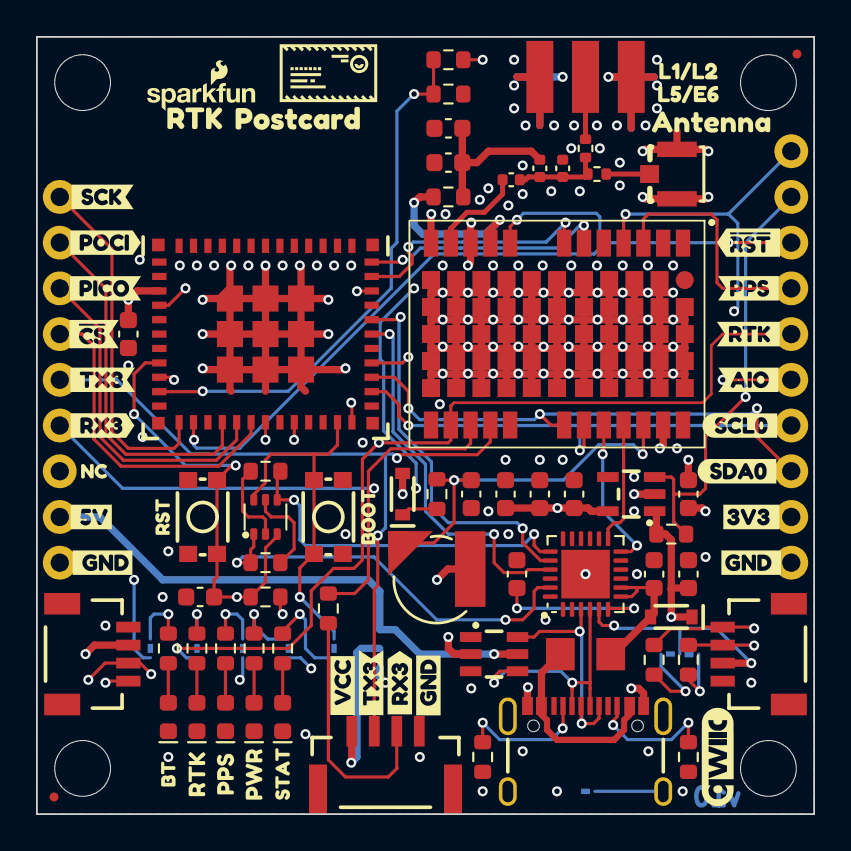
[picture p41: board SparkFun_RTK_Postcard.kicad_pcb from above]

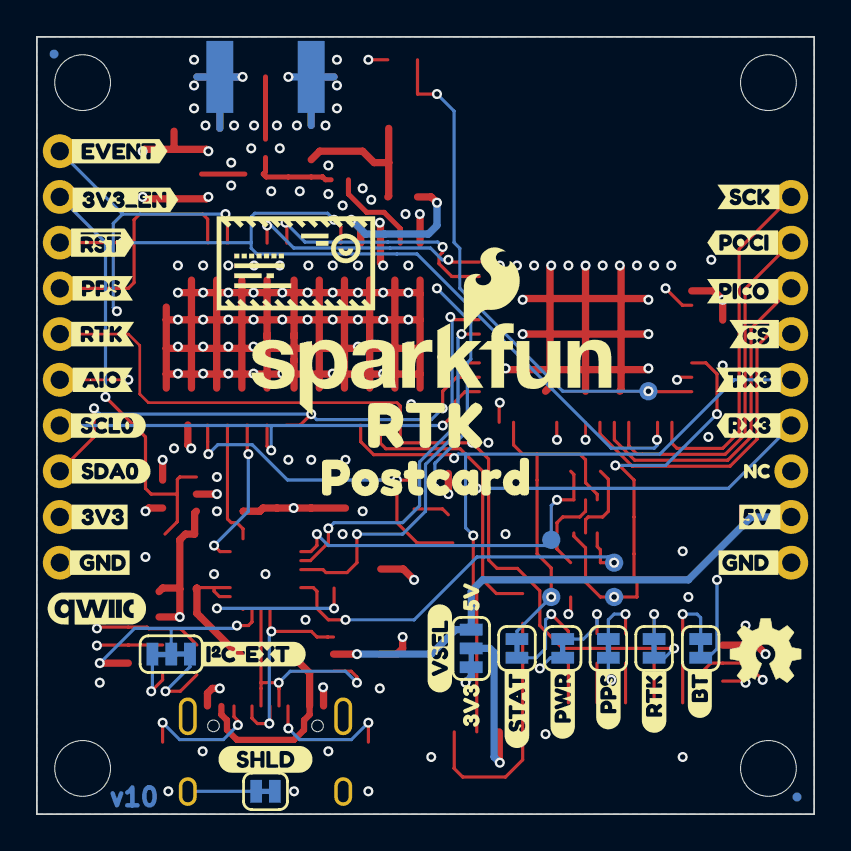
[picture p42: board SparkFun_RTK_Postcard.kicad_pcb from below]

Board: 4 copper layers, 43.2 x 43.2 mm, 147 parts (47 on the bottom side), 63 nets.

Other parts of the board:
Ref**: Val**; OSHW_Logo_4mm
kibuzzard-64C2E6A3: G***; kibuzzard-64C2E6A3
kibuzzard-64C2E6BD: G***; kibuzzard-64C2E6BD
kibuzzard-64C2E6D6: G***; kibuzzard-64C2E6D6
kibuzzard-64C2EB16: G***; kibuzzard-64C2EB16
kibuzzard-64C3DF93: G***; kibuzzard-64C3DF93
kibuzzard-66CB82FB: G***; kibuzzard-66CB82FB
kibuzzard-66CB829C: G***; kibuzzard-66CB829C
kibuzzard-66CB830B: G***; kibuzzard-66CB830B
kibuzzard-66E505A3: G***; kibuzzard-66E505A3
kibuzzard-66E5016F: G***; kibuzzard-66E5016F
kibuzzard-66E5059C: G***; kibuzzard-66E5059C
kibuzzard-66E50481: G***; kibuzzard-66E50481
kibuzzard-66E50489: G***; kibuzzard-66E50489
kibuzzard-66F2CCE8: G***; kibuzzard-66F2CCE8
kibuzzard-66F2CD12: G***; kibuzzard-66F2CD12
kibuzzard-66F2CD24: G***; kibuzzard-66F2CD24
kibuzzard-66F2CD30: G***; kibuzzard-66F2CD30
kibuzzard-66F31A0F: G***; kibuzzard-66F31A0F
kibuzzard-66F31A40: G***; kibuzzard-66F31A40
kibuzzard-66F31A48: G***; kibuzzard-66F31A48
kibuzzard-66F31A50: G***; kibuzzard-66F31A50
kibuzzard-66F31A58: G***; kibuzzard-66F31A58
kibuzzard-66F31A60: G***; kibuzzard-66F31A60
kibuzzard-66F31A71: G***; kibuzzard-66F31A71
kibuzzard-66F31A78: G***; kibuzzard-66F31A78
kibuzzard-66F31AC6: G***; kibuzzard-66F31AC6
kibuzzard-66F31AD0: G***; kibuzzard-66F31AD0
kibuzzard-66F31AE7: G***; kibuzzard-66F31AE7
kibuzzard-66F31B2D: G***; kibuzzard-66F31B2D
kibuzzard-66F31B4A: G***; kibuzzard-66F31B4A
kibuzzard-66F31B4F: G***; kibuzzard-66F31B4F
kibuzzard-66F31B16: G***; kibuzzard-66F31B16
kibuzzard-66F31B25: G***; kibuzzard-66F31B25
kibuzzard-66F31B33: G***; kibuzzard-66F31B33
kibuzzard-66F31D00: G***; kibuzzard-66F31D00
kibuzzard-66F318A4: G***; kibuzzard-66F318A4
kibuzzard-66F318AF: G***; kibuzzard-66F318AF
kibuzzard-66F318EE: G***; kibuzzard-66F318EE
kibuzzard-66F3185F: G***; kibuzzard-66F3185F
kibuzzard-66F3186F: G***; kibuzzard-66F3186F
kibuzzard-66F3187E: G***; kibuzzard-66F3187E
kibuzzard-66F3190E: G***; kibuzzard-66F3190E
kibuzzard-66F3194C, kibuzzard-66F3194C#2: G***; kibuzzard-66F3194C
kibuzzard-66F3756F: G***; kibuzzard-66F3756F
kibuzzard-66F31920: G***; kibuzzard-66F31920
kibuzzard-66F31933: G***; kibuzzard-66F31933
kibuzzard-66F31954, kibuzzard-66F31954#2: G***; kibuzzard-66F31954
kibuzzard-66F31960: G***; kibuzzard-66F31960
kibuzzard-66F31965, kibuzzard-66F31965#2: G***; kibuzzard-66F31965
kibuzzard-66F37583: G***; kibuzzard-66F37583
kibuzzard-672EE142: G***; kibuzzard-672EE142
kibuzzard-672EE156: G***; kibuzzard-672EE156
kibuzzard-672FC5C6: G***; kibuzzard-672FC5C6
kibuzzard-672FC5CC: G***; kibuzzard-672FC5CC
kibuzzard-672FC6B5: G***; kibuzzard-672FC6B5
kibuzzard-672FC715: G***; kibuzzard-672FC715
kibuzzard-672FC890: G***; kibuzzard-672FC890
kibuzzard-672FC894: G***; kibuzzard-672FC894
kibuzzard-673B9839, kibuzzard-673B9839#2: G***; kibuzzard-673B9839
kibuzzard-6724512A: G***; kibuzzard-6724512A

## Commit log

2024-09-25 Rotate silkscreen. Add AIO pin.
    [SparkFun_RTK_Postcard.kicad_pcb, SparkFun_RTK_Postcard.kicad_sch]
2024-11-09 Fix PPS. Add SMA. Change to 1.6mm. Add BT LED. Add I2C bus. Connect RST to LG290P..
    [SparkFun_RTK_Postcard.kicad_pcb, SparkFun_RTK_Postcard.kicad_sch]
2024-11-19 Add panel files
    [SparkFun_RTK_Postcard.kicad_pcb, SparkFun_RTK_Postcard.kicad_sch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]
2024-12-18 Add housing 3D file
    [SparkFun_RTK_Postcard.kicad_pcb, SparkFun_RTK_Postcard.kicad_sch]
2025-01-07 Update sch/pcb with smaller sch parts. Update prod panel with 10% paste reduction.
    [SparkFun_RTK_Postcard.kicad_pcb, SparkFun_RTK_Postcard.kicad_sch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]
2025-01-08 Create generate_documentation.yml
    Workflow to build and deploy the documentation using mkdocs-material theme
2025-01-23 Correct resistor package : 402 -> 0402
2025-07-09 Add LG290P firmware update
    Added a new section to the documentation detailing the firmware update process for the LG290P module, including references to the official upgrade manual, links to firmware resources, and specific instructions for the synchronization step using the QGNSS software reboot button. Also added a new image illustrating the reboot button.
2025-07-09 Update purchase link
    Revised the QR code and purchase button layout
2025-07-09 Fix indentation
    Removed unnecessary tab indentation for the QGNSS software download button
2025-09-12 Add v06 Test firmware
    New beta version for the PPP function, which includes several optimizations. It is now based on the latest 'v05' firmware. "Entering the PPP floating stage means that convergence has occurred."
2025-09-15 Remove directory
    Files were moved to the /docs/assets/component_documentation directory
    [Quectel_LG290P_3D_Dimensions_V1.0.stp]
2025-09-15 Update KiCAD files
    Updated file path, orientation, and location of footprints
    [SparkFun_RTK_Postcard.kicad_pcb]
2026-02-07 Update to v9 and current libraries.
    [SparkFun_RTK_Postcard.kicad_pcb, SparkFun_RTK_Postcard.kicad_sch]
2026-02-16 Added .step files for printing a thicker enclosure
    Notes: Thicker Housing Enclosures for the SparkFun RTK Postcard and Portability Shield combination
    There are two .step files (depending on how you connect the two modules):
    -------------------------
    Housing 2 v10 cc1-3.3mm.step (extra 3.3mm thick)
    - if soldering the two boards together with a set of male headers with just enough gap for a battery
    - the minimal thickness is a nice feature
    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
2026-06-03 Update troubleshooting_tips.md
    Add information about antenna capabilities

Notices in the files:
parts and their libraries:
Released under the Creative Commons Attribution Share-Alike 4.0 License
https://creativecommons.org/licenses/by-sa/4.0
